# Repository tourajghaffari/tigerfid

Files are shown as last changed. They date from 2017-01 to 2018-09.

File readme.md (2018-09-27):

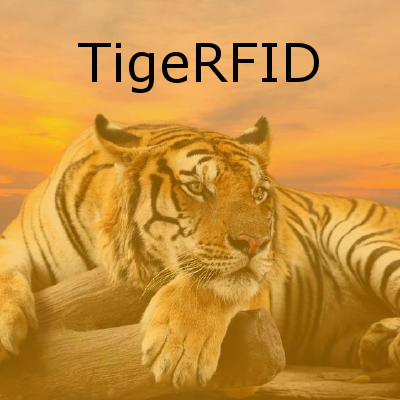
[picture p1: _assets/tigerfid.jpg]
TigeRFID

# TigeRFID

## Introduction

This repository has been created [in honor of our father](https://www.rfidjournal.com/articles/view?15751/), Touraj Ghaffari. He founded [ActiveWave, Inc.](http://www.activewaveinc.com/) in 2001. It was his life work and something he loved and enjoyed thoroughly. He also loved spreading knowledge. In honor of that principle, we, his three sons, have open-sourced everything associated with his active RFID system under the [Apache 2.0 license](license). We hope this release helps you acheive your dreams.

## What is this?

ActiveWave designed and built active RFID (Radio Frequency IDentification) products that work together to provide a new approach to tracking and security. The system includes the following features:

* Extended Read Range. A single RFID reader can cover up to 30,000 square feet of floor space.

* Multi-Tag Capability. Our tags employ anti-collision logic to assure each tag's information is read, even when multiple tags are attempting to transmit concurrently.

* Compact Low-Cost Design. Our exclusive design brings you the advantages of RFID technology, combined with long battery life and low cost.

* Simplified Installation. Our wireless device attachment capability simplifies the installation and interconnection of ActiveWave system components.

The [presentations](presentations) and [website](http://www.activewaveinc.com/) provide a great deal more detail - especially the [product datasheets](http://www.activewaveinc.com/products_datasheets.php).

## What is the project's current state?

This project is currently fully functional in its current state. The minimum system requirements are as follows:

1. One [Standard Reader](http://www.activewaveinc.com/products_datasht_standardreader.php) to both program the tags and read them.

2. At least one tag (the [sealTag](sealtag) and [compactTag](http://www.activewaveinc.com/products_datasht_compacttag.php) were the most popular).

3. Software options:

  1. Use the [API](api) to develop your own software; or,
  
  2. Use the [Programming Station](software/programming-station) to program tags and the [Smart Tracker](software/smart-tracker) to actually keep track of and monitor the tags.

The [Demo Kit](http://www.activewaveinc.com/products_datasht_demokit.php) included a few extra items: It included a [Standard Field Generator](http://www.activewaveinc.com/products_datasht_standardfieldgen.php) to demonstrate how to create zones within the range of the Reader as well as a motion detector to show how third-party devices can be integrated into the system as a whole through the use of the API.

## How can I get involved?

### Setup

1. Determine how you will configure your system. Remember the minimum system requirements listed above. As long as you have one Reader, one Tag, and either your own software using the [API](api) or the ActiveWave software suite ([Programming Station](software/programming-station) and [Smart Tracker](software/smart-tracker)), your system will work.

2. Use the [BOM files](bom-files) to figure out which parts you need.

3. Manufacture the parts using the [Protel files](protel-files). All the PCBs were designed using [Protel (now known as Altium)](http://www.altium.com/).

4. Share whatever improvements you make!

### Skillsets required

#### Software

* Programming with either C++ or C#

* Designing PCBs

#### Hardware

* Antenna design

* Radio frequency communication

* Soldering

### Assistance required

* We are looking for help to remove some of the old files. We included a few previous versions of each device in order to provide people with some history. We would like to remove all those older files and create a single-source-of-truth folder for each device.

* We are looking for help to improve documentation. In particular, we would like help to create a guide to stand-up a demo system based on the minimum requirements, a guide to manufacutre each device, and a guide to troubleshoot each device.

* We would like people's thoughts on whether the current structure is best or if it would be preferrable to have each device seperated out like the sealTag.

* We would like people's thoughts on the best way to display the BOMs. Should we convert them to markdown? Use a Google Sheet? Something else?

## Contents

1. [API](api) - Included are APIs for C++ .NET, C# .NET, C# .NET CE, and VB .NET. There is a manual for a Java-based API which we haven't yet found. There is also documentation - both for internal use and customers.

2. [BOM files](bom-files) - These are all the Bill Of Materials we could find. This should provide the different parts as well as costs associated with each based on the time they were made.

3. [Documentation](documentation) - These are documents, converted to Markdown, that were important enough for inclusion, but without a natural location that we could determine.

4. [Presentations](presentations) - These are the marketing materials that were sent to potential customers for a few different types of applications.

5. [Protel files](protel-files) - These are all the schematics and other related files that are required to actually manufacture the hardware.

6. [sealTag](sealtag) - One of the most versatile and popular tags of all, this was important enough to reside in its own section.

7. [Software](software) - This includes all the different applications required to actually run the system.

## Fun Touraj Fact

Touraj's favorite animal was the tiger - in particular, the [Caspian tiger](https://en.wikipedia.org/wiki/Caspian_tiger). Just like this project has arisen from extinction, the Caspian tiger should hopefully [make a triumphant return](http://www.bbc.co.uk/newsbeat/article/38663101/scientists-want-to-bring-cousin-of-extinct-caspian-tiger-to-central-asia) as well!

## Thank You

* Ali Amjadi

* Mehdi Haidari

* [Fabiano Kovalski](https://www.linkedin.com/in/fabianogk)

* [Vincent Mamo](https://www.linkedin.com/in/vincent-spinella-mamo-5262524)

* Reza Mokhtarzadeh

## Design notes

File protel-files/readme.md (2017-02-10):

# Protel Files

Using these files, you should be able to design the PCB associated with each device. Though this is probably the most important folder, we have never used Protel, so we are unsure as to the best way to provide you with some guidance. However, each folder should contain the schematics and files you need to begin manufacturing.

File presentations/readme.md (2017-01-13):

# Presentations

These are presentations that were used as educational materials to explain how the system worked.

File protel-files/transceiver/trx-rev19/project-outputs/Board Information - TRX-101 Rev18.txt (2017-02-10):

Board Information Report
Filename     : F:\PCBJOBS\ActiveWaveFiles May2009\TRX-101.REV18\PCB\TRX-101 Rev18.PcbDoc
Date         : 6/1/2009
Time         : 7:37:45 PM
Time Elapsed : 00:00:00

Plated Slot Size / Length, Pads
count : 0

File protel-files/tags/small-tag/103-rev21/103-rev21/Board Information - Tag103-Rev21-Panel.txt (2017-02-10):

Board Information Report
Filename     : C:\PCBJOBs\ActiveWave2010\Tag103.Rev21\Tag103-Rev21-Panel.PCB
Date         : 12/21/2010
Time         : 12:39:57 PM
Time Elapsed : 00:00:00

Routing Information
    Routing completion, 100.00%
    Connections, -44
    Connections routed, -44
    Connections remaing, 0
count : 4

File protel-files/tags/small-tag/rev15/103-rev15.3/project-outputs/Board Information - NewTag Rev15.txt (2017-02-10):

Board Information Report
Filename     : F:\PCBJOBS\ActiveWaveFiles 4-16-2008\Tag103 Rev15\Tag103 Rev15v3\NewTag Rev15.PCB
Date         : 4/30/2008
Time         : 9:52:25 PM
Time Elapsed : 00:00:00

Net Track Width, Count
    6mils, 42
count : 1

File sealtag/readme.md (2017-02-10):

# sealTag

This tag could be used for secure applications as well as any other application. It was the most popular tag of the group.

## Contents

### Host Software

This includes the software the host PC monitoring the sealTags will require.

### Protel Files

These are the files you'll need to use to actually create the PCB associated with the sealTag.

### Software

These are the applications as well as the firmware.

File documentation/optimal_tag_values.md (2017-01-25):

# Optimal Tag Values

**Note:** These are the values from testing each tag that resulted in an optimal result. We included the "Deprecated" portion in the event there was something from those old results that may be useful in the latest results. Eventually, we would hope to remove that sectionand leave only the latest optimal values.

## 868.92Mhz Tags

_05/12/2011_

### compactTag, 102 Rev 17

Variable | Value
--- | ---
C2 | 4.0pf
C7 | 220pf
C8 | 1000pf
C13 | 33pf
C19 | 3.0pf
C21 | 1.8pf or 2pf
L2 | 6.8nH
L4 | 12nH
L6 | 100nH
R17 | 1.3k ohms

### jumboTag, 105 Rev 17

Variable | Value
--- | ---
C2 | 2.2pf
C7 | 220pf
C8 | 1000pf
C13 | 33pf
C19 | 5.6pf
C21 | 1.8 or 2pf
L2 | 6.8nH or 8.2nH
L6 | 100nH
R17 | 1.3k ohms

### miniTag, Rev 20

Variable | Value
--- | ---
C2 | 2.4pf
C7 | 220pf
C13 | 33pf
C19 | 4.7pf
C21 | 1.8pf or 2pf
L1 | 15nH
L2 | 5.6nH
L6 | 100nH
R17 | 1.3k ohms
R24 | 150k ohms

## 867Mhz Tags (India)

_05/10/2011_

### compactTag, 102 Rev 17

Variable | Value
--- | ---
C2 | 4.0pf
C7 | 220pf
C8 | 10pf
C10 | 2700pf
C13 | 47pf
C19 | 3.0pf
C21 | 1.8pf or 2pf
L2 | 6.8nH
L4 | 12nH
L6 | 100nH
R17 | 1.3k ohms

### jumboTag, 105 Rev 17

Variable | Value
--- | ---
C2 | 2.2pf
C7 | 220pf
C8 | 1000pf
C10 | 1000pf
C13 | 33pf
C19 | 5.6pf
C21 | 6.0pf+
L2 | 6.8nH or 8.2nH
L6 | 100nH
R17 | 1.3k ohms

### miniTag, 103 Rev 20

Variable | Value
--- | ---
C2 | 2.4pf
C7 | 220pf
C8 | 10pf
C10 | 2700pf
C13 | 47pf
C19 | 4.7pf
C21 | 6pf or 7pf
L1 | 15nH
L2 | 5.6nH
L6 | 100nH
R17 | 1.3k ohms

## 916.5Mhz Tags

_05/12/2011_

### compactTag, 102 Rev 17

Variable | Value
--- | ---
C2 | 3.6pf
C7 | 220pf
C8 | 1000pf
C13 | 33pf
C19 | 2.7pf
C21 | 1.8pf or 2pf
L2 | 6.8nH
L4 | 12nH
L6 | 100nH
R17 | 1.3k ohms

### jumboTag, 105 Rev 17

Variable | Value
--- | ---
C2 | 2.7pf
C7 | 220pf
C8 | 1000pf
C13 | 33pf
C19 | 5.6pf
C21 | 1.8 or 2pf
L2 | 6.8nH or 8.2nH
L6 | 100nH
R17 | 1.3k ohms

### miniTag, Rev 20

Variable | Value
--- | ---
C2 | 1.5pf
C7 | 220pf
C8 | 1000pf
C13 | 33pf
C19 | 4.7pf
C21 | 1.8pf or 2pf
L2 | 5.6nH
L4 | 5.6nH
L6 | 100nH
R17 | 1.3k ohms
R24 | 150k ohms

## 927.2Mhz Tags

_05/12/2011_

### compactTag, 102 Rev 17

Variable | Value
--- | ---
C2 | 3.0pf
C7 | 220pf
C8 | 1000pf
C13 | 33pf
C19 | 2.4pf
C21 | 1.8pf or 2pf
L2 | 6.8nH
L4 | 12nH
L6 | 100nH
R17 | 1.3k ohms

### jumboTag, 105 Rev 17

Variable | Value
--- | ---
C2 | 2.7pf
C7 | 220pf
C8 | 1000pf
C13 | 33pf
C19 | 4.6pf
C21 | 1.8 or 2pf
L2 | 6.8nH or 8.2nH
L6 | 100nH
R17 | 1.3k ohms

### miniTag, 103 Rev 20

Variable | Value
--- | ---
C2 | 1.8pf
C7 | 220pf
C8 | 1000pf
C13 | 33pf
C19 | 3.0pf
C21 | 1.8pf or 2pf
L2 | 5.6nH
L4 | 5.6nH
L6 | 100nH
R17 | 1.3k ohms

## Special Notes

* **jumboTag and compactTag:** Add a 1M ohms resistor to the base of Q4 and the other side of the resistor goes to ground. This should increase the response time of the tag. Also, adding a 22uf cap - one side to the positive of the battery holder and the other side to ground - will increase the performance of the buzzer.

* **Tag 103:** To have a strong 433.92MHz signal, you need to change C7 from 100pf to 220pf (the change will get rid of the narrow signal) and L5 from 0.33uH to 100nH. For 868.92MHz tags, change C8 from 1000pf to 10pf and L1 to 15nH. For 916.5MHz and 868.92Mhz tags, change C19 to 4.7pf.

### Deprecated

#### 868.92MHz - cardTag, 101 Rev 13

Variable | Value
--- | ---
C2 | 2.7pf
C19 | 5.6pf
L2 | 6.8nH

#### 868.92MHz - jumboTag, 105 Rev 8

Variable | Value
--- | ---
C2 | 2.2pf
C7 | 220pf
C19 | 5.6pf
L2 | 6.8nH or 8.2nH
L6 | 100nH

#### 868.92MHz - miniTag, 103 Rev 8

Variable | Value
--- | ---
C2 | 1.8pf
C19 | 4.7pf
L1 | 2.7nH
L2 | 5.6nH

#### 916.5MHz - cardTag. 101

Variable | Value
--- | ---
C2 | 2.7pf
C19 | 5.6pf
L2 | 6.8nH

#### 916.5MHz - compactTag, 102

Variable | Value
--- | ---
C2 | 4.0pf
C19 | 3.0pf
L2 | 6.8nH
L4 | 12nH

#### 916.5MHz - jumboTag, 105

Variable | Value
--- | ---
C2 | 2.7pf
C7 | 220pf
C19 | 5.6pf
C21 | 1.8pf
L2 | 6.8nH or 8.2nH
L6 | 100nH

#### 916.5MHz - miniTag, Rev 8

Variable | Value
--- | ---
C2 | 2.7pf
C19 | 3.6pf
L1 | 2.7nH
L2 | 4.7nH

#### Special Notes

* **For tag 103 and metal surfaces:** Changing C2 from 2.7pf to 2.0pf, C19 from 3.6pf to 5.6pf, and L2 from 4.7nH to 5.6nH, the tag can work on metal with a wristband and it also increases the read range of the tag.

* **For tag 103 and a narrow signal:** Changing C7 from 100pf to 220pf, L6 from .33uH to 100nH, L1 to 15nH, while on 868.92Mhz, changing C8 to 10pfz, will allow you to have a strong 433.92 signal. It will also get rid of the narrow signal from receiver and give you a better and nicer shaped signal.

* **Reducing noise levels:** If you ever have a noise issue, adjust the threshold on R11 to reduce the noise level so we do not have any distraction from the Reader.

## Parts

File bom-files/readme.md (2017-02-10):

# BOM Files

This folder contains the most up-to-date Bill of Materials (BOM) files we could find. Each directory contains the BOM files we found associated with that particular device.

## Contents

### BOM Cost

These are the actual labor and parts costs associated with building each device.

### Compact Flash

These are the BOM files for the CF Reader. This device wasn't used towards the end of my father's life, so it may need some updating to work with the latest version of the other devices.

### Field Generator

These are the BOM files for each FGen, which operate as a repeater or extender (depending on how you configure your system).

### Handheld

These are the BOM files for the Handheld Reader devices. Much like the CF Reader, this may be best used with older versions of the tags and other readers.

### Misc

These are random BOM files we found in the root folder and are unsure as to whether they are the latest versions or not.

### Reader

These are the BOM files for the Readers. The medium-reader is most likely the best one to use as it was the most popular, but the standard-old-reader was used a bit as well.

### Tag

These are the BOMs for all the tags, including options.

### Transceiver

Unfortunately, we're not 100% sure what this is, but we know it is important. We believe it is something that must be built into the Readers, but again, we are unsure.

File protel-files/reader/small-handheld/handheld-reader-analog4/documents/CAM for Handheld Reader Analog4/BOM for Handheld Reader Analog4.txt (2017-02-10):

Bill Of Material For Handheld Reader Analog4.PCB
On 17-Sep-2004 at 15:36:35

 Comment             Pattern     Quantity  Components
------------------------------------------------------------------------------

 .001uF              0603             1    C41

 .1uF                0603            14    C2, C4, C5, C7, C8, C13, C14,
                                           C17, C18, C22, C26, C48, C50,
                                           C51

 .5 pF               0603             1    C20

 0.001uF             0603             1    C16

 0.18uH              0603             2    L6, L14

 0.22uF              0603             1    C15

 10                  0603             1    R16

 10 pF               0603             2    C30, C45

 10.7 Mhz Filter     FILTER           2    Y1, Y2

 100 nH              0603             2    L8, L11

 100 pF              0603             8    C6, C21, C27, C32, C34, C36,
                                           C44, C47

 100K                0603             2    R10, R31

 10K                 0603             4    R12, R38, R41, R49

 10uF                CAP A CASE       4    C10, C12, C52, C53

 150K                0603             1    R9

 15K                 0603             1    R47

 15nH                0603             1    L12

 18 nH               0603             1    L2

 180                 0603             1    R29

 1K                  0603             5    R8, R18, R26, R37, R48

 1N914               SOT23 DIODE      1    D1

 1X3 HEADER          1X3 HEADER       1    J4

 1uF                 CAP A CASE       1    C25

 2 pF                0603             1    C33

 2.2 mH              COIL 6.8UH       1    L4

 2.2K                0603             2    R21, R46

 22                  0603             4    R3, R20, R33, R43

 220 K               0603             1    R17

 27 pF               0603             1    C1

 2N3904              SOT23 TRANS      4    Q3, Q7, Q8, Q10

 2N3906              SOT23 TRANS      2    Q2, Q9

 3 pF                0603             1    C43

 3.3K                0603             1    R25

 33 nH               0603             1    L9

 33 pF               0603             3    C11, C19, C42

 330                 0603             1    R2

 330 nH              0805             1    L7

 39K                 0603             2    R15, R36

 3K                  0603             1    R24

 4.7K                0603             7    R14, R19, R22, R35, R40, R42,
                                           R51

 4.7nH               0603             1    L1

 433.92_Resonator    RESONATOR        1    Y4

 47 nH               0603             1    L10

 47 pF               0603             6    C28, C29, C37, C38, C39, C40

 470                 0603             1    R4

 4pF                 0603             1    C23

 5 PF                0603             1    C31

 5 pF                0603             1    C3

 56                  0603             1    R1

 560                 0603             2    R7, R27

 56K                 0603             1    R50

 5K POT              POT PANA EVN5     2    R6, R11

 5pF                 0603             1    C9

 6 pF                0603             1    C46

 6.8 nH              0603             1    L15

 6.8 uH              0805             1    L3

 6.8K                0603             2    R13, R34

 6.8k                0603             1    R23

 68                  0603             2    R30, R39

 7 PF                0603             1    C35

 905.8_Resonator     RESONATOR        1    Y3

 916.5_MHz Saw FilterRESONATOR        1    Y5

 916.5_Resonator     RESONATOR        1    Y6

 AT-113              SO8              1    U6

 BAR 65              DIODE SC79       1    D3

 BFR193              SOT23 TRANS      2    Q4, Q5

 BGA2001             SOT343           1    U1

 CON10               1X10 HEADER SPECIAL     1    J3

 CONN NEARSON NC-K01 CONN NEARSON NC-K01     2    J5, J6

 DS1804              SO8 SMALL        1    U5

 LMC555              SO8 SMALL        1    U9

 LMV821              SOT25            2    U4, U8

 Microstrip          MICROSTRIP       2    L5, L13

 NE85619             3 PIN ULTRA SUPER MINI MOLD     2    Q1, Q6

 SA636DK             SSOP20           1    U2

 TLV1391             SOT25            1    U3

 UPG52TA             TO6              1    U7

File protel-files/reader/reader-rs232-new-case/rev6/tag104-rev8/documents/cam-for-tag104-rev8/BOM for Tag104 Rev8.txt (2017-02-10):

Bill Of Material For Tag104 Rev8.PCB
On 29-Jul-2005 at 12:22:31

 Comment             Pattern     Quantity  Components
------------------------------------------------------------------------------

 0.1 uF              0603             4    C1, C15, C17, C24

 0.18 uH             0603             1    L3

 0.33 uH             0603             1    L6

 1 K                 0603             1    R20

 1 M                 0603             2    R1, R2

 10                  0603             2    R12, R13

 10 pF               0603             1    C4

 100 pF              0603             2    C6, C7

 1000 pF             0603             4    C8, C9, C10, C11

 1K                  0603             1    R21

 2 pF +/- .1 pf      0603             3    C2, C3, C21

 2.7 K               0603             2    R17, R18

 200                 0603             1    R22

 22                  0603             1    R6

 24AAXX              SO8              1    U4

 2N7002              SOT23 TRANS      1    Q4

 2N7002LT1           SOT23 TRANS      1    Q3

 3.3 nH              0603             1    L2

 33 pF               0603             1    C12

 33 pF +/- .1 pf     0603             1    C13

 330                 0603             1    R15

 39 K                0603             5    R3, R4, R5, R9, R10

 4.7 K               0603             2    R8, R19

 4.7 uF              CAP A CASE       1    C20

 470                 0603             1    R14

 470 K               0603             1    R16

 5 pF +/- .1 pF      0603             1    C19

 6.8 K               0603             1    R7

 68                  0603             1    R11

 916.5_Resonator     RESONATOR        1    Y1

 A3212               SOT23W           1    U7

 BATT HOLDER COIN CR2BATT HOLDER COIN CR2032 CUT     1    B1A

 DNS                 0603             2    C22, C23

 LED                 LED 0603         1    D1

 MIC862              SOT23-8          1    U6

 NE85619             3 PIN ULTRA SUPER MINI MOLD     2    Q1, Q2

 PIC16F648A          SSOP20 WIDE      1    U1

 TC1070              SOT23-5A         1    U5

 TC54                SOT23            1    U2

 TP                  TEST POINT PAD 5     4    J7, J9, J10, J11

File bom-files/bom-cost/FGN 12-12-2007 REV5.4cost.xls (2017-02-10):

FGN ASM-Sen-05.4
12/12/2007
Field Generator Rev 5.3
Item # |  | Part Status | Qty. | Price | Extended Cost | Labor Cost | Total Cost | Part Ref. | Value | Part Size | Description | Dist. | Distributor P/N | Manufacturer | Manufacturer P/N | Notes | Revision
1 |  | Basic | 1 | 0.011 | 0.014 | 0.080 | 0.094 | C31 | 100pF | 0603 | CAP 100PF 50V CERAMIC | Digi-Key | 445-1281-2-ND | TDK Corp | C1608C0G1H101J |  | 5.2
2 |  | Basic | 6 | 0.005 | 0.036 | 0.480 | 0.516 | C13, C21, C27, C28, C29, C30 | 0.1 uF | 0603 | CAP .10UF 25V CERAMIC Y5V 0603 | Digi-Key | 399-1100-2-ND | Kemet | C0603C104Z3VACTU |  | 5.2
3 |  | Basic | 2 | 0.057 | 0.137 | 0.160 | 0.297 | C11, C16 | 2.2uF 16V | CT3216 | CAPACITOR TANT 2.2UF 16V 10%, CASE A, SMD | Digi-Key | 399-3691-2-ND | Kemet | T491A225K016AT |  | 5.2
4 |  | Basic | 2 | 0.050 | 0.120 | 0.160 | 0.280 | C1, C2 | 4.7uF 16V | CT3216 | CAPACITOR TANT 4.7UF 16V 10%, CASE A, SMD | Digi-Key | 399-3697-2-ND | Kemet | T491A475K016AT |  | 5.2
5 |  | Basic | 1 | 0.015 | 0.018 | 0.080 | 0.098 | R29 | 33 | 0603 | RES 33 OHM 1/10W 5% | Digi-Key | RHM33GTR-ND | Rohm | MCR03EZPJ330 |  | 5.2
6 |  | Basic | 1 | 0.016 | 0.019 | 0.080 | 0.099 | R6 | 133 | 0603 | RES 133 OHM 1/10W 1% 0603 SMD | Digi-Key | RHM133HTR-ND | Rohm | MCR03EZPFX1330 |  | 5.2
7 |  | Basic | 3 | 0.001 | 0.005 | 0.240 | 0.245 | R8, R10, R14 | 2.2K | 0603 | RES 2.2K OHM 1/10W 5% 0603 SMD | Digi-Key | RHM2.2KGTR-ND | Rohm | MCR03EZPJ222 |  | 5.2
8 |  | Basic | 2 | 0.001 | 0.003 | 0.160 | 0.163 | R15,R21 | 10K | 0603 | RES 10K OHM 1/10W 5% 0603 SMD | Digikey | RHM10KGTR-ND | Rohm | MCR03EZPJ103 |  | 5.2
9 |  | Basic | 2 | 0.080 | 0.192 | 0.160 | 0.352 | FB2, FB3 | Ferrite Bead | 0603 | BEAD CORE 27 OHM 4A 0603 SMD | Digi-Key | P10436CT-ND | Panasonic-ECG | EXC-ML16A270U |  | 5.2
9 |  | Basic | 1 | 0.048 | 0.057 | 0.080 | 0.137 | L8 | 100nH | 0603 | INDUCTOR 100NH 5% 0603 SMD | Digi-Key | PCD1985TR-ND | Panasonic-ECG | ELJ-RER10JFA |  | 5.2
10 |  | Basic | 1 | 0.124 | 0.149 | 0.080 | 0.229 | D5 | Red LED | LED-T1 3mm | LED, RADIAL | Ptec | PL01CDR24 | Ptec | PL01CDR24 |  | 5.2
 |  |  |  |  | 0.000 | 0.000 | 0.000 |  |  | LED-T1 3mm | LED RED DIFFUSED 3MM ROUND | Digi-Key | P563-ND | Panasonic | LN28RPX |  | 5.2
11 |  | Basic | 1 | 0.300 | 0.359 | 0.080 | 0.439 | D4 | TRANSORB | DO-214AA (SMB) | SIDACTOR BI 25V 150A DO-214AA | Digi-Key | P0300SALRPTR-ND | Teccor Electronics Inc. (Sidactor) (http://www.digikey.com/scripts/Redirect/Redirect.dll?R=9&V=53) | P0300SALRP |  | 5.3
12 |  | Basic | 1 | 0.139 | 0.166 | 0.080 | 0.246 | D2 | Green LED | LED-T1 3mm | LED, RADIAL | Ptec | PL01-CDG-13 | Ptec | PL01-CDG-13 |  | 5.2
 |  |  |  |  | 0.000 | 0.000 | 0.000 |  |  | LED-T1 3mm | LED GREEN DIFFUSED 3MM ROUND | Digikey | P564-ND | Panasonic | LN38GPX |  | 5.2
13 |  | Basic | 1 | 0.054 | 0.065 | 0.080 | 0.145 | D6 | 1N4148 | SOD123 | DIODE SWITCH 75V 500MW MINIMELF | Digi-Key | LL4148DICT-ND | Diodes, Inc. | LL4148-13 |  | 5.2
14 |  | Basic | 1 | 0.144 | 0.172 | 0.080 | 0.252 | D12 | S1AB | DO-214AA (SMB) | DIODE FAST REC 50V 1A SMB | Digi-Key | RS1AB-FDITR-ND | Diodes, Inc. | RS1AB-13-F |  | 5.2
15 |  | Basic | 1 | 0.045 | 0.054 | 0.080 | 0.134 | Q1 | 2N3906 | SOT-23 | TRANS GP PNP -40V -200MA SOT-23 | Digi-Key | FMMT3906TR-ND | Zetex, Inc. | FMMT3906TA |  | 5.2
16 |  | Basic | 1 | 0.045 | 0.054 | 0.080 | 0.134 | Q3 | 2N3904 | SOT-23 | TRANS GP NPN 40V 200MA SOT-23 | Digi-Key | FMMT3904TR-ND | Zetex, Inc. | FMMT3904TA |  | 5.2
17 |  | Basic | 1 | 0.193 | 0.231 | 0.080 | 0.311 | U1 | NCP1117-ST50T3 | SOT223 | IC REG LDO 1A 5.0V SOT223 | Digi-key | NCP1117ST50T3GOS-ND | On Semiconductor | NCP1117ST50T3G |  | 5.2
18 |  | Basic | 1 | 0.700 | 0.838 | 0.080 | 0.918 | U5 | PIC16F690 | 20SSOP | IC MCU FLASH 4KX14 EEPROM | Digi-Key | PIC16F690-I/SS-ND | Microchip | PIC16F690-I/SS |  | 5.2
19 |  | Basic | 1 | 1.563 | 1.872 | 0.080 | 1.952 | U6 | MAX202 | SO-16 | IC TRANSCEIVER RS232 5V 16-SOIC | Arrow | MAX202CSE | Maxim | MAX202CSE |  | 5.2
20 |  | Basic | 0 |  | 0.000 | 0.000 | 0.000 | J3,J6 | DNP |  | 1x5 Header |  |  |  |  | Mask the HOLES | 5.2
21 |  | Basic | 1 | 2.113 | 2.531 | 0.080 | 2.611 | J4 | RJ11 | 6-6 modular | CONN MODULE 6-6 UNSHIELD SLEEVE | Digi-Key | CCM9002-ND | Corcom/Tyco | RJ11-6L-S | Please mask J6 holes | 5.2
22 |  | Basic | 1 | 1.410 | 1.689 | 0.080 | 1.769 | PCB |  |  |  |  |  | Active PCB | FGN-RAW-REV5 |  | 5.2
23 |  | Basic | 2 | 0.020 | 0.048 | 0.160 | 0.208 | Screw |  |  | SHEET MTL SCREW NO. 4 X 1/2"L, FLAT HD PHIL, ZINC PLTD STEEL |  |  | McMaster | 90048A110 |  | 5.2
24 |  | Basic | 1 |  | 0.000 | 0.080 | 0.080 | J9 | CONN HEADER RT ANG 2POS | 3.5mm | MC1,5/2-G-3,5 | Sager | 52285 | Phoenix Contact | 1844210 |  | 5.2
25 |  | Basic | 1 | 0.336 | 0.402 | 0.080 | 0.482 | J9A | Screw Type Plug 2POS | 3.5mm | MC1,5/2-ST-3,5 | Sager | 52229 | Phoenix Contact | 1840366 |  | 5.2
26 |  | Basic | 1 | 1.030 | 1.234 | 0.080 | 1.314 | F1 | 0451.200MRL | Surface Mount (0.240 X 0.106) | FUSE .200A 125V FAST NANO2 SMD | Digi-Key | 0451.200MRL-ND | Littelfuse Inc | 0451.200MRL |  | 5.2
 |  | Total |  | 8.500 | 10.463 | 3.040 | 13.503
27 | OPTD-0 | 433 MHZ | 0 |  | 0.000 | 0.000 | 0.000 | C3,C5,C6,C7,C8,C9,C10,C12,C14,C15,C18,C19,C20,C37,R1,R2,R3,R4,R5,R7,R9,R11,R17,R18,R19,R20,R22,L1,L2,L3,L4,L9,L10,L11,Q2,Q4,Q5,Q6,U2,Y2,J5,J8 | DNP |  |  |  |  |  |  |  | 5.2
28 | OPTD-1 | 433 MHz | 1 | 0.016 | 0.020 | 0.080 | 0.100 | C8 | 2.0 pF | 0603 | CAP CER 2.0PF, +/-0.25PF 50V C0G 0603 | Digi-Key | 490-1379-2-ND | Murata | GRM1885C1H2R0CZ01D |  | 5.2
29 | OPTD-1 | 433 MHz | 1 | 0.016 | 0.020 | 0.080 | 0.100 | C37 | 3.0 pF | 0603 | CAP CER 3.0PF,+/-0.25PF, 50V C0G 0603 | Digi-Key | 490-1383-2-ND | Murata | GRM1885C1H3R0CZ01D |  | 5.2
30 | OPTD-1 | 433 MHz | 2 | 0.016 | 0.039 | 0.160 | 0.199 | C19,C10 | 5.0 pF | 0603 | CAP CER 5.0PF, +/-0.25PF, 50V C0G 0603 | Digi-Key | 490-1390-2-ND | Murata | GRM1885C1H5R0CZ01D |  | 5.2
31 | OPTD-1 | 433 MHz | 1 | 0.016 | 0.020 | 0.080 | 0.100 | C14 | 7.0pF | 0603 | CAP CER 7.0PF, +/-0.5PF 50V C0G 0603 | Digi-Key | 490-1397-2-ND | Murata | GRM1885C1H7R0DZ01D |  | 5.2
32 | OPTD-1 | 433 MHz | 1 | 0.016 | 0.020 | 0.080 | 0.100 | C15 | 10pF | 0603 | CAP CER 10PF 50V 5% C0G 0603 | Digi-Key | 490-1403-2-ND | Murata | GRM1885C1H100JA01D |  | 5.2
33 | OPTD-1 | 433 MHz | 4 | 0.008 | 0.038 | 0.320 | 0.358 | C9 | 47pF | 0603 | CAP CER 47PF 50V C0G 5% 0603 | Digi-Key | 445-1277-2-ND | TDK Corp | C1608C0G1H470J |  | 5.2
34 | OPTD-1 | 433 MHz | 5 | 0.008 | 0.047 | 0.400 | 0.447 | C3, C5, C6, C7,C18 | 100pF | 0603 | CAP 100PF, 5%, 50V, COG, CERAMIC | Digi-Key | 445-1281-2-ND | TDK Corp | C1608C0G1H101J |  | 5.2
35 | OPTD-1 | 433 MHz | 1 | 0.005 | 0.006 | 0.080 | 0.086 | C20 | 0.1uF | 0603 | CAP .10UF 25V -20%, +80% CERAMIC Y5V 0603 | Digi-Key | 399-1100-2-ND | Kemet | C0603C104Z3VACTU |  | 5.2
36 | OPTD-1 | 433 MHz | 1 | 0.050 | 0.060 | 0.080 | 0.140 | C12 | 4.7uF 16V | CT3216 | CAPACITOR TANT 4.7UF 16V 10%, CASE A, SMD | Digi-Key | 399-3697-2-ND | Kemet | T491A475K016AT |  | 5.2
37 | OPTD-1 | 433 MHz | 1 | 0.015 | 0.018 | 0.080 | 0.098 | R17 | 10 | 0603 | RES 10 OHM 1/10W 5% 0603 SMD | Digi-Key | RHM10GTR-ND | Rohm | MCR03EZPJ100 |  | 5.2
38 | OPTD-1 | 433 MHz | 1 | 0.015 | 0.018 | 0.080 | 0.098 | R7 | 22 | 0603 | RES 22 OHM 1/10W 5% | Digi-Key | RHM22GTR-ND | Rohm | MCR03EZPJ220 |  | 5.2
39 | OPTD-1 | 433 MHz | 1 | 0.015 | 0.018 | 0.080 | 0.098 | R20 | 180 | 0603 | RES 180 OHM 1/10W 5% 0603 SMD | Digikey | RHM180GTR-ND | Rohm | MCR03EZPJ181 |  | 5.2
40 | OPTD-1 | 433 MHz | 1 | 0.001 | 0.002 | 0.080 | 0.082 | R22 | 270 | 0603 | RES 270 OHM 1/10W 5% 0603 SMD | Digikey | RHM270GTR-ND | Rohm | MCR03EZPJ271 |  | 5.2
41 | OPTD-1 | 433 MHz | 1 | 0.015 | 0.018 | 0.080 | 0.098 | R5 | 470 | 0603 | RES 470 OHM 1/10W 5% 0603 SMD | Digikey | RHM470GTR-ND | Rohm | MCR03EZPJ471 |  | 5.2
42 | OPTD-1 | 433 MHz | 1 | 0.015 | 0.018 | 0.080 | 0.098 | R11 | 1K | 0603 | RES 1.0K OHM 1/10W 5% 0603 SMD | Digikey | RHM1.0KGTR-ND | Rohm | MCR03EZPJ102 |  | 5.2
43 | OPTD-1 | 433 MHz | 1 | 0.015 | 0.018 | 0.080 | 0.098 | R4 | 2.2K | 0603 | RES 2.2K OHM 1/10W 5% 0603 SMD | Digi-Key | RHM2.2KGTR-ND | Rohm | MCR03EZPJ222 |  | 5.2
44 | OPTD-1 | 433 MHz | 1 | 0.015 | 0.018 | 0.080 | 0.098 | R18 | 3.3K | 0603 | RES 3.3K OHM 1/10W 5% 0603 SMD | Digi-Key | RHM3.3KGTR-ND | Rohm | MCR03EZPJ332 |  | 5.2
45 | OPTD-1 | 433 MHz | 1 | 0.001 | 0.002 | 0.080 | 0.082 | R19 | 1.8k | 0603 | RES 1.8K OHM 1/10W 5% 0603 SMD | Digi-Key | RHM1.8KGTR-ND | Rohm | MCR03EZPJ182 |  | 5.2
46 | OPTD-1 | 433 MHz | 2 | 0.015 | 0.035 | 0.160 | 0.195 | R1, R2 | 4.7K | 0603 | RES 4.7K OHM 1/10W 5% 0603 SMD | Digi-Key | RHM4.7KGTR-ND | Rohm | MCR03EZPJ472 |  | 5.2
47 | OPTD-1 | 433 MHz | 1 | 0.003 | 0.004 | 0.080 | 0.084 | R3 | 8.2k | 0603 | RES 8.2K OHM 1/10W 5% 0603 SMD | Digi-Key | RHM8.2KGTR-ND | Rohm | MCR03EZPJ822 |  | 5.2
48 | OPTD-1 | 433 MHz | 1 | 0.563 | 0.674 | 0.080 | 0.754 | R9 | 10K POT | 9mm Squared | POT 10K OHM SQ CERMET SIDE | Digi-Key | CT94EZ103-ND | copal-electronics | CT94EZ103 |  | 5.2
49 | OPTD-1 | 433 MHz | 2 | 0.034 | 0.081 | 0.160 | 0.241 | L1,L11 | 6.8nH | 0603 | INDUCTOR 6.8NH 5% 0603 SMD | Digi-Key | PCD1971TR-ND | Panasonic | ELJ-RE6N8JFA |  | 5.2
50 | OPTD-1 | 433 MHz | 1 | 0.048 | 0.057 | 0.080 | 0.137 | L4 | 22nH | 0603 | INDUCTOR 22NH 5% 0603 SMD | Digi-Key | PCD1977TR-ND | Panasonic | ELJ-RE22NJFA |  | 5.2
51 | OPTD-1 | 433 MHz | 1 | 0.048 | 0.057 | 0.080 | 0.137 | L9 | 47nH | 0603 | INDUCTOR 47NH 5% 0603 SMD | Digi-Key | PCD1981TR-ND | Panasonic-ECG | ELJ-RE47NJFA |  | 5.2
52 | OPTD-1 | 433 MHz | 2 | 0.034 | 0.081 | 0.160 | 0.241 | L2,L3 | 100nH | 0603 | INDUCTOR 100NH 5% 0603 SMD | Digi-Key | PCD1985TR-ND | Panasonic-ECG | ELJ-RER10JFA |  | 5.2
53 | OPTD-1 | 433 MHz | 1 | 0.170 | 0.204 | 0.080 | 0.284 | L10 | 330nH | 0603 | INDUCTOR MULTILAYER 0.33UH 1608 | Digi-Key | 445-1009-2-ND | TDK Corporation | MLF1608DR33K |  | 5.3
54 | OPTD-1 | 433 MHz | 1 | 0.045 | 0.054 | 0.080 | 0.134 | Q4 | 2N3906 | SOT-23 | TRANS GP PNP -40V -200MA SOT-23 | Digi-Key | FMMT3906TR-ND | Zetex, Inc. | FMMT3906TA |  | 5.2
55 | OPTD-1 | 433 MHz | 2 | 0.120 | 0.287 | 0.160 | 0.447 | Q2,Q6 | BFR193 | SOT23 | TRANSISTOR RF NPN 12V SOT-23 | Digi-Key | BFR 193 E6327-ND | Infineon | BFR 193 E6327 |  | 5.2
56 | OPTD-1 | 433 MHz | 1 | 0.045 | 0.054 | 0.080 | 0.134 | Q5 | 2N3904 | SOT-23 | TRANS GP NPN 40V 200MA SOT-23 | Digi-Key | FMMT3904TR-ND | Zetex, Inc. | FMMT3904TA |  | 5.2
57 | OPTD-1 | 433 MHz | 1 |  | 0.000 | 0.080 | 0.080 | U2 | AT-113 | SO8 | 3 Volt Voltage Variable Absorptive Attenuator | Future | 6219539 | MCM | AT-113TR |  | 5.2
58 | OPTD-1 | 433 MHz | 1 | 0.520 | 0.623 | 0.080 | 0.703 | Y2 | 433.92MHz | 3.8 X 3.8 MM | 40 dB, 0.5-2.0 GHz | RF Monolithics | RO2101D | RF Monolithics | RO2101D |  | 5.2
59 | OPTD-1 | 433 MHz | 2 | 0.056 | 0.133 | 0.160 | 0.293 | Shunt (J5,J8) | 2 Position |  | SHUNT, ECON, PHBR 5AU, BLACK | Digi-Key | A26228-ND | AMP/Tyco | 382811-8 |  | 5.2
60 | OPTD-1 | 433 MHz | 1 | 0.663 | 0.794 | 0.080 | 0.874 | J5 | 1X3 Header |  | CONN HEADER .100 SINGL STR 36POS | Digi-Key | S1011E-36-ND | Sullins Elec. | PBC36SAAN | One of these Sullins parts makes 12 3-pin headers | 5.2
61 | OPTD-1 | 433 MHz | 1 | 0.663 | 0.794 | 0.080 | 0.874 | J8 | 1X2 Header |  | CONN HEADER .100 SINGL STR 36POS | Digi-Key | S1011E-36-ND | Sullins Elec. | PBC36SAAN | One of these Sullins parts makes 18 2-pin headers | 5.2
 |  | Total |  | 3.283 | 4.327 | 3.760 | 8.087
62 | OPTD-1 | OPTM-2 | 1 |  | 0.000 | 0.080 | 0.080 | Enclouser | Box-ENC-102-2110100 |  | Box 12cm x 6.9cm x 2.5cm, Black Color, ActiveWave Logo,Hole in Top Left Position Option, Hole in Top Right, Hole on Left Side,No Two Ultrasonic holes on the Top Right, No hole on the Right Side |  |  | Advanced Data Access Inc/ ActiveWave Inc | Box-ENC-102-2110100 |  | 5.2
63 | OPTD-1 | OPTM-3 | 1 |  | 0.000 | 0.080 | 0.080 | Enclouser | Box-ENC-102-3110100 |  | Box 12cm x 6.9cm x 2.5cm, Silver Color, ActiveWave Logo,Hole in Top Left Position Option, Hole in Top Right, Hole on Left Side,No Two Ultrasonic holes on the Top Right, No hole on the Right Side |  |  | Advanced Data Access Inc/ ActiveWave Inc | Box-ENC-102-3110100 |  | 5.2
64 | OPTD-1 | OPTM-4 | 1 |  | 0.000 | 0.080 | 0.080 | Enclouser | Box-ENC-102-4110100 |  | Box 12cm x 6.9cm x 2.5cm, Beige Color, ActiveWave Logo,Hole in Top Left Position Option, Hole in Top Right, Hole on Left Side,No Two Ultrasonic holes on the Top Right, No hole on the Right Side |  |  | Advanced Data Access Inc/ ActiveWave Inc | Box-ENC-102-4110100 |  | 5.2
65 | OPTD-1 | OPTM-5 | 1 |  | 0.000 | 0.080 | 0.080 | Enclouser | Box-ENC-102-5110100 |  | Box 12cm x 6.9cm x 2.5cm, Custom Color, ActiveWave Logo,Hole in Top Left Position Option, Hole in Top Right, Hole on Left Side,No Two Ultrasonic holes on the Top Right, No hole on the Right Side |  |  | Advanced Data Access Inc/ ActiveWave Inc | Box-ENC-102-5110100 |  | 5.2
 |  |  |  |  | 0.000 | 0.000 | 0.000 |  |  |  |  |  |  |  |  |  | 5.2
66 | OPTE-0 | 433-EXT-ANT | 0 |  | 0.000 | 0.000 | 0.000 | J7 | DNP |  |  |  |  |  |  |  | 5.2
67 | OPTE-1 | 433-EXT-ANT | 1 | 2.087 | 2.500 | 0.080 | 2.580 | J7 | PCB Mount | SMA Reverse | CONNECTOR RPSMA PCB MOUNT | Digi-Key | CONREVSMA001-ND | Linx Tech. | CONREVSMA001 |  | 5.2
68 | OPTE-1 | 433-EXT-ANT | 1 | 5.220 | 6.251 | 0.080 | 6.331 | J7-Antenna | 50 OHM ANT | SMA Reverse | ANTENNA 433MHZ 1/4 WAVE WHIP | Digi-Key | ANT-433-CW-HD-ND | Linx Tech. | ANT-433-CW-HD | OPTION J-3 OR OPTION K-3? | 5.2
 |  | total |  | 7.307 | 8.751 | 0.160 | 8.911 |  |  |  |  |  |  |  |  |  | 5.2
69 | OPTF-0 | INT Sensor | 0 |  | 0.000 | 0.000 | 0.000 | C54,C55,C56,C57,C58,C59,C60,C61,C62,R13,R47,R51,R54,R55,R57,R58,L16,L17,Q7,U3,SEN1,SEN2,P1,P2,J1 | DNP |  |  |  |  |  |  |  | 5.3
70 | OPTF-1 | INT Sensor | 1 | 0.011 | 0.014 | 0.080 | 0.094 | C55 | 47pF | 0603 | CAP CER 47PF 50V C0G 5% 0603 | Digi-Key | 445-1277-2-ND | TDK Corp | C1608C0G1H470J |  | 5.2
71 | OPTF-1 | INT Sensor | 1 | 0.011 | 0.013 | 0.080 | 0.093 | C58 | 0.01uF | 0603 | CAP CERM .01UF 10% 50V X7R 0603 | Digi-Key | 478-1227-2-ND | AVX Corporation (http://www.digikey.com/scripts/Redirect/Redirect.dll?R=9&V=478) | 06035C103KAT2A |  | 5.2
72 | OPTF-1 | INT Sensor | 3 | 0.005 | 0.018 | 0.240 | 0.258 | C56,C57,C62 | 0.1uF | 0603 | CAP .10UF, -20/+80%, 25V ,CERAMIC Y5V 0603 | Digi-Key | 399-1100-2-ND | Kemet | C0603C104Z3VACTU |  | 5.2
73 | OPTF-1 | INT Sensor | 2 | 0.018 | 0.043 | 0.160 | 0.203 | C54,C61 | 1 uF 50V | 0805 | CAP CER 1UF, -20/+80%, 50V Y5V 0805 | Digi-Key | 490-3903-2-ND | Murata | GRM21BF51H105ZA12L |  | 5.2
74 | OPTF-1 | INT Sensor | 1 | 0.135 | 0.162 | 0.080 | 0.242 | C59 | 100uF 16V | 7343-31 (EIA) | CAP TANT 100UF 16V 10% SMD CASE D SMD | Digi-Key | 718-1057-2-ND | Vishay | 293D107X9016D2TE3 |  | 5.2
75 | OPTF-1 | INT Sensor | 1 | 0.001 | 0.002 | 0.080 | 0.082 | R13 | 1K | 0603 | RES 1.0K OHM 1/10W 5% 0603 SMD | Digikey | RHM1.0KGTR-ND | Rohm | MCR03EZPJ102 |  | 5.2
76 | OPTF-1 | INT Sensor | 4 | 0.015 | 0.070 | 0.320 | 0.390 | R54,R55,R57,R58 | 1K | 1206 | RES 1.0K OHM 1/4W 5% 1206 SMD | Digikey | RHM1.0KETR-ND | Rohm | MCR18EZHJ102 |  | 5.2
77 | OPTF-1 | INT Sensor | 1 | 0.015 | 0.018 | 0.080 | 0.098 | R47 | 4.7K | 0603 | RES 4.7K OHM 1/10W 5% 0603 SMD | Digi-Key | RHM4.7KGTR-ND | Rohm | MCR03EZPJ472 |  | 5.2
78 | OPTF-1 | INT Sensor | 1 | 0.563 | 0.674 | 0.080 | 0.754 | R51 | 100K | 0603 | RES 100K OHM 1/10W 5% 0603 SMD | Digi-Key | RHM100KGCT-ND | Rohm | MCR03EZPJ104 |  | 5.2
79 | OPTF-1 | INT Sensor | 2 | 0.563 | 1.349 | 0.160 | 1.509 | L16,L17 | Ferrite Bead | 0603 | BEAD CORE 27 OHM 4A 0603 SMD | Digi-Key | P10436CT-ND | Panasonic-ECG | EXC-ML16A270U |  | 5.3
80 | OPTF-1 | INT Sensor | 1 | 0.001 | 0.002 | 0.080 | 0.082 | Q7 | FMMT491ATC | SOT-23 | TRANSISTOR NPN MED PWR SOT23 | Digi-Key | FMMT491ATC-ND | Zetex Inc | FMMT491ATC |  | 5.2
81 | OPTF-1 | INT Sensor | 1 | 1.870 | 2.240 | 0.080 | 2.320 | U3 | CYC271434 | 8-DIP | IC MCU 16K FLASH 256B SRAM 8-DIP | Digi-Key | 428-1593-ND | Cypress SemiconductorCorp | CY8C27143-24PXI |  | 5.2
82 | OPTF-1 | INT Sensor | 1 | 0.154 | 0.184 | 0.080 | 0.264 | U3-Socket | Socket | Sockets for ICs, Transistors | CONN IC SOCKET 8POS DIP TIN | Digi-Key | A24807-ND | Tyco Electronics/Amp (http://www.digikey.com/scripts/Redirect/Redirect.dll?R=9&V=17) | 2-641260-1 |  | 5.2
83 | OPTF-1 | INT Sensor | 1 | 0.800 | 0.958 | 0.080 | 1.038 | SENS1 | 40T-16P | ULTRASONIC SENSOR | Ceramic Transponder 40T-16P |  |  | CERAMIC TRANSDUCER DESIGN CO., LTD | 40T-16P |  | 5.2
84 | OPTF-1 | INT Sensor | 1 | 0.080 | 0.096 | 0.080 | 0.176 | SENS2 | 40R-16P | ULTRASONIC SENSOR | Ceramic Transponder 40R-16P |  |  | CERAMIC TRANSDUCER DESIGN CO., LTD | 40R-16P |  | 5.2
85 | OPTF-1 | INT Sensor | 0 | 0.313 | 0.000 | 0.000 | 0.000 | P1 | DNP |  |  |  |  |  |  | Mask the HOLES, S/B DNP | 5.2
86 | OPTF-1 | INT Sensor | 0 | 0.082 | 0.000 | 0.000 | 0.000 | P2 | DNP |  |  |  |  |  |  | Mask the HOLES, S/B DNP | 5.2
 |  | total |  | 4.637 | 5.841 | 1.760 | 7.601
87 | OPTF-1 | OPTM-2 | 1 |  | 0.000 | 0.080 | 0.080 | Enclouser | Box-ENC-102-2110111 |  | Box 12cm x 6.9cm x 2.5cm, Black Color, ActiveWave Logo,Hole in Top Left Position Option, No Hole in Top Right, Hole on Left Side, Two Ultrasonic holes on the Top Right, Hole on the Right Side |  |  | Advanced Data Access Inc/ ActiveWave Inc | Box-ENC-102-2110111 |  | 5.2
88 | OPTF-1 | OPTM-3 | 1 |  | 0.000 | 0.080 | 0.080 | Enclouser | Box-ENC-102-3110111 |  | Box 12cm x 6.9cm x 2.5cm, Silver Color, ActiveWave Logo,Hole in Top Left Position Option, No Hole in Top Right, Hole on Left Side, Two Ultrasonic holes on the Top Right, Hole on the Right Side |  |  | Advanced Data Access Inc/ ActiveWave Inc | Box-ENC-102-3110111 |  | 5.2
89 | OPTF-1 | OPTM-4 | 1 |  | 0.000 | 0.080 | 0.080 | Enclouser | Box-ENC-102-4110111 |  | Box 12cm x 6.9cm x 2.5cm, Beige Color, ActiveWave Logo,Hole in Top Left Position Option, No Hole in Top Right, Hole on Left Side, Two Ultrasonic holes on the Top Right, Hole on the Right Side |  |  | Advanced Data Access Inc/ ActiveWave Inc | Box-ENC-102-4110111 |  | 5.2
90 | OPTF-1 | OPTM-5 | 1 | 2.500 | 2.994 | 0.080 | 3.074 | Enclouser | Box-ENC-102-5110111 |  | Box 12cm x 6.9cm x 2.5cm, Custom Color, ActiveWave Logo,Hole in Top Left Position Option, No Hole in Top Right, Hole on Left Side, Two Ultrasonic holes on the Top Right, Hole on the Right Side |  |  | Advanced Data Access Inc/ ActiveWave Inc | Box-ENC-102-5110111 |  | 5.2
91 | OPTG-0 | Sensor PWR | 2 |  | 0.000 | 0.160 | 0.160 | L18,D14 (change it to Resistor for these two) | 0 | 1206 | Res 0.0 OHM 1/4 W 5% 1206 SMD | Digi-Key | RHM0.0ERTR-ND | Rohm | MCR18EZPJ000 | Subsitute induct and Diod with Resistor | 5.2
92 | OPTG-0 | Sensor PWR | 0 |  | 0.000 | 0.000 | 0.000 | C63,C64,R60,R61,R62,RV3,U7 | DNP |  |  |  |  |  |  |  | 5.2
93 | OPTG-1 | Sensor PWR | 1 | 0.011 | 0.014 | 0.080 | 0.094 | C63 | 10pF | 0603 | CAP CER 10PF 50V 5% C0G 0603 | Digi-Key | 490-1403-2-ND | Murata | GRM1885C1H100JA01D |  | 5.2
94 | OPTG-1 | Sensor PWR | 1 | 0.011 | 0.014 | 0.080 | 0.094 | C64 | 1 uF 50V | 0805 | CAP CER 1UF 50V Y5V 0805 | Digi-Key | 490-3903-2-ND | Murata | GRM21BF51H105ZA12L |  | 5.2
95 | OPTG-1 | Sensor PWR | 1 | 0.003 | 0.004 | 0.080 | 0.084 | R62 | 12K | 0603 | RES 12K OHM 1/10W 5% 0603 SMD | Digi-Key | RHM12KGTR-ND | Rohm | MCR03EZPJ123 |  | 5.2
96 | OPTG-1 | Sensor PWR | 1 | 0.003 | 0.004 | 0.080 | 0.084 | R61 | 100K | 0603 | RES 100K OHM 1/10W 5% 0603 SMD | Digi-Key | RHM100KGCT-ND | Rohm | MCR03EZPJ104 |  | 5.2
97 | OPTG-1 | Sensor PWR | 0 |  | 0.000 | 0.000 | 0.000 | R60 | DNP |  |  |  |  |  |  |  | 5.2
98 | OPTG-1 | Sensor PWR | 1 | 0.870 | 1.042 | 0.080 | 1.122 | RV3 | 100K Pot | 9mm Squared | POT 100K OHM SQ CERMET SIDE | Digi-Key | CT94EZ104-ND | copal-electronics | CT94EZ104 |  | 5.2
99 | OPTG-1 | Sensor PWR | 1 | 0.313 | 0.375 | 0.080 | 0.455 | L18 | 3.3 uH | 1210 | INDUCTOR FERRITE CORE 3.3UH SMD | Digikey | DN42143JCT-ND |  | 1210R-332J |  | 5.2
100 | OPTG-1 | Sensor PWR | 1 | 0.143 | 0.171 | 0.080 | 0.251 | D14 | MBR0540 | SOD-123 | DIODE SCHOTTKY 40V 0.5A SOD123 | Digikey | MBR0540T1OSTR-ND | On Semiconductor | MBR0540T1 |  | 5.2
101 | OPTG-1 | Sensor PWR | 1 | 2.050 | 2.455 | 0.080 | 2.535 | U7 | LT1930 | SOT-23-5 | LT1930ES5#TRMCT-ND | Digikey | LT1930ES5#TRMCT-ND | Linear Technology | LT1930ES5#TRM |  | 5.2
102 |  |  |  |  | 0.000 | 0.000 | 0.000 |  |  |  |  |  |  |  |  |  | 5.2
 |  | total |  | 3.405 | 4.078 | 0.640 | 4.718
103 | OPTH-0 | TRX Option | 0 |  | 0.000 | 0.000 | 0.000 | C4,C24,C25,C43,C44,R12,R27,R28,R48,R49,R50,L5,L7,Q9,Q10,Y1 | DNP |  |  |  |  |  |  |  | 5.2
104 | OPTH-1 | TRX Option | 1 | 0.016 | 0.020 | 0.080 | 0.100 | C24 | 2 pF +/- 0.25 | 0603 | CAP CER 2.0PF 50V C0G 0603 ±0.25pF | Digi-Key | 490-1379-2-ND | Murata | GRM1885C1H2R0CZ01D |  | 5.2
105 | OPTH-1 | TRX Option | 1 | 0.016 | 0.020 | 0.080 | 0.100 | C43 | 4.7 pF +/- 0.25 pF | 0603 | CAP CER 4.7PF 50V C0G 0603 ±0.25pF | Digi-Key | 490-1389-2-ND | Murata | GRM1885C1H4R7CZ01D |  | 5.2
106 | OPTH-1 | TRX Option | 1 | 0.012 | 0.015 | 0.080 | 0.095 | C4 | 33pF | 0603 | CAP CER 33PF 50V C0G 5% 0603 | Digi-Key | 445-1275-2-ND | TDK Corp | C1608C0G1H330J |  | 5.2
107 | OPTH-1 | TRX Option | 1 | 0.011 | 0.014 | 0.080 | 0.094 | C44 | 100pF | 0603 | CAP CER 100PF 50V C0G 5% 0603 | Digi-Key | 445-1281-2-ND | TDK Corp | C1608C0G1H101J |  | 5.2
108 | OPTH-1 | TRX Option | 1 | 0.008 | 0.010 | 0.080 | 0.090 | C25 | 1000pF | 0603 | CAP 1000PF 50V CERAMIC X7R 0603 ±5% | Digi-Key | 399-1083-2-ND | Kemet | C0603C102J5RACTU |  | 5.2
109 | OPTH-1 | TRX Option | 1 | 0.005 | 0.006 | 0.080 | 0.086 | C42 | 0.1uF | 0603 | CAP .10UF 25V CERAMIC Y5V 0603 -20%, +80% | Digi-Key | 399-1100-2-ND | Kemet | C0603C104Z3VACTU |  | 5.2
110 | OPTH-1 | TRX Option | 1 | 0.015 | 0.018 | 0.080 | 0.098 | R12 | 22 | 0603 | RES 22 OHM 1/10W 5% | Digi-Key | RHM22GTR-ND | Rohm | MCR03EZPJ220 |  | 5.2
111 | OPTH-1 | TRX Option | 1 | 0.015 | 0.018 | 0.080 | 0.098 | R49 | 68 | 0603 | Carbon Film Resistor 68 OHM 1/16W 5% | Digi-Key | RHM68GTR-ND | Rohm | MCR03EZPJ680 |  | 5.2
112 | OPTH-1 | TRX Option | 1 | 0.015 | 0.018 | 0.080 | 0.098 | R28 | 4.7K | 0603 | RES 4.7K OHM 1/10W 5% 0603 SMD | Digi-Key | RHM4.7KGTR-ND | Rohm | MCR03EZPJ472 |  | 5.2
113 | OPTH-1 | TRX Option | 1 | 0.015 | 0.018 | 0.080 | 0.098 | R27 | 6.8k | 0603 | RES 6.8K OHM 1/10W 5% 0603 SMD | Digi-Key | RHM6.8KGTR-ND | Rohm | MCR03EZPJ682 |  | 5.2
114 | OPTH-1 | TRX Option | 1 | 0.015 | 0.018 | 0.080 | 0.098 | R48 | 39k | 0603 | RES 39K OHM 1/10W 5% 0603 SMD | Digikey | RHM39KGTR-ND | Rohm | MCR03EZPJ393 |  | 5.2
115 | OPTH-1 | TRX Option | 1 | 0.015 | 0.018 | 0.080 | 0.098 | R50 | 1M | 0603 | Carbon Film Resistor 1M OHM 1/16W 5% | Digi-Key | RHM1.0MGTR-ND | Rohm | MCR03EZPJ105 |  | 5.2
116 | OPTH-1 | TRX Option | 1 | 0.048 | 0.057 | 0.080 | 0.137 | L5 | 3.3nH | 0603 | INDUCTOR 3.3NH +-.3NH 0603 SMD | Digi-Key | PCD1967TR-ND | Panasonic | ELJ-RE3N3DFA |  | 5.2
117 | OPTH-1 | TRX Option | 1 | 0.170 | 0.204 | 0.080 | 0.284 | L7 | 0.18uH | 0603 | INDUCTOR MULTILAYER 0.18 UH | Digi-Key | 445-1006-1-ND | TDK Corporation | MLF1608DR18K |  | 5.2
118 | OPTH-1 | TRX Option | 1 | 0.300 | 0.359 | 0.080 | 0.439 | Q9 | NE85619 | Ultra Super Mini Mold | TRANS NPN 1GHZ SMD | Digi-Key | NE85619-ATR-ND | NEC | NE85619-T1-A |  | 5.2
119 | OPTH-1 | TRX Option | 1 | 0.055 | 0.066 | 0.080 | 0.146 | Q10 | 2N7002LT1 | SOT-23 | IC TRANS N-CH 60V 7.5 OHM | Digi-Key | 2N7002NTR-ND | Fairchild | 2N7002NTR-ND |  | 5.2
120 | OPTH-1 | TRX Option |  |  | 0.000 | 0.000 | 0.000 |  |  |  |  |  |  |  |  |  | 5.2
121 | OPTH-1 | TRX Option | 1 | 0.680 | 0.814 | 0.080 | 0.894 | Y1 | 916.5_Resonator | 3.0 X3.0 MM | RESONATOR | RF Monolithics | RO2144E-2 | RF Monolithics | RO2144E-2 |  | 5.2
122 |  |  | 0 |  | 0.000 | 0.000 | 0.000 | TP1, TP2, TP4, TP5, TP6, TP7, TP8,TP9, TP10, TP11, TP14, TP15, TP16, TP17,J1,J2,RV2,R53,R56,C60 | DNP |  |  |  |  |  |  |  | 5.3
 |  | total |  | 1.410 | 1.689 | 1.360 | 3.049
 |  | *Note REV5.3 Moved J1,Rv2,R53,R56,and C60 and add C58 to DNP Line Item 68

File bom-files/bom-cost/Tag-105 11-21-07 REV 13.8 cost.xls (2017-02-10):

TAG-105-Rev13.8
11/ 21/2007 |  |  |  |  |  |  |  |  |  | Jumbo Card Tag
Item # | Part Stat. | Qty | Unit Cost | Extended Cost | Labor Cost | Total Cost | Part Ref. | Value | Part Size | Description | Dist. | Distributor P/N | Manufacturer P/N | Notes
1 | BASIC | 1 | 0.011 | 0.014 | 0.080 | 0.094 | C3 | 2.0pF +/- 0.25pF | 0603 | CAP CER 2.0PF 50V C0G 0603 | Digi-Key | 490-1379-2-ND | GRM1885C1H2R0CZ01D
2 | BASIC | 3 | 0.011 | 0.041 | 0.240 | 0.281 | C26,C20,C27 | 15pF | 0603 | CAP CER 15PF 50V 5% C0G 0603 | Digi-Key | 490-1407-2-ND | GRM1885C1H150JA01D
3 | BASIC | 2 | 0.009 | 0.022 | 0.160 | 0.182 | C12,C13 | 33pF | 0603 | CAP CER 33PF 50V 5% C0G 0603 | Digi-Key | 490-1415-2-ND | GRM1885C1H330JA01D
4 | BASIC | 3 | 0.008 | 0.030 | 0.240 | 0.270 | C6,C7,C14 | 100 pF | 0603 | CAP 100PF 50V CERAMIC | Digi-Key | 445-1281-2-ND | C1608C0G1H101J
5 | BASIC | 3 | 0.008 | 0.029 | 0.240 | 0.269 | C8,C9,C10 | 1000 pF | 0603 | CAP 1000PF 50V CERAMIC NP0 | Digi-Key | 399-1083-2-ND | C0603C102J5RACTU
6 | BASIC | 5 | 0.005 | 0.030 | 0.400 | 0.430 | C11,C15,C17,C18, C24 | 0.1 uF | 0603 | CAP .10UF 16V CERAMIC X7R | Digi-Key | 399-1100-2-ND | C0603C104Z3VACTU
7 | BASIC | 0 |  | 0.000 | 0.000 | 0.000 | C22,C23 | DNP | 0603
8 | BASIC | 2 | 0.001 | 0.003 | 0.160 | 0.163 | R12,R13 | 10 | 0603 | Carbon Film Resistor 10 OHM 1/16W 5% | Digi-Key | RHM10GTR-ND | MCR03EZPJ100
9 | BASIC | 1 | 0.001 | 0.002 | 0.080 | 0.082 | R6 | 22 ohm | 0603 | RES 22 OHM 1/10W 5% | Digi-Key | RHM22GTR-ND | MCR03EZPJ220
10 | BASIC | 1 | 0.001 | 0.002 | 0.080 | 0.082 | R11 | 68 | 0603 | Carbon Film Resistor 68 OHM 1/16W 5% | Digi-Key | RHM68GTR-ND | MCR03EZPJ680
11 | BASIC | 1 | 0.001 | 0.002 | 0.080 | 0.082 | R14 | 470 | 0603 | Carbon Film Resistor 470 OHM 1/16W 5% | Digi-Key | RHM470GTR-ND | MCR03EZPJ471
12 | BASIC | 1 | 0.001 | 0.002 | 0.080 | 0.082 | R18 | 1.0K | 0603 | Carbon Film Resistor 1.0K OHM 1/16W 5% | Digi-Key | RHM1.0KGTR-ND | MCR03EZPJ102
13 | BASIC | 1 | 0.001 | 0.002 | 0.080 | 0.082 | R19 | 2.0K | 0603 | RES 2.0K OHM 1/10W 5% | Digi-Key | RHM2.0KGTR-ND | MCR03EZPJ202
14 | BASIC | 1 | 0.001 | 0.002 | 0.080 | 0.082 | R20 | 2.7K | 0603 | Carbon Film Resistor 2.7K OHM 1/16W 5% | Digi-Key | RHM2.7KGTR-ND | MCR03EZPJ272
15 | BASIC | 2 | 0.001 | 0.003 | 0.160 | 0.163 | R16,R17 | 3.0K | 0603 | RES 3.0K OHM 1/10W 5% 0603 SMD | Digi-Key | RHM3.0KGTR-ND | MCR03EZPJ302
15 | BASIC | 2 | 0.001 | 0.003 | 0.160 | 0.163 | R1,R8 | 4.7K | 0603 | Carbon Film Resistor 4.7K OHM 1/16W 5% | Digi-Key | RHM4.7KGTR-ND | MCR03EZPJ472
16 | BASIC | 1 | 0.001 | 0.002 | 0.080 | 0.082 | R7 | 6.8K | 0603 | Carbon Film Resistor 6.8K OHM 1/16W 5% | Digi-Key | RHM6.8KGTR-ND | MCR03EZPJ682
17 | BASIC | 1 | 0.001 | 0.002 | 0.080 | 0.082 | R15 | 36.5K | 0603 | RES 36.5K OHM 1/10W 1% 0603 SMD | Digi-Key | RHM36.5KHTR-ND | MCR03EZPFX3652
18 | BASIC | 4 | 0.001 | 0.007 | 0.320 | 0.327 | R3,R5,R9,R10 | 39K | 0603 | Carbon Film Resistor 39k OHM 1/16W 5% | Digi-Key | RHM39KGTR-ND | MCR03EZPJ393
19 | BASIC | 1 | 0.001 | 0.002 | 0.080 | 0.082 | R4 | 56.2K | 0603 | RES 56.2K OHM 1/10W 1% 0603 SMD | Digi-Key | RHM56.2KHTR-ND | MCR03EZPFX5622
20 | BASIC | 1 | 0.001 | 0.002 | 0.080 | 0.082 | R24 | 100K | 0603 | RES 100K OHM 1/10W 5% 0603 SMD | Digi-Key | RHM100KGTR-ND | MCR03EZPJ104
21 | BASIC | 1 | 0.001 | 0.002 | 0.080 | 0.082 | R21 | 220k | 0603 | RES 220K OHM 1/10W 5% 0603 SMD | Digi-Key | RHM220KGTR-ND | MCR03EZPJ224
22 | BASIC | 1 | 0.001 | 0.002 | 0.080 | 0.082 | R23 | 300K | 0603 | RES 300K OHM 1/10W 5% 0603 SMD | Digi-Key | RHM300KGTR-ND | MCR03EZPJ304
23 | BASIC | 1 | 0.001 | 0.002 | 0.080 | 0.082 | R2 | 1M | 0603 | Carbon Film Resistor 1M OHM 1/16W 5% | Digi-Key | RHM1.0MGTR-ND | MCR03EZPJ105
24 | BASIC | 1 | 0.034 | 0.041 | 0.080 | 0.121 | L2 | 3.3nH | 0603 | INDUCTOR 3.3NH +/-0.2NH | Digi-Key | PCD1967TR-ND | ELJ-RE3N3DFA
25 | BASIC | 1 | 0.102 | 0.123 | 0.080 | 0.203 | L3 | 0.18uH | 0603 | INDUCTOR MULTILAYER 0.18 UH | Digi-Key | 445-1006-1-ND | MLF1608DR18K
26 | BASIC | 1 | 0.102 | 0.123 | 0.080 | 0.203 | L6 | 0.33uH | 0603 | INDUCTOR MULTILAYER 0.33UH 1608 | Digi-Key | 445-1009-2-ND | MLF1608DR33K
27 | BASIC | 2 | 0.270 | 0.651 | 0.160 | 0.811 | Q1,Q2 | NE85619 | Ultra Super Mini Mold | TRANS NPN 1GHZ SMD | Digi-Key | NE85619-ATR-ND | NE85619-T1-A
28 | BASIC | 1 | 0.042 | 0.051 | 0.080 | 0.131 | Q3 | 2N7002 | SOT-23 | IC TRANS N-CH 60V 7.5 OHM | Digi-Key | 2N7002NTR-ND | 2N7002NTR-ND
 |  |  |  | 0.000 | 0.000 | 0.000 | ALT |  |  | IC TRANS N-CH 60V 7.5 OHM |  |  | 2N7002LT1
 |  |  |  | 0.000 | 0.000 | 0.000 | ALT |  |  | IC TRANS N-CH 60V 7.5 OHM |  |  | 2N7002
 |  |  |  | 0.000 | 0.000 | 0.000 | ALT |  |  | IC TRANS N-CH 60V 7.5 OHM |  |  | 2N7002
 |  |  |  | 0.000 | 0.000 | 0.000 | ALT |  |  | IC TRANS N-CH 60V 7.5 OHM |  |  | 2N7002 T&R
29 | BASIC | 1 | 0.700 | 0.843 | 0.080 | 0.923 | U1 | PIC16F690 | 20SSOP | IC MCU FLASH 4KX14 EEPROM | Digi-Key | PIC16F690-I/SS-ND | PIC16F690-I/SS
30 | BASIC | 1 | 0.585 | 0.705 | 0.080 | 0.785 | U2 | MIC861 | SC-70-5 | IC OPAMP 400KHZ 2.7V ULT LP SC70 | Digi-Key | MIC861YC5TR-ND | MIC861YC5TR
31 | BASIC | 1 | 0.210 | 0.253 | 0.080 | 0.333 | U5 | TC1070VCT713 | SOT23A-5 | IC REG LDO ADJ 50MA |  |  | TC1070VCT713
32 | BASIC | 1 | 2.165 | 2.608 | 0.080 | 2.688 | U6 | MAX9119EXK+ | SC70 | IC COMPARATOR BTR SC70-5 | Digi-Key | MAX9119EXK+T-ND | MAX9119EXK+T
33 | BASIC | 1 | 0.588 | 0.708 | 0.080 | 0.788 | Y2 | SCP8-32.768KHZ TR | 1.5X3.2 Ceramic Watch | CRYSTAL 32.768KHZ 12.5PF SMD |  |  | SCP8-32.768KHZ TR
 |  |  |  | 0.000 | 0.000 | 0.000 | ALT |  |  | CRYSTAL 32.768KHZ 12.5PF SMD | Digi-Key | 535-9542-2-ND | ABS07-32.768KHZ-T
34 | BASIC | 1 | 0.260 | 0.313 | 0.080 | 0.393 | B1A | Battery Holder |  | Battery Retainer | Keystone | C-5510-ACT | C-5510-ACT
35 | BASIC | 1 | 0.180 | 0.217 | 0.080 | 0.297 | B1B | Battery Contact |  | Battery Contact |  |  | 0097-0488-02
35 | BASIC |  | 1.200 | 0.000 | 0.000 | 0.000 | PCB | PCB 105 |  | Credit Card Tag board
36 | BASIC | 0 |  | 0.000 | 0.000 | 0.000 | J1,J2 | DNP | Mask it | NO SOLDER IN HOLES |  |  |  | NO SOLDER IN HOLES
 | Total |  |  | 6.841 | 4.240 | 11.081
37 | OPT1 | 1 | 0.680 | 0.819 | 0.080 | 0.899 | Y1 | 916.5 Resonator | 3.8x3.8mm | 916.5 MHz Saw Resonator | Richardson | RO2144D | RO2144D
38 | OPT1 | 1 | 0.011 | 0.014 | 0.080 | 0.094 | C21 | 1.8pF +/- 0.25pF | 0603 | CAP CER 1.8PF 50V C0G 0603 | Digi-Key | 490-1378-2-ND | GRM1885C1H1R8CZ01D
1 | OPT1 | 1 | 0.011 | 0.014 | 0.080 | 0.094 | C2 | 2.0pF +/- 0.25pF | 0603 | CAP CER 2.0PF 50V C0G 0603 | Digi-Key | 490-1379-2-ND | GRM1885C1H2R0CZ01D
39 | OPT1 | 1 | 0.011 | 0.014 | 0.080 | 0.094 | C19 | 4.7pF +/-0.25pF | 0603 | CAP CER 4.7PF 50V C0G 0603 | Digi-Key | 490-1389-2-ND | GRM1885C1H4R7CZ01D
 |  |  |  |  |  | 1.180
40 | OPT2 | 1 | 0.680 | 0.819 | 0.080 | 0.899 | Y1 | 868.95 Resonator | 3.8x3.8mm | 868.95 MHz Saw Resonator | Richardson | RO2156D | RO2156D
41 | OPT2 | 1 | 0.011 | 0.014 | 0.080 | 0.094 | C21 | 1.8pF +/- 0.25pF | 0603 | CAP CER 1.8PF 50V C0G 0603 | Digi-Key | 490-1378-2-ND | GRM1885C1H1R8CZ01D
1 | OPT2 | 1 | 0.011 | 0.014 | 0.080 | 0.094 | C2 | 3.0pF +/- 0.25pF | 0603 | CAP CER 3.0PF 50V C0G 0603 | Digi-Key | 490-1383-2-ND | GRM1885C1H3R0CZ01D
42 | OPT1 | 1 | 0.011 | 0.014 | 0.080 | 0.094 | C19 | 4.7pF +/-0.25pF | 0603 | CAP CER 4.7PF 50V C0G 0603 | Digi-Key | 490-1389-2-ND | GRM1885C1H4R7CZ01D
 |  |  |  |  |  | 1.180
43 | OPT3 | 1 | 0.720 | 0.867 | 0.080 | 0.947 | Y1 | 927.2 Resonator | 3.8x3.8mm | 927.2 MHz Saw Resonator
44 | OPT3 | 1 | 0.011 | 0.014 | 0.080 | 0.094 | C21 | 1.8pF +/- 0.25pF | 0603 | CAP CER 1.8PF 50V C0G 0603 | Digi-Key | 490-1378-2-ND | GRM1885C1H1R8CZ01D
1 | OPT3 | 1 | 0.011 | 0.014 | 0.080 | 0.094 | C2 | 2.0pF +/- 0.25pF | 0603 | CAP CER 2.0PF 50V C0G 0603 | Digi-Key | 490-1379-2-ND | GRM1885C1H2R0CZ01D
45 | OPT3 | 1 | 0.011 | 0.014 | 0.080 | 0.094 | C19 | 4.7pF +/-0.25pF | 0603 | CAP CER 4.7PF 50V C0G 0603 | Digi-Key | 490-1389-2-ND | GRM1885C1H4R7CZ01D
 |  |  |  |  |  | 1.228
46 | OPT D-0 | 0 |  | 0.000 | 0.000 | 0.000 | U7 | DNP
47 | OPT D-0 | 0 |  | 0.000 | 0.000 | 0.000 | C4 | DNP
48 | OPT D-0 | 0 |  | 0.000 | 0.000 | 0.000 | C1 | DNP
49 | OPT D-1 | 1 | 0.290 | 0.349 | 0.080 | 0.429 | U7 | TLE4913 | SOT-23W | Low Power Hall Effect Switch | Arrow | TLE4913 | TLE4913
50 | OPT D-1 | 1 | 0.011 | 0.013 | 0.080 | 0.093 | C4 | 10pF | 0603 | CAP 10PF 50V CERAMIC | Digi-Key | PCC100CVCT-ND | ECJ-1VC1H100D
51 | OPT D-1 | 1 | 0.011 | 0.013 | 0.080 | 0.093 | C1 | 0.1uF | 0603 | CAP .1UF 16V CERAMIC Y5V 0603 | Digi-Key | PCC1788CT-ND | ECJ-1VF1C104Z
 |  |  |  |  |  | 0.616
52 | OPT E-0 | 0 |  | 0.000 | 0.000 | 0.000 | U4 | DNP
53 | OPT E-1 | N/A |  | #VALUE! | #VALUE! | #VALUE! | U4 | 1K Bit | 8-SOIC
54 | OPT E-2 | N/A |  | #VALUE! | #VALUE! | #VALUE! | U4 | 2K Bits | 8-SOIC
55 | OPT E-3 | 1 | 0.240 | 0.289 | 0.080 | 0.369 | U4 | 4K Bits | 8-SOIC | 512 x 8 1.8V Serial EE |  |  | 24AA04-I/SN
56 | OPT E-4 | N/A |  | #VALUE! | #VALUE! | #VALUE! | U4 | 8K Bits | 8-SOIC
57 | OPT E-5 | N/A |  | #VALUE! | #VALUE! | #VALUE! | U4 | 16K Bits | 8-SOIC
58 | OPT E-6 | N/A |  | #VALUE! | #VALUE! | #VALUE! | U4 | 32K Bits | 8-SOIC
59 | OPT E-7 | N/A |  | #VALUE! | #VALUE! | #VALUE! | U4 | 64K Bits | 8-SOIC
60 | OPT E-8 | N/A |  | #VALUE! | #VALUE! | #VALUE! | U4 | 128K Bits | 8-SOIC
61 | OPT E-9 | 1 | 0.930 | 1.120 | 0.080 | 1.200 | U4 | 256K Bits | 8-SOIC | 32K x 8 1.8V serial EE |  |  | 24AA256-I/SN
 |  |  |  | 0.000 | 0.000 | 0.000
62 | OPT F-0 | 0 |  | 0.000 | 0.000 | 0.000 | D1 | DNP
63 | OPT F-0 | 0 |  | 0.000 | 0.000 | 0.000 | R22 | DNP
 |  |  |  | 0.000 | 0.000 | 0.000
64 | OPT F-1 | 1 | 0.103 | 0.124 | 0.080 | 0.204 | D1 | Red LED | 1206 | LED RED CLEAR 1206 SMD | Digi-Key |  | HKR1105W-TRR | LED should be mounted upside down, so it shines through the hole in the PCB
65 | OPT F-1 | 1 | 0.003 | 0.004 | 0.080 | 0.084 | R22 | 200 | 0603 | RES 200 OHM 1/10W 5% | Digi-Key | RHM200GTR-ND | MCR03EZPJ201
 |  |  |  | 0.000 | 0.000 | 0.000
66 | OPT G-0 | 0 |  | 0.000 | 0.000 | 0.000 | SP1 | DNP
67 | OPT G-0 | 0 |  | 0.000 | 0.000 | 0.000 | Q4 | DNP
68 | OPT G-0 | 0 |  | 0.000 | 0.000 | 0.000 | C5 | DNP
 |  |  |  | 0.000 | 0.000 | 0.000
69 | OPT G-1 | 1 | 1.120 | 1.349 | 0.080 | 1.429 | SP1 | Buzzer | 10X10X5mm | MagneticTransducer, External Drive | Digi-Key | 668-1084-2-ND | SMT-1028-S-R
70 | OPT G-1 | 1 | 0.063 | 0.076 | 0.080 | 0.156 | Q4 | MMBT2222A-7-F | SOT-23 | TRANS NPN 40V 350MW SMD SOT23 | Digi-Key | MMBT2222A-FDITR-ND | MMBT2222A-7-F
71 | OPT G-1 | 1 | 0.005 | 0.006 | 0.080 | 0.086 | C5 | 0.1 uF | 0603 | CAP .10UF 16V CERAMIC X7R | Digi-Key | 399-1100-2-ND | C0603C104Z3VACTU
 |  |  |  | 0.000 | 0.000 | 0.000
72 | OPT H-0 | 0 |  | 0.000 | 0.000 | 0.000 | U3 | DNP
 |  |  |  | 0.000 | 0.000 | 0.000
73 | OPT H-1 | 1 | 1.810 | 2.181 | 0.080 | 2.261 | U3 | DS1631U | 8MSOP | Temperature Detector IC | Maxim | 90-1631U-TRL | DS1631U/T&R
 |  |  |  | 0.000 | 0.000 | 0.000
74 | OPT I-0 | 0 |  | 0.000 | 0.000 | 0.000 | SW1 | DNP
 |  |  |  | 0.000 | 0.000 | 0.000
75 |  | 1 |  | 0.000 | 0.080 | 0.080 | SW1 | TBD |  | PUSH BUTTON
 |  |  |  | 0.000 | 0.000 | 0.000
76 | OPT J-0 | 0 |  | 0.000 | 0.000 | 0.000 | SW2 | DNP
77 | OPT J-0 | 0 |  | 0.000 | 0.000 | 0.000 | R25 | DNP
 |  |  |  | 0.000 | 0.000 | 0.000
78 | OPT J-1 | 1 |  | 0.000 | 0.080 | 0.080 | SW2 | TBD |  | MOTION DETECTION (tilt switch)
79 | OPT J-1 | 1 | 0.003 | 0.004 | 0.080 | 0.084 | R25 | 39K | 0603 | Carbon Film Resistor 39k OHM 1/16W 5% | Digi-Key | RHM39KGTR-ND | MCR03EZPJ393
 |  |  |  | 0.000 | 0.000 | 0.000
80 | OPT K-0 | 0 |  | 0.000 | 0.000 | 0.000 |  | DNP |  | B1 | No Battery
 |  |  |  | 0.000 | 0.000 | 0.000
81 | OPT K-1 | 1 | 0.130 | 0.157 | 0.080 | 0.237 | battery |  |  | B1 | Battery |  | CR2032FV
 |  |  |  | 0.000 | 0.000 | 0.000
82 | OPT L-0 | 0 |  | 0.000 | 0.000 | 0.000 | Enclosure | DNP
 |  |  |  | 0.000 | 0.000 | 0.000
83 | OPT L-1 | 1 |  | 0.000 | 0.080 | 0.080 | Enclosure | White w/AWI logo
 |  |  |  | 0.000 | 0.000 | 0.000
84 | OPT L-2 | 1 |  | 0.000 | 0.080 | 0.080 | Enclosure | Black w/ AWI logo
 |  |  |  | 0.000 | 0.000 | 0.000
85 | OPT L-3 | 1 |  | 0.000 | 0.080 | 0.080 | Enclosure | Custom (logo, etc.)

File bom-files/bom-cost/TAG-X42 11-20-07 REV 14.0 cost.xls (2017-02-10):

TAG-102-Rev14
11/20/2007 |  |  |  |  | Protex Option |  |  |  |  |  | Compact Tag
REV 14
Item # | Part Stat. | Option # | Qty-Sur | Unit Price | Mat CM Price | Labor Cost | Total Price | Part Ref. | Value | Part Size | Description | Dist. | Distributor P/N | Manufacturer | Manufacturer P/N | Notes
1 | BASIC |  | 1 | 0.011 | 0.013 | 0.080 | 0.093 | C21 | 1.5pF +/- 0.25pF | 0603 | CAP CER 1.5PF 50V C0G 0603 | Digi-Key | 490-1376-2-ND | Murata | GRM1885C1H1R5CZ01D
2 | BASIC |  | 2 | 0.011 | 0.026 | 0.160 | 0.186 | C2,C3 | 2.0pF +/- 0.25pF | 0603 | CAP CER 2.0PF 50V C0G 0603 | Digi-Key | 490-1379-2-ND | Murata | GRM1885C1H2R0CZ01D
3 | BASIC |  | 3 | 0.011 | 0.041 | 0.240 | 0.281 | C26,C20,C27 | 15pF | 0603 | CAP CER 15PF 50V 5% C0G 0603 | Digi-Key | 490-1407-2-ND | Murata | GRM1885C1H150JA01D
4 | BASIC |  | 2 | 0.008 | 0.020 | 0.160 | 0.180 | C12,C13 | 33pF | 0603 | CAP CER 33PF 50V 5% C0G 0603 | Digi-Key | 490-1415-2-ND | Murata | GRM1885C1H330JA01D
5 | BASIC |  | 3 | 0.008 | 0.030 | 0.240 | 0.270 | C6,C7,C14 | 100 pF | 0603 | CAP 100PF 50V CERAMIC | Digi-Key | 445-1281-2-ND | TDK Corp | C1608C0G1H101J
6 | BASIC |  | 3 | 0.008 | 0.030 | 0.240 | 0.270 | C8,C9,C10 | 1000 pF | 0603 | CAP 1000PF 50V CERAMIC NP0 | Digi-Key | 399-1083-2-ND | Kemet | C0603C102J5RACTU
7 | BASIC |  | 1 | 0.008 | 0.010 | 0.080 | 0.090 | C17 | 10000 PF | 0603 | CAP 10000PF 50V CERAMIC X7R 0603 | Digi-Key | 399-1091-2-ND | Kemet | C0603C103K5RACTU
7 | BASIC |  | 4 | 0.008 | 0.040 | 0.320 | 0.360 | C11,C15,C18, C24 | 0.1 uF | 0603 | CAP .10UF 16V CERAMIC X7R | Digi-Key | 399-1100-2-ND | Kemet | C0603C104Z3VACTU
8 | BASIC |  | 0 |  | 0.000 | 0.000 | 0.000 | C22,C23,C25 | DNP | 0603
9 | BASIC |  | 2 | 0.001 | 0.002 | 0.160 | 0.162 | R12,R13 | 10 | 0603 | Carbon Film Resistor 10 OHM 1/16W 5% | Digi-Key | RHM10GTR-ND | Rohm | MCR03EZPJ100
10 | BASIC |  | 1 | 0.001 | 0.001 | 0.080 | 0.081 | R6 | 22 ohm | 0603 | RES 22 OHM 1/10W 5% | Digi-Key | RHM22GTR-ND | Rohm | MCR03EZPJ220
11 | BASIC |  | 1 | 0.001 | 0.001 | 0.080 | 0.081 | R11 | 68 | 0603 | Carbon Film Resistor 68 OHM 1/16W 5% | Digi-Key | RHM68GTR-ND | Rohm | MCR03EZPJ680
12 | BASIC |  | 1 | 0.001 | 0.001 | 0.080 | 0.081 | R14 | 470 | 0603 | Carbon Film Resistor 470 OHM 1/16W 5% | Digi-Key | RHM470GTR-ND | Rohm | MCR03EZPJ471
13 | BASIC |  | 1 | 0.001 | 0.001 | 0.080 | 0.081 | R18 | 1.0K | 0603 | Carbon Film Resistor 1.0K OHM 1/16W 5% | Digi-Key | RHM1.0KGTR-ND | Rohm | MCR03EZPJ102
14 | BASIC |  | 2 | 0.001 | 0.002 | 0.160 | 0.162 | R17,R19 | 2.0K | 0603 | RES 2.0K OHM 1/10W 5% | Digi-Key | RHM2.0KGTR-ND | Rohm | MCR03EZPJ202
15 | BASIC |  | 1 | 0.001 | 0.001 | 0.080 | 0.081 | R20 | 2.7K | 0603 | Carbon Film Resistor 2.7K OHM 1/16W 5% | Digi-Key | RHM2.7KGTR-ND | Rohm | MCR03EZPJ272
15 | BASIC |  | 2 | 0.001 | 0.002 | 0.160 | 0.162 | R1,R8 | 4.7K | 0603 | Carbon Film Resistor 4.7K OHM 1/16W 5% | Digi-Key | RHM4.7KGTR-ND | Rohm | MCR03EZPJ472
16 | BASIC |  | 1 | 0.001 | 0.001 | 0.080 | 0.081 | R7 | 6.8K | 0603 | Carbon Film Resistor 6.8K OHM 1/16W 5% | Digi-Key | RHM6.8KGTR-ND | Rohm | MCR03EZPJ682
17 | BASIC |  | 1 | 0.001 | 0.001 | 0.080 | 0.081 | R16 | 22K | 0603 | RES 22.0K OHM 1/10W 1% 0603 SMD | Digi-Key | RHM22.0KHTR-ND | Rohm | MCR03EZPFX2202
18 | BASIC |  | 1 | 0.001 | 0.001 | 0.080 | 0.081 | R15 | 36.5K | 0603 | RES 36.5K OHM 1/10W 1% 0603 SMD | Digi-Key | RHM36.5KHTR-ND | Rohm | MCR03EZPFX3652
19 | BASIC |  | 4 | 0.001 | 0.005 | 0.320 | 0.325 | R3,R5,R9,R10 | 39K | 0603 | Carbon Film Resistor 39k OHM 1/16W 5% | Digi-Key | RHM39KGTR-ND | Rohm | MCR03EZPJ393
20 | BASIC |  | 1 | 0.001 | 0.001 | 0.080 | 0.081 | R4 | 56.2K | 0603 | RES 56.2K OHM 1/10W 1% 0603 SMD | Digi-Key | RHM56.2KHTR-ND | Rohm | MCR03EZPFX5622
21 | BASIC |  | 1 | 0.001 | 0.001 | 0.080 | 0.081 | R24 | 100K | 0603 | RES 100K OHM 1/10W 5% 0603 SMD | Digi-Key | RHM100KGTR-ND | Rohm | MCR03EZPJ104
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

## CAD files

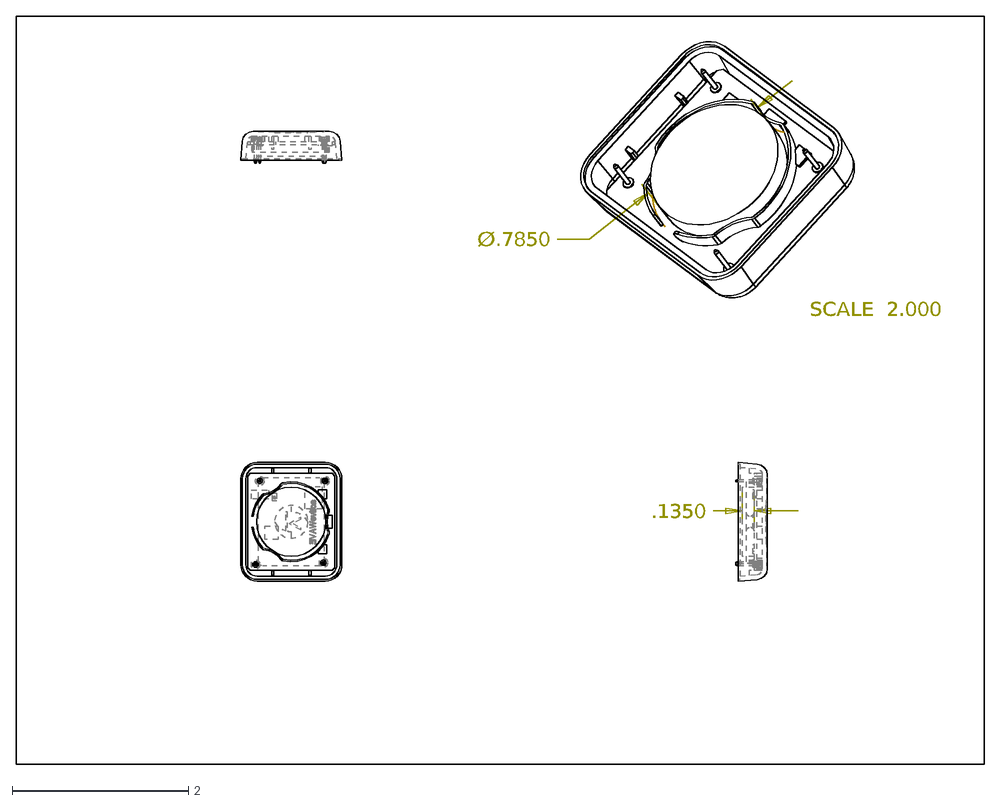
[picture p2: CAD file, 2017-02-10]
protel-files/tags/small-tag/dxf/batt-assy.dxf
.1350
Ø
.7850
SCALE
2.000

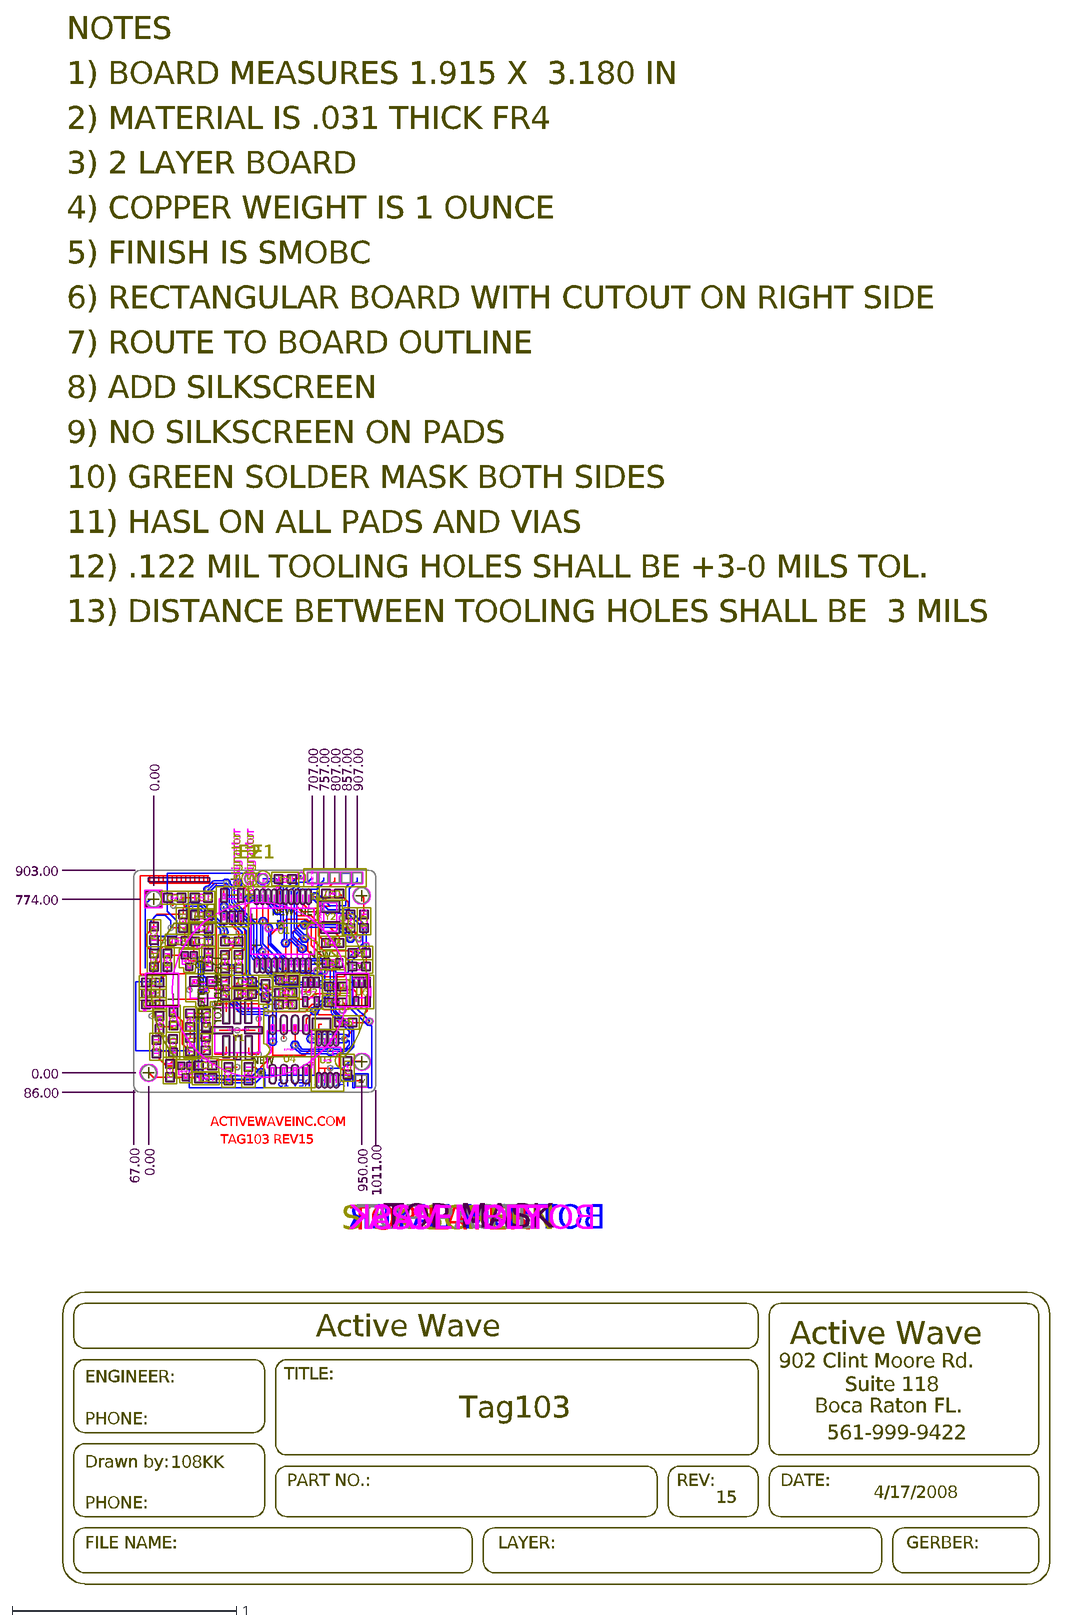
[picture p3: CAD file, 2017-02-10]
protel-files/tags/small-tag/rev15/103-rev15.3/NewTag Rev15.DXF
TOP LAYER
TAG103 REV15
ACTIVEWAVEINC.COM
BOTTOM LAYER
TAG103 REV 15
SILK SCREEN
TOP PASTE
TOP MASK
BOTTOM MASK
ASSEMBLY
Tag103
108KK
Active Wave
GERBER:
FILE NAME:
Drawn by:
TITLE:
PART NO.:
ENGINEER:
LAYER:
PHONE:
REV:
DATE:
15
Boca Raton FL.
902 Clint Moore Rd.
561-999-9422
Suite 118
4/17/2008
13) DISTANCE BETWEEN TOOLING HOLES SHALL BE 3 MILS
11) HASL ON ALL PADS AND VIAS
2) MATERIAL IS .031 THICK FR4
9) NO SILKSCREEN ON PADS
8) ADD SILKSCREEN
7) ROUTE TO BOARD OUTLINE
6) RECTANGULAR BOARD WITH CUTOUT ON RIGHT SIDE
5) FINISH IS SMOBC
4) COPPER WEIGHT IS 1 OUNCE
3) 2 LAYER BOARD
10) GREEN SOLDER MASK BOTH SIDES
NOTES
1) BOARD MEASURES 1.915 X 3.180 IN
12) .122 MIL TOOLING HOLES SHALL BE +3-0 MILS TOL.
NEW
3V
903.00
774.00
86.00
0.00
1011.00
950.00
67.00
907.00
857.00
807.00
757.00
707.00
.Pattern
.Designator
E2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

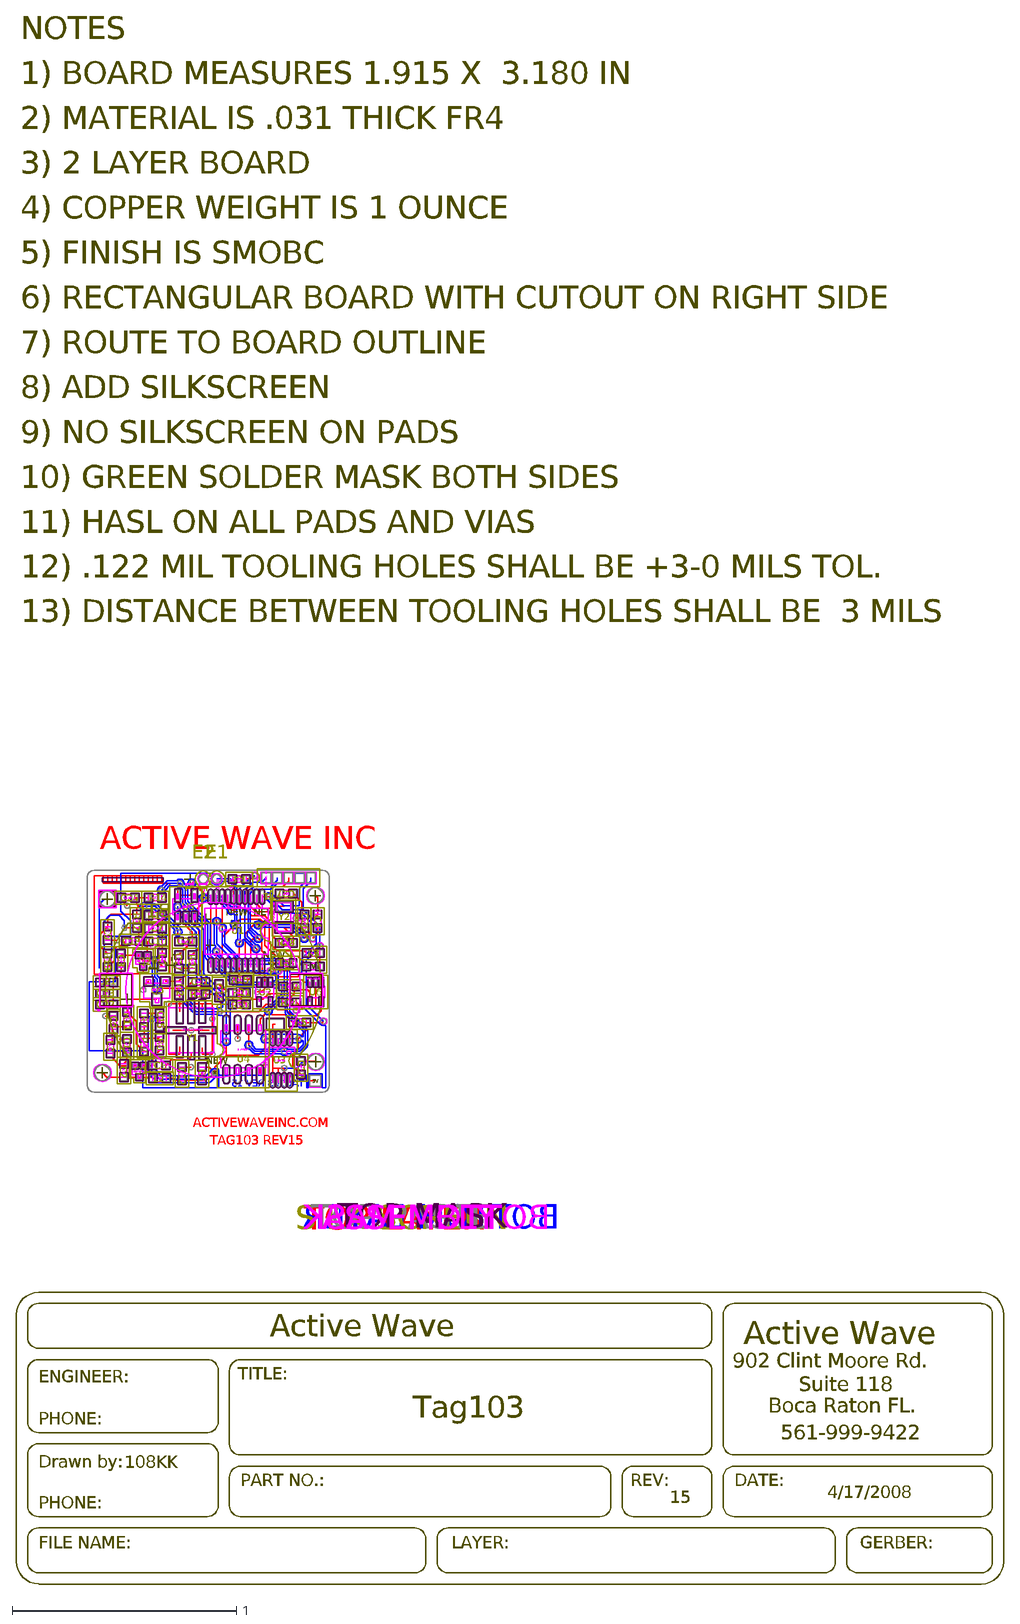
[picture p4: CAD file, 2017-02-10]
protel-files/tags/small-tag/rev15/NewTag Rev15.DXF
ACTIVE WAVE INC
TOP LAYER
TAG103 REV15
ACTIVEWAVEINC.COM
BOTTOM LAYER
TAG103 REV 15
SILK SCREEN
TOP PASTE
TOP MASK
BOTTOM MASK
ASSEMBLY
Tag103
108KK
Active Wave
GERBER:
FILE NAME:
Drawn by:
TITLE:
PART NO.:
ENGINEER:
LAYER:
PHONE:
REV:
DATE:
15
Boca Raton FL.
902 Clint Moore Rd.
561-999-9422
Suite 118
4/17/2008
13) DISTANCE BETWEEN TOOLING HOLES SHALL BE 3 MILS
11) HASL ON ALL PADS AND VIAS
2) MATERIAL IS .031 THICK FR4
9) NO SILKSCREEN ON PADS
8) ADD SILKSCREEN
7) ROUTE TO BOARD OUTLINE
6) RECTANGULAR BOARD WITH CUTOUT ON RIGHT SIDE
5) FINISH IS SMOBC
4) COPPER WEIGHT IS 1 OUNCE
3) 2 LAYER BOARD
10) GREEN SOLDER MASK BOTH SIDES
NOTES
1) BOARD MEASURES 1.915 X 3.180 IN
12) .122 MIL TOOLING HOLES SHALL BE +3-0 MILS TOL.
NEW
3V
.Pattern
.-1
E2
E1
R26
U5
TC1070
U1
PIC16F690
Q2
NE85619
Q1
U2
MIC861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

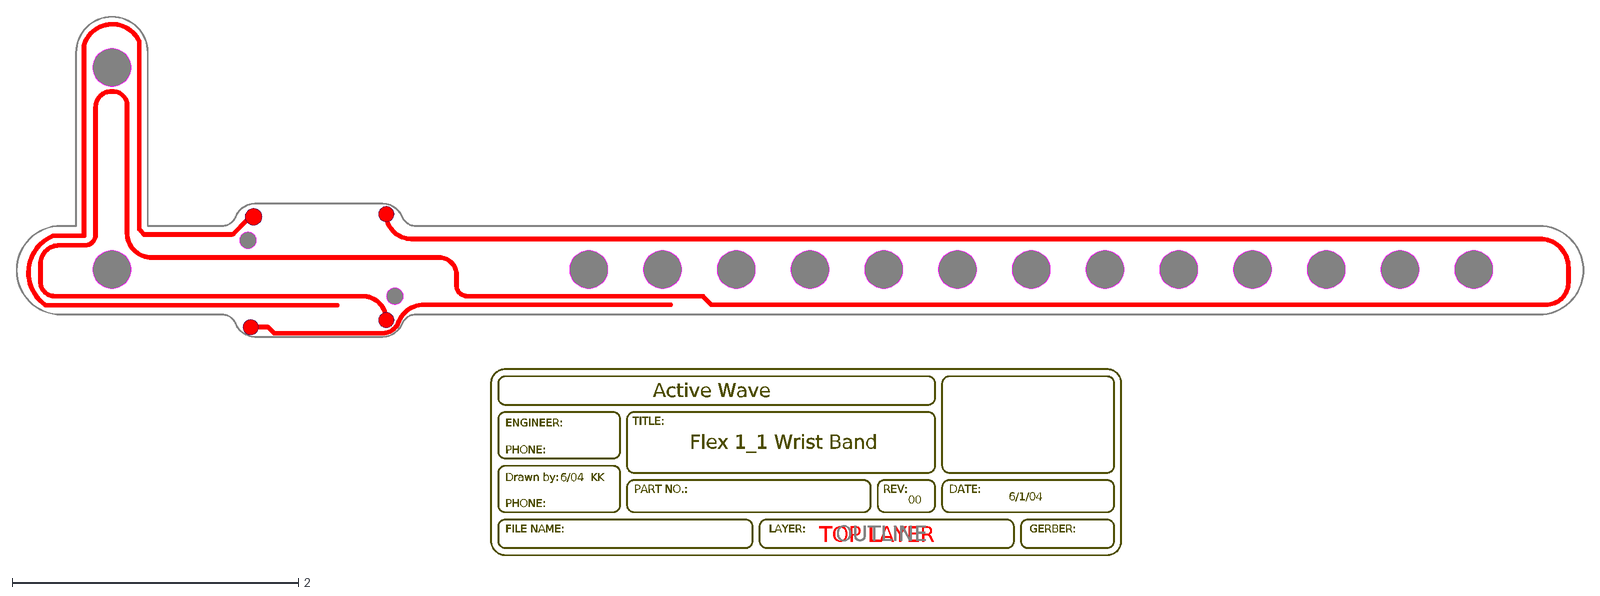
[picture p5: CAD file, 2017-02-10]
protel-files/wristband/flex1/latest/Flex1_1.DXF
TOP LAYER
DATE:
REV:
PHONE:
LAYER:
ENGINEER:
PART NO.:
Flex 1_1 Wrist Band
TITLE:
Drawn by:
FILE NAME:
GERBER:
Active Wave
00
6/04 KK
6/1/04
OUTLINE

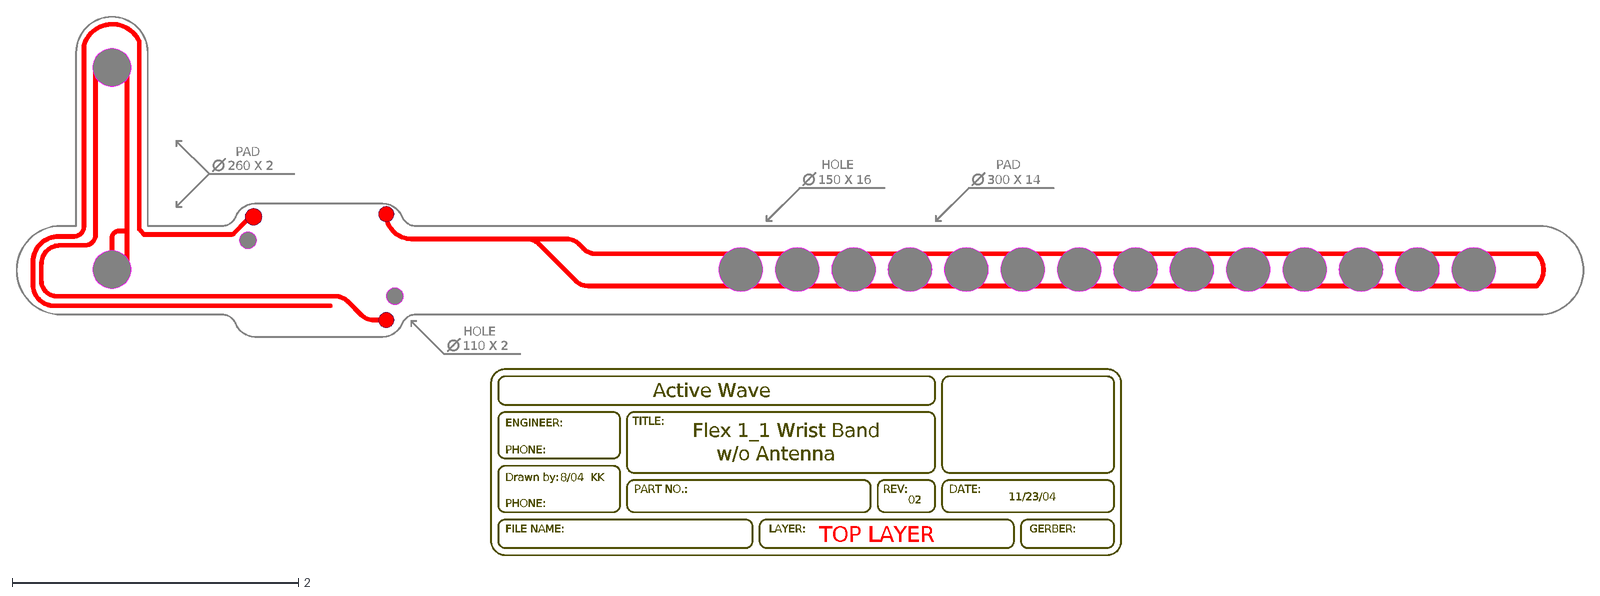
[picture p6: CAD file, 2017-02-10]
protel-files/wristband/rev2/Flex1_1 Rev2 wo ant.DXF
TOP LAYER
8/04 KK
02
Active Wave
GERBER:
FILE NAME:
Drawn by:
TITLE:
Flex 1_1 Wrist Band
PART NO.:
ENGINEER:
LAYER:
PHONE:
REV:
DATE:
w/o Antenna
11/23/04
110 X 2
150 X 16
HOLE
300 X 14
PAD
260 X 2

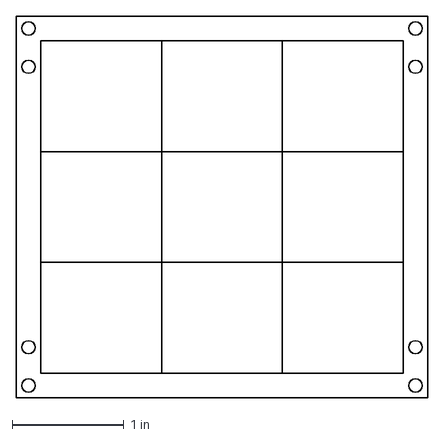
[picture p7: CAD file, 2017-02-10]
sealtag/protel-files/seal-tag/history/rev2-2011-08-03/rev2/201-rev2/PanelDrawingScore.dxf
3.68 x 3.41 in

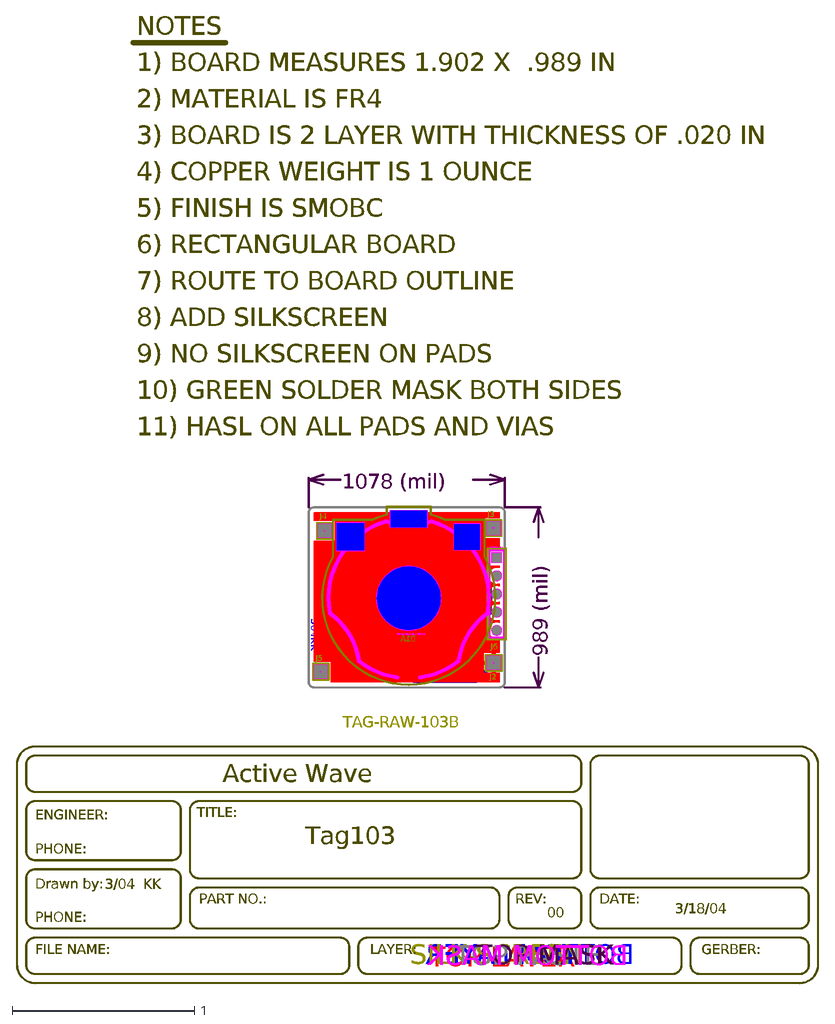
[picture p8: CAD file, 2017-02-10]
protel-files/tags/small-tag/dxf/Mid Layer 2 and Bottom Tag103.DXF
TOP LAYER
BOTTOM LAYER
304KK
TAG-RAW-103B
SILK SCREEN
TOP PASTE
TOP MASK
BOTTOM MASK
3/18/04
3/04 KK
00
Active Wave
GERBER:
FILE NAME:
Drawn by:
TITLE:
Tag103
PART NO.:
ENGINEER:
LAYER:
PHONE:
REV:
DATE:
11) HASL ON ALL PADS AND VIAS
2) MATERIAL IS FR4
1) BOARD MEASURES 1.902 X .989 IN
9) NO SILKSCREEN ON PADS
8) ADD SILKSCREEN
7) ROUTE TO BOARD OUTLINE
6) RECTANGULAR BOARD
5) FINISH IS SMOBC
4) COPPER WEIGHT IS 1 OUNCE
3) BOARD IS 2 LAYER WITH THICKNESS OF .020 IN
NOTES
10) GREEN SOLDER MASK BOTH SIDES
989 (mil)
1078 (mil)
J3
TP
J2
J5
J4
J6
1X5 HEADER
B1A
BATT HOLDER COIN CR2032

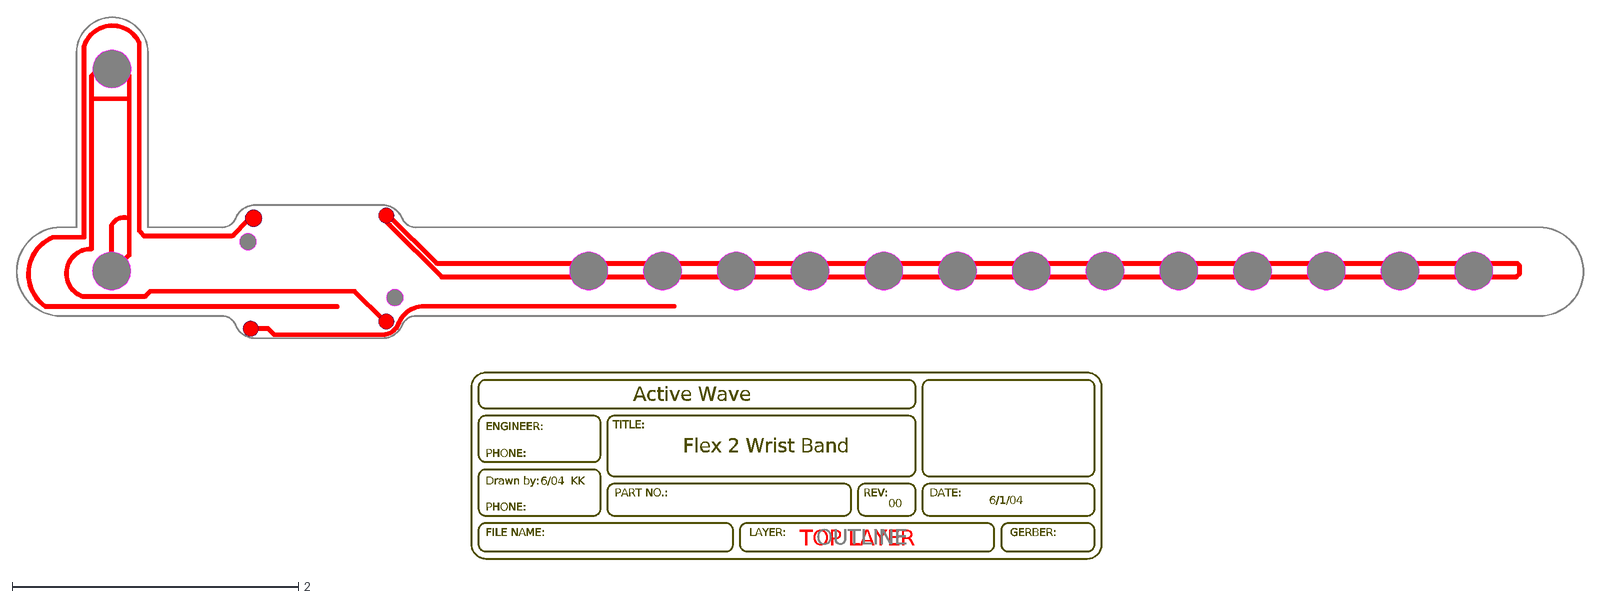
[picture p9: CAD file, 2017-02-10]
protel-files/wristband/flex1/latest/Flex2.DXF
TOP LAYER
DATE:
REV:
PHONE:
LAYER:
ENGINEER:
PART NO.:
Flex 2 Wrist Band
TITLE:
Drawn by:
FILE NAME:
GERBER:
Active Wave
00
6/04 KK
6/1/04
OUTLINE

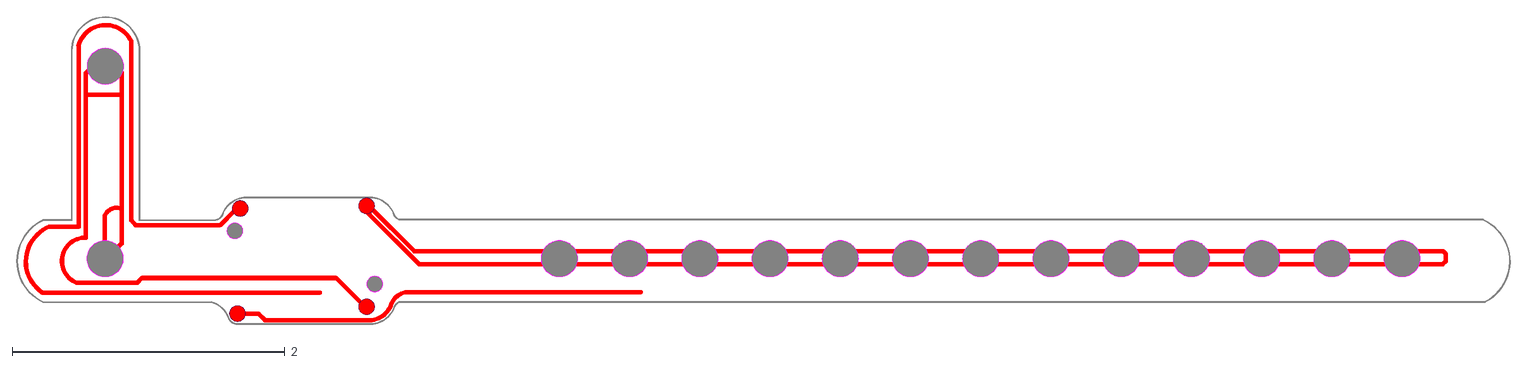
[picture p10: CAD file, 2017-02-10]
protel-files/wristband/flex1/latest/Flex1.DXF
11.0 x 2.26

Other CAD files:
protel-files/tags/small-tag/dxf/tension-spring.dwg
sealtag/software/seal-tag-manufacturing-release-code/STVP/touraj.stp
software/programming-station/Programming Station 190/Programming Station 190/Object/AWSocketUnit.obj
software/programming-station/Programming Station 190/Programming Station 190/Object/FileSysMsgUnit.obj
protel-files/tags/small-tag/dxf/Top and Mid layer1 Tag103.DXF
software/programming-station/Programming Station 190/Programming Station 190/Object/ScanUnit.obj
software/programming-station/Programming Station 190/Programming Station 190/Object/ReadLargeDataUnit.obj
software/programming-station/Programming Station 190/Programming Station 190/Object/ConfigProgStationUnit.obj
software/programming-station/Programming Station 190/Programming Station 190/Object/AboutUnit.obj
protel-files/reader/reader-103/datasheets/1803280.dxf
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

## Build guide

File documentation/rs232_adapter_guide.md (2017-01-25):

# RS232 Adapter Guide

RS232 | USB Cable
--- | ---
Pin 1 | GND (Black)
Pin 2 | NC
Pin 3 | PWR (Red)
Pin 4 | TXD (White)
Pin 5 | RXD (Green)

PCB | Male Pins to PCB
--- | ---
Pin 1 | PWR (Red)
Pin 2 | RXD (White)
Pin 3 | TXD (Green)
Pin 4 | NC
Pin 5 | GND (Black)

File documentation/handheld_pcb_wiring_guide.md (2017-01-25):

# Handheld PCB Wiring Guide

**Wiring instructions for programming the microcontrollers on the Handheld Reader PCB**

Notes:

* To program microcontroller C, D and E on the Handheld Reader, you must go to the respective J connector for that controller.

* J101 is for microcontroller C, J102 is for microcontroller D, and J103 is for microcontroller E

* Solder the wires from the 5-pin adaptor connector to the correct J connector of the microcontroller you wish to program.

* Use a female 5-pin connector for programming the Handheld Reader

Pin | Wire
--- | ---
Pin 1 | White wire to J101pin1 or J102pin1 or J103pin1
Pin 2 | Green wire to J101pin2 or J102pin2 or J103pin2
Pin 3 | Purple wire	to J101pin3 or J102pin3 or J103pin3
Pin 4 | Black wire to GND TP20
Pin 5 | Red wire to VCC TP19#RS232 Adaptor Guide

RS232 | USB Cable
--- | ---
Pin 1 | GND (Black)
Pin 2 | NC
Pin 3 | PWR (Red)
Pin 4 | TXD (White)
Pin 5 | RXD (Green)

PCB | Male Pins to PCB
--- | ---
Pin 1 | PWR (Red)
Pin 2 | RXD (White)
Pin 3 | TXD (Green)
Pin 4 | NC
Pin 5 | GND (Black)

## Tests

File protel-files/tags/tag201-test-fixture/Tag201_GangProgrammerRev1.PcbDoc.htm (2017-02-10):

Altium Reporting Options

# File in Newer Format

Date | : | 5/16/2013
Time | : | 7:21:22 AM
Filename | : | C:\ActiveWave\Protel Files\Tags\tag201 test fixture\Tag201_GangProgrammerRev1.PcbDoc

Version | Warning
Summer 09 | CAUTION - File contains new custom violations that replaced the old violation objects. These violations were introduced in Altium Designer Summer 09. The new custom violations will be discarded.
Summer 09 | CAUTION - Support was added for 32 Mechanical Layers. Objects on mechanical layers beyond 16 have been moved to Mechanical Layer 16.
Summer 09 | CAUTION - File contains assembly testpoint rules and/or settings. Assembly testpoint information will be discarded.
Release 10 | CAUTION - New Custom Grids and Guides were introduced. Be aware that your design might contain Custom Grids and Guides that cannot be read in previous versions.
Release 10 | CAUTION - New Structured Clusters were introduced. Be aware that your design might contain Structured Clusters that cannot be read in previous versions.
Release 10 | CAUTION - New PCB 3D Movie Manager was introduced. Be aware that your design might contain 3D PCB movie that cannot be read in previous versions.
Release 10 update 1 | CAUTION - New Clearance Rule subscopes targeting differential pairs were introduced. Be aware that your design might contain Clearance Rules using those subscopes that cannot be read in previous versions.
Release 10 update 15 | CAUTION - Support of Solder Mask and Paste Mask expansions for Tracks, Arcs, Fills and Regions was introduced. Be aware that your design might contain Solder Mask and Paste Mask expansions for these types of primitives that cannot be read in the version of Altium Designer you are currently using.

This file was generated by a later version of the software

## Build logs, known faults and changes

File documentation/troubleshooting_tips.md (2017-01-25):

# Tags - Troubleshooting

**Note:** These are results that were located in a document. Eventually, we would hope a standardized troubleshooting/testing setup will be created and this document can be archved.

**Note:** This setup is for a Reader or use of a Reader and Smart Field Generator.

## RSSI Changes

Variable | Value
--- | ---
C51 | 10ohms
R47 | 1000ohms
R10 | 10ohm
R2 | DNP

_Note:_ Tune the sensitivity on the oscilloscope until you get the signal.

## Modification Procedures

**Perform these steps before performing any testing.**

### Transceiver Modification Procedures

1. C46 should be changed from 6pf to 8pf. This will provide better results if you have any transmitting signal problems on either 868.92MHz or 916.5MHz.

2. For the old transceiver: Cut the trace in both side of L13 and add an 18nH that actually replaces L13.

3. Threshold has to be set to 1.67K ohms in order to have good communication between the Reader and the Smart Field Generator.

4. Do not populate R6 which is a 10K ohms resister in any transceiver, no exception.

**These changes are optional.**

### Extend the Read Range on the Transceiver

1. R3 should be changed from a 22ohms resistor to a 10ohms resistor

2. L2 should be changed from 18nH to 8.2nH.

3. For TRX 141, Rev 19, changing C33 from 2pf to 2.7pf and C35 from 7pf to 10pf, the read range of the transceiver was extended.

### Extend the Read Range on the Tag

* Change R24 from 100K ohms to 150K ohms.

_Note: This will increase power consumption by a significant amount._

### Tilt Switch Modification

1. Change C16 to 0.01uf, C25 to 27pf, R25 to 39K, and R27 to 10M in order to make the tag work.

2. After making those chagnes, enable the tilt switch and the tamper control before programming the tag.

### Indian Market Modifications

_Note: To tune 867MHz to 335MHz, change C33 to 2pf and C35 to 18pf._

#### Tag 105

1. Make sure the saw resonator is 867MHz.

2. Make sure the transmitter cap C2 has been changed to 2.7pf, C19 to 4.7pf, and C21 to 5.0pf or higher.

3. In order to tune the 867MHz tag to a 335MHz receiver, C2 to 2.2pf, C10 should be changed to 2700, C19 to 5.6pf, C21 to 6.2pf (or around there), and R17 to 1.3K ohms.

#### Field Generator

1. Make sure C10 has been changed to 100pf, C14 to 18pf, C15 to 5pf, C37 to 2.2pf, L4 to 15nH, L10 to 220nH, and L12 to 22nH.

2. C8 should remain 2pf.

#### compactTag

* Make sure C2 has been changed to 4.0pf, C7 to 220pf, C13 to 33pf, C19 to 3.0pf, C21 tp 6.21pf or high, L2 to 6.8nH, L4 to 12nH, L6 to 100nH, and R17 to 1.3K ohms.

#### Compact Flash Card

1. Make the following changes:

Variable | Value
--- | ---
C28 | 100pf
C30 | 5pf
C33 | 2pf
C35 | 18pf
C45 | 2.2pf
L3 | 18mH
L7 | 220nH
L8 | 100nH
L9 | 22nH
L12 | 15nH
R23 | 6.8k ohms
R24 | 2.7K ohms
R27 | 51ohms
R30 | 10 ohms

_Note: match the threshold to 1.702K ohms when measuring._

### Compact Flash Card Reader (All)

1. The threshold should be with the 5k pot equal to 1.5K ohms, or sometimes a little bit more based on how you direct your hand. Also the 2K pot should euqal 2.0k or a little more, depending on how well the pot is calibrated.

2. When R27 equals 51 ohms, it creates a short from Q10 and R27, which casuses the handheld to perform in unexpected ways. The read range is very short because of the value of R27. To solve that problem, you need to go ahead and change the value from 51 ohms to the original value of 560 ohms and threshold to 2k ohms.

### Field Generator Modification

* To change from low to high power and still be able to read the tags, chagne R5 from 470 ohms to 6.8K ohms. This will make a significant difference on power consumption.

### 868.92Mhz Transceiver Modification

1. Changing C56 to 4.7pf and L19 to 5.6nH, a filter is added to reduce teh noise level.

2. After performing a complete test, change C33 to 3pf, C35 to 10pf, R24 to 2.7K ohms, and R27 to 51 ohms. This will increase the read range from a shorter distance to a longer distance. The threshold should be equal to 1.67K ohms on 5K and 2.0K on R7.

_Note: Changing C33 and C35 is for 433.92MHz - it allows the signal to move closer to the center when measuring or testing the trtansceiver._

### 905.8 MHz Transceiver Modification

1. Change L5 to 5.6nH, C19 which is the one connected directly to L5 to 22pf, C9 to 0.5pf, and C23 to 8pf

2. Leave C19 empty.

### 916.5Mhz Transceiver Modification

1. Changing C56 to 4.7pg nd L19 to 5.6nH adds a filter and reduces the noise levels.

2. After performing a complete test, change C33 to 3pf, C35 to 10pf, R24 to 2.7K ohms, and R27 to 51 ohms. This will increase the read range from a shorter distance to a longer distance. The threshold should be equal to 1.67K ohms on 5K and 2.0K on R7.

_Note: Changing C33 and C35 is for 433.92MHz - it allows the signal to move closer to the center when measuring or testing the trtansceiver. If after having performed these modifications and the transceiver still doesn't work, change the 433.92 saw resonator._

### Field Generator Modifications

* Change R5 from 470 ohms to 6.8K ohms and R19 to 2.7K ohms. This will increase the field generator's performance.

### Conversion of a compactTag to a Field Geneartor

By adding a Field Generator microchip to a compactTag, it will allow the compactTag to function like a regular Field Generator.

1. All the pins except for 1, 4, 7, 16, 17, 18, 19, and 20 must be cut from the IC must be cut before soldering.

2. Replace Y1 from either a 868.92MHz saw resonator or a 916.5MHz saw resonator to a 433.92MHz saw resonator.

3. Make the following changes:

Variable | Value
--- | ---
C2 | 12pf
C19 | 10pf
R7 | 36.5K

4. Pin 16 from the processor must be connected to the top of R2.

5. Run a wire from the bottom of R26 to pin 7 of the microchip.

6. Run a wire from R25 to the top of R5.

7. The tilt switch component requires C16 to be 0.1uf, C25 to be 2200pf or 2.2nf, R25 to be 100K, and R26 to be 10M. Also, the tilt switch should be on the bottom.

8. Based on the value of the cap used for C2, it should be 12pf or somewhere around there.

9. By replacing C2 from 12pf to either a higher or lower value, you will change the position of the signal. If you put a lower value, the signal will shift to the right of the spectrum analyzer and a higher value shift to the left of the spectrum analyzer.

10. The reason for changing C2 is because we want to tune the 433.92MHz frequency to the center. By doing sow, we end up with the following values:

_Leave the antenna open on all of these._

Tags 1, 3, and 4

Variable | Value
--- | ---
C2 | 12pf
C19 | 10pf
L4 | 10nH
R6 | 120 ohms
R7 | 43K ohms

Tag 2

Variable | Value
--- | ---
C2 | 12pf
C19 | 10pf
L4 | 10nH
R6 | 120 ohms
R7 | 47K ohms

## Troubleshooting Procedures

### 868.92Mhz transceiver

1. Threshold always set to 3.6volts with this setup - the sensitivity should not be significantly affected.

2. Sensitivity will have to be around -97.5 or higher in order to have a good read range.

3. When checking the 433.92MHz, pay very close attention to see where the signal is located. Based on my reading, I was able to see the 433.92MHz go as high as 49.2DBM.

4. The transmit signal has reached as high as -9.7DBM.

5. The threshold should always be set at 4.3volts with this set up - the transceiver should always provide good results.

### 916.5Mhz transceiver

1. Threshold always set to 4.3volts with this setup - the sensitivity should not be significantly affected.

2. Sensitivity will have to be around -97.5 or higher in order to have a good read range.

3. When checking the 433.92MHz, pay very close attention to see where the signal is located. Based on my reading, I was able to see the 433.92MHz go as high as 49.2DBM.

4. The transmit signal has reached as high as -9.7DBM.

5. The threshold should always be set at 4.3volts with this set up - the transceiver should always provide good results.

## Troubleshooting Tips

### Reader

1. When there’s no communication from the Reader whenever you try to call a tag or L3 is very hot, check C14 to make sure it’s not backwards. If it is, change it to match the polarity.

2. When the Reader is plugged in and the system does not recognize it, meaning that you don’t hear any noise from the system, make sure the two transistors on the bottom of the C memory chip are properly soldered.

3. If there is no response from the Reader when calling the tag, first check to see if there’s unsoldered components. If so, solder them and recheck the Reader.

### Transceiver

1.  Sensitivity cannot tune anything lower than 40 or 50 DBM.

2. Check cap by J3 to make sure it is 100pf. If you are unsure, change it to 100pf to be sure.

3. If after changing it, it still does not work, change U1 which is BGA 2001

4. If you are still having problems, check Y1 and Y2 for missing solder or just change them both.

### Weak signal

1. Make sure the cap by J3 is 100pf, then retune the transceiver once again.

2. If the transceiver is still weak, change U4.

3. If the transceiver is still weak, change U3.

### 433.92MHz does not transmit

1. Check for unsoldered components in the receiver area.

2. If that does not work, change Q5 above C32.

### Transceiver remains at 0 volts

1. Check the polarity on Y1 and Y2 and make sure they are both mounted with the correct side of polarity on the board.

2. If that does not work, change both of them at the same time.

### Threshold does not adjust

1. On Rev 16, change U4 first before changing U3.

2. If threshold does not adjust, double-check C24 to make sure it is 1pf. 

### Short-range Transceiver modification

1. C8 and C19 needs to be changed to .5pf.

2. C2 needs to be changed to 2pf, but it may sometimes vary.

### Reader does not reset

1. Inspect the entire Reader and look for unsoldered parts

2. Inspect the entire Reader and look for shorts

_Note:_ Focus mainly on the two resistors above the E chip.

### Transceiver does not transmit

1. Check for unsoldered part in the transmitter area.

### Transceiver has a very short range

1. Change all the caps - C38, C39, and C2 - to .5pf

2. Change C34 to 27pf and remove the antenna connector

3. Add a 50ohms resistor across or reduce the threshold.

### compactTag, 102 does not respond

1. Change Q3 (which is the transmitter) and then the C3 cap, which plays a big role on the tag (it allows you to tune it to the exact frequency you want from 433MHz to 440Mhz).

2. If there is no receiver signal, check for areas lacking solder or parts in the receiver area.

3. If that doesn't fix it or if the tag doesn't respond, change the Q2 transistor, which controls the receiver and transmitter signal.

### A 102 tag doesn't have data

* U6 could be bad, especially if the tag has been used before.

### Tag 103 Rev 18 issues

1. When placing a tag on a fixture, you should have perfect signal - there shouldn't be any shorts.

2. If there is a short, remove the battery holder next to the positive.

3. If you see a test-point, remove it to prevent a short between the ground and the positive.

### Tag 105 issues

1. Make sure there is enough solder paste.

2. Make sure R21 and U2 are installed and that U2 and U5 are not off pad- these cause issues with the receiver area.

3. If there is no transmitter signal, make sure the 1000pf from C8 and C10 do not have a manufacturing defect. One perfect way you can manage that is by touching the end of the cap with a soldering tap - if it cracks in half, it means the cap is bad and you need to replace it with a new one and recheck the tag. Consider a new manufacturer if the problem is persistent.

4. If the 433.92MHz signal does not appear, C4 - which is .1uf - may be bad. Touch the end of one side with your hot soldering iron - if it cracks in half, it means the cap is bad and you need to replace it with a new one and recheck the tag. Consider a new manufacturer if the problem is persistent.

5. If the 433.92MHz signal looks strange or narrow, chances are C10 - which is 100pf - may be bad and need to be changed.

6. When placing the battery, if you do not see the tag on the screen, your program is corrupted. Reprogram the tag.

### Buzzer issues

1. If the buzzer on any tag is not beeping, chances are you have a low voltage battery or Q4 may be bad.

2. If the buzzer's volume is very low, replace the battery with a higher voltage one.

3. If either the buzzer or the LED (or both) do not work, first change the components around them. If that doesn’t fix it, replace the buzzer.

### Reader keeps automatically resetting

1. Change the switch - a bad switch will put the Reader in an automatic reset loop.

2. If the issue continues, it may be the RS232, itself.

3. If one of the processors has a bridge, it will cause the automatic reset loop. Re-solder the processor one-by-one, starting with the D processor.

### Reader LED keeps flashing

1. If one of the LEDs keeps flashing when programming the Reader, the switch may be bad and need to be changed. Use the same method when you plug in the tag and no sound comes out of it, meaning that you plug in the tag and you do not hear any sound from the computer.

### Compact Flash Card

_Note: When measuring the threshold on the CF card, when you power down the reader, the reading from the top side of R11 should be 1.9K or 2K. When you power it back up, you should have a reading of 4.6K to 4.8K from the top side of R11._

### Special Notes For new CF Card Reve0: Upgrade

1. After performing a complete test, we realized that some changes need to be applied on the transceiver. R23 should be 3.3K ohms, C33 should be 2pf, C35 should be 7pf, L8 should be 47nH or 60nH, R48 should be 2.7K ohms, C56 shold be 4.7pf, and L19 should be 5.6nH.

2. With the digital area populated on the CD Card, there will not be a long read range. However, removing R113, R114, R115, R116, R117, R122, and R123, it should be fine.

### Transceiver Sensitivity Issues

1. To reduce/remove sensitivity, make sure C9 is equal to 0.5pf, C23 is 8pf, and then populate.

2. When the 905.8MHz frequency transmitter signal is there but not snesitive enough after having changed most parts, change the U8 chip.

3. When the 905.8MHz frequency transmitter signal is not there, sometimes C23 can be a different value, just keep changing from high to low. For example, when C9 is 0.5pf and C23 is 8pf, there is no signal. Changing C23 from 8pf to 3pf will result in signal coming back.

### compactTag

* When Q4 is populated and the buzzer is not populated, calling the tag will not work. Either remove Q4 or populate the buzzer. For the sake of the battery, it is best to remove both.

### compactTag Rev 20

1.	In the receive area, change C7 to 100PF and C3 from 2pf to 7.0pf. This change shifts the signal to the left of the analyzer.

2. C21 should be changed from 1.8pf to 0.5pf or 1pf. This shifts the signal to the right fo the analyzer, allowing you to perform your tuning.

3. Change C13 from 33pf to 27pf. This shifts the signal to the right of the analyzer.

### Latest Reader issues

1. When plugging in the Reader after having populated it, U23 gets very hot. Most likely, the chip is bad. Replace it with DigiKey Part # IS768-1008-ND and MFG P/N: FT232RQ-REEL (IC USB FS SERIAL UART 32-QFN)/

2.	When everything on the reader works but calling a tag does not result in deteing a tag, most likely R69 may be a different value. The value on R69 is supposed to be a 0 ohm resistor.

### Tag becomes detuned

* Sometimes, there is a short in the transmitter that results in the tag being detuned. Please refer to the tag's schematic and check the transmitter area. For example, Tag 105 Rev 20 was detuned, so we looked at the transmitter area. In particular, C2 and C19. By changing C2 from 2.7pf to 1.8pf, it shifted our transmitter signal to the right and the tag performed much better.

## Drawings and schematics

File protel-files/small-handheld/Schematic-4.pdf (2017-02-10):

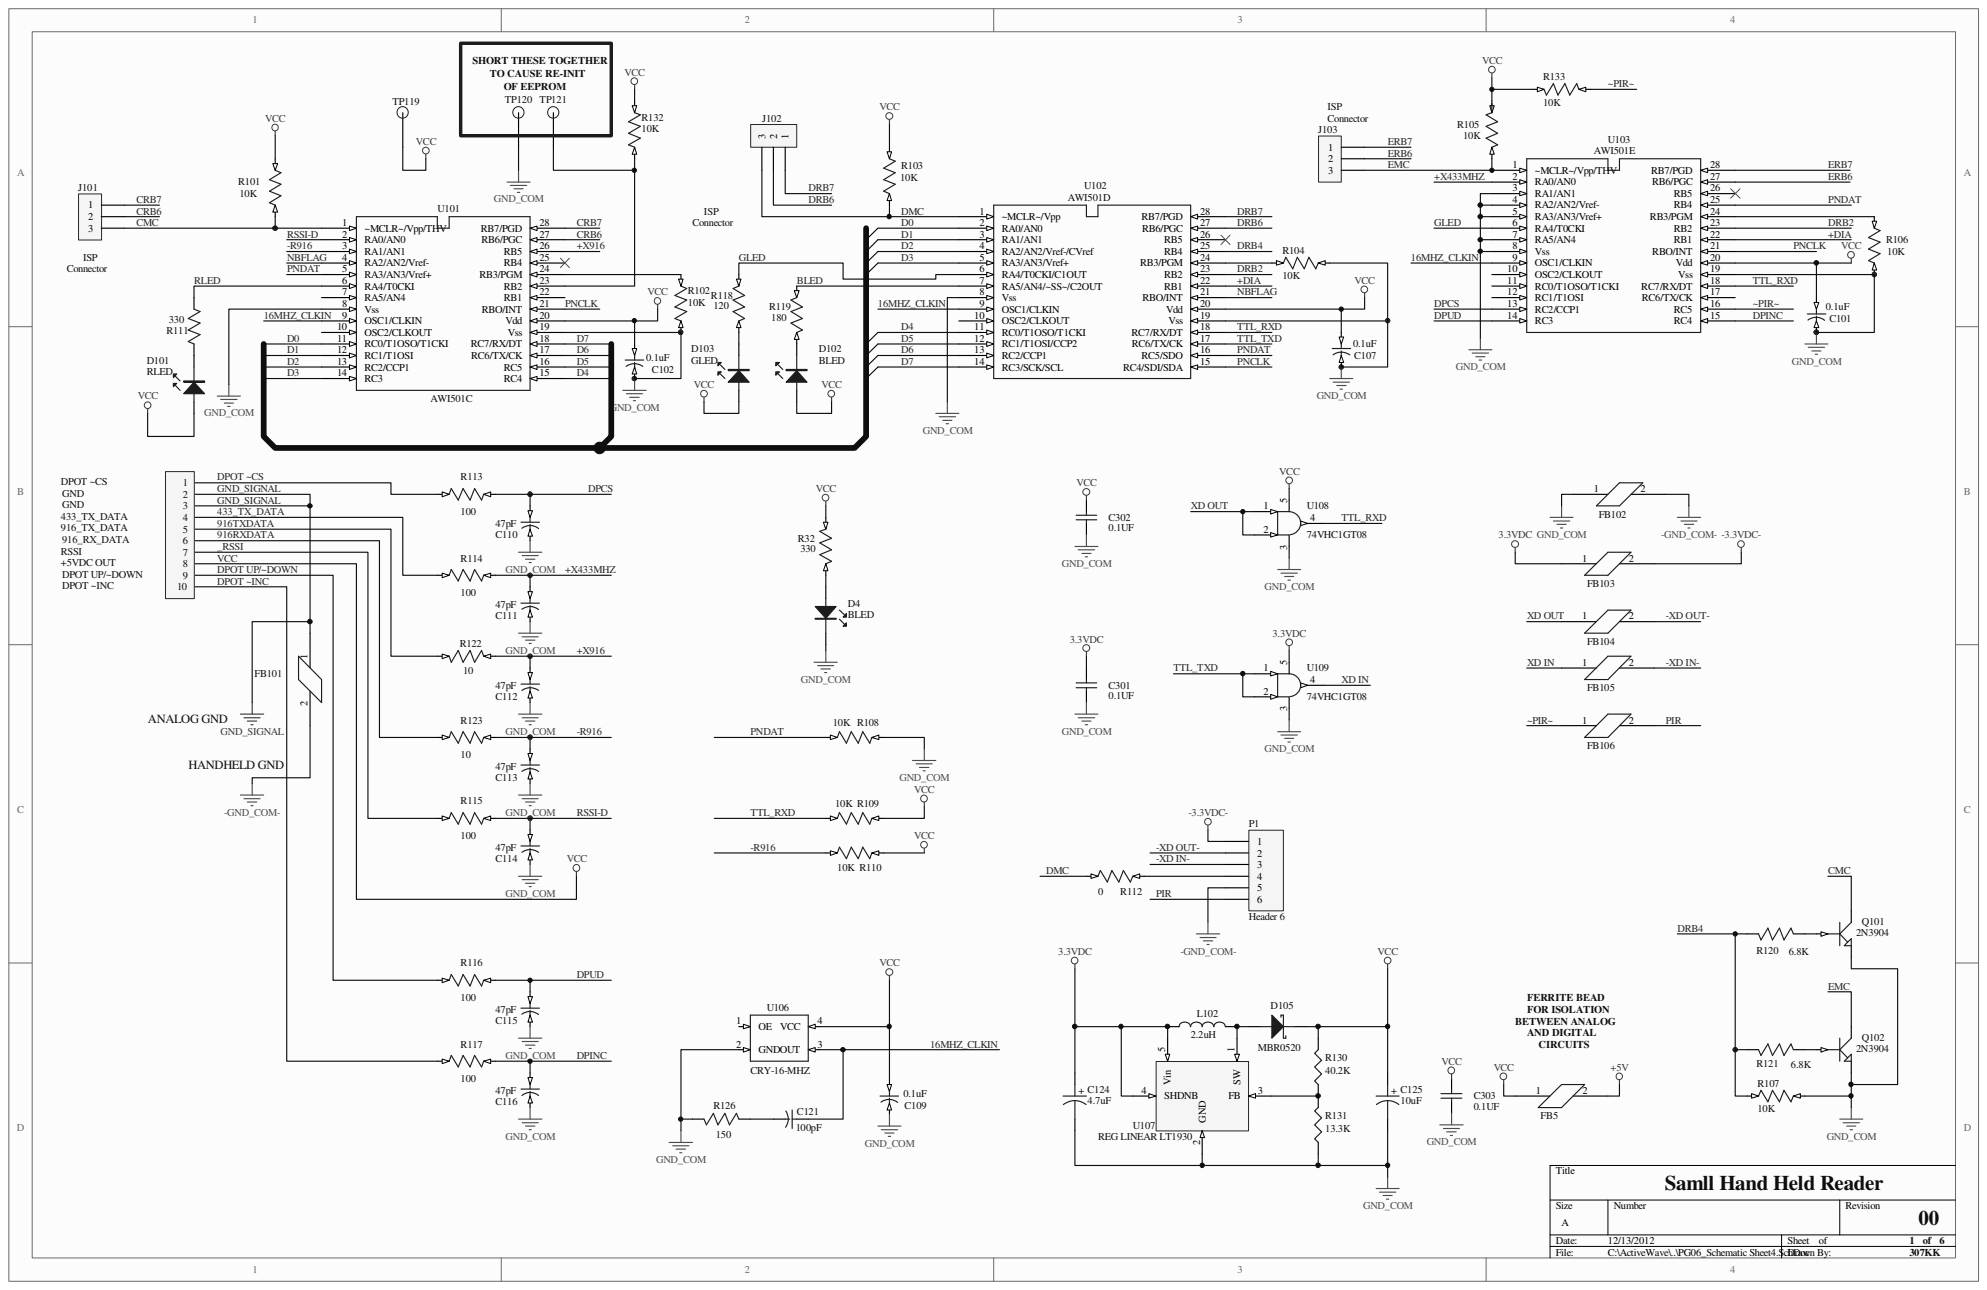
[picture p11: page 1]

SHORT THESE TOGETHER
TO CAUSE RE-INIT
OF EEPROM

GND_COM
PIR -XD OUT- -XD IN-

Samll Hand Held Reader

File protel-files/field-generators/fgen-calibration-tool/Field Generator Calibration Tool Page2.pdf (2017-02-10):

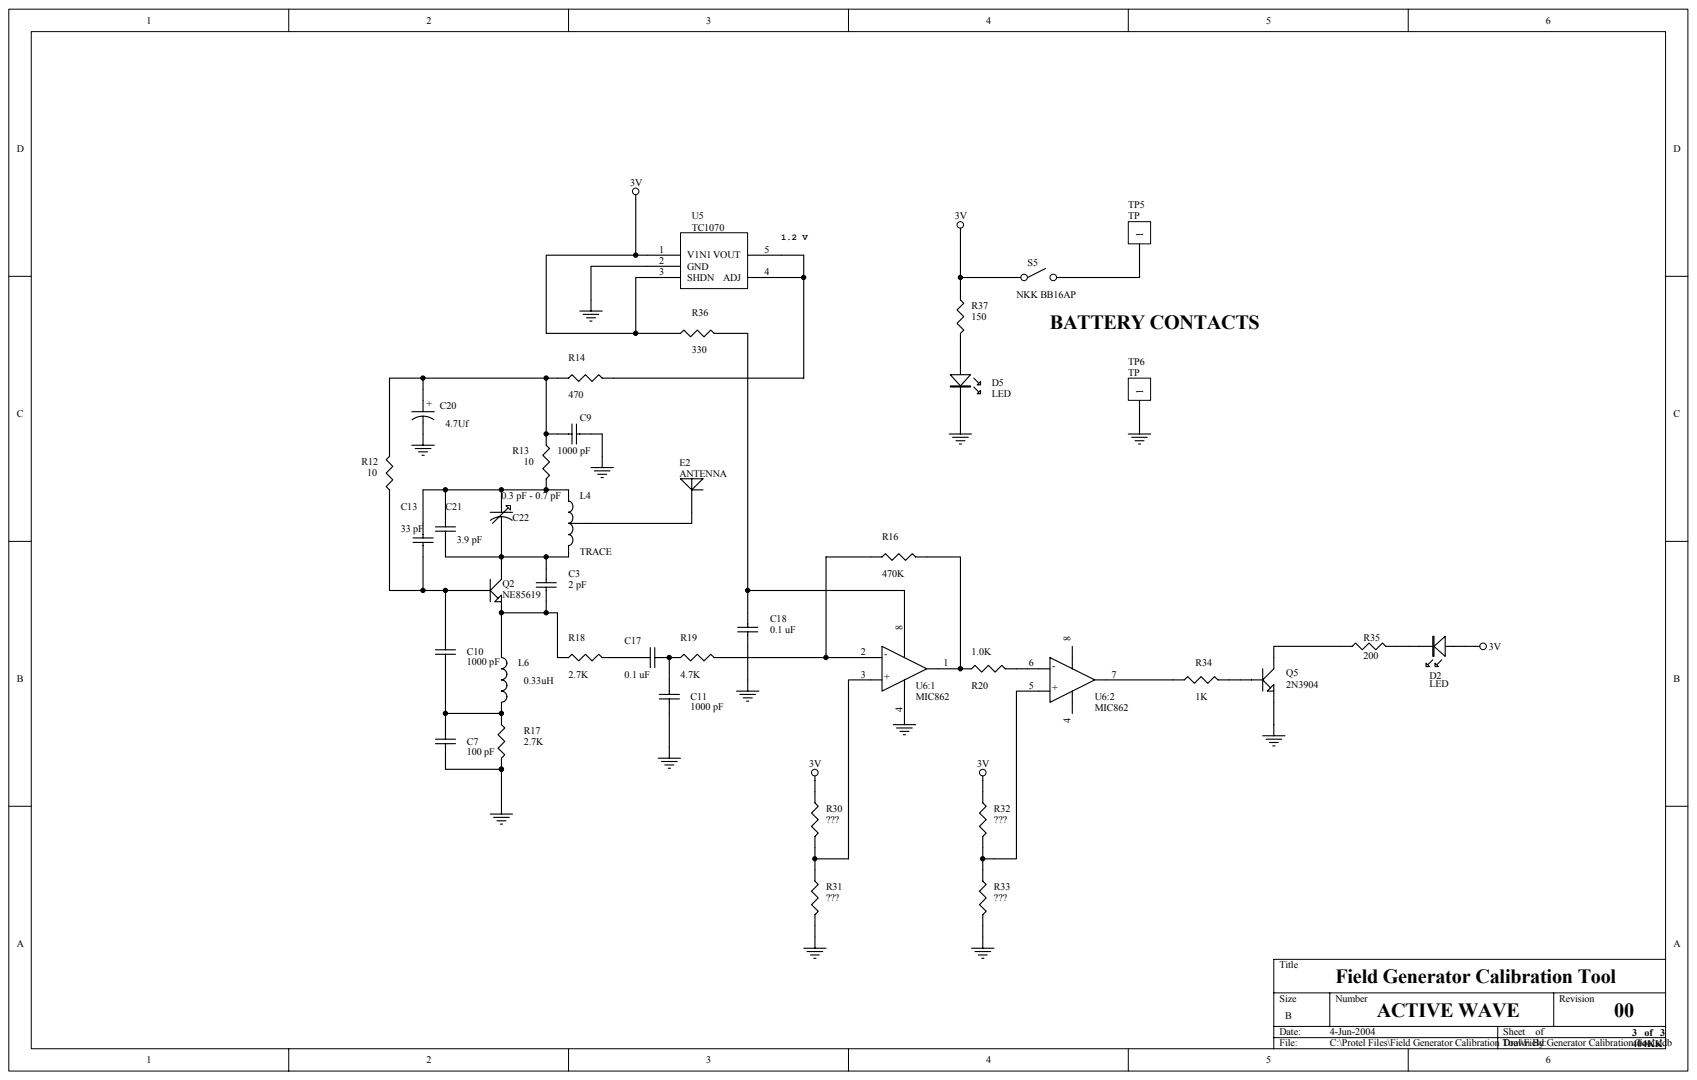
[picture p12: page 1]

Title
Field Generator Calibration Tool

Size B | Number ACTIVE WAVE | Revision 00

Date: 4-Jun-2004 | Sheet of 3 of 3
File: C:\Protel Files\Field Generator Calibration Tool\Field Generator Calibration Tool.ddb Drawn By: | 404KK

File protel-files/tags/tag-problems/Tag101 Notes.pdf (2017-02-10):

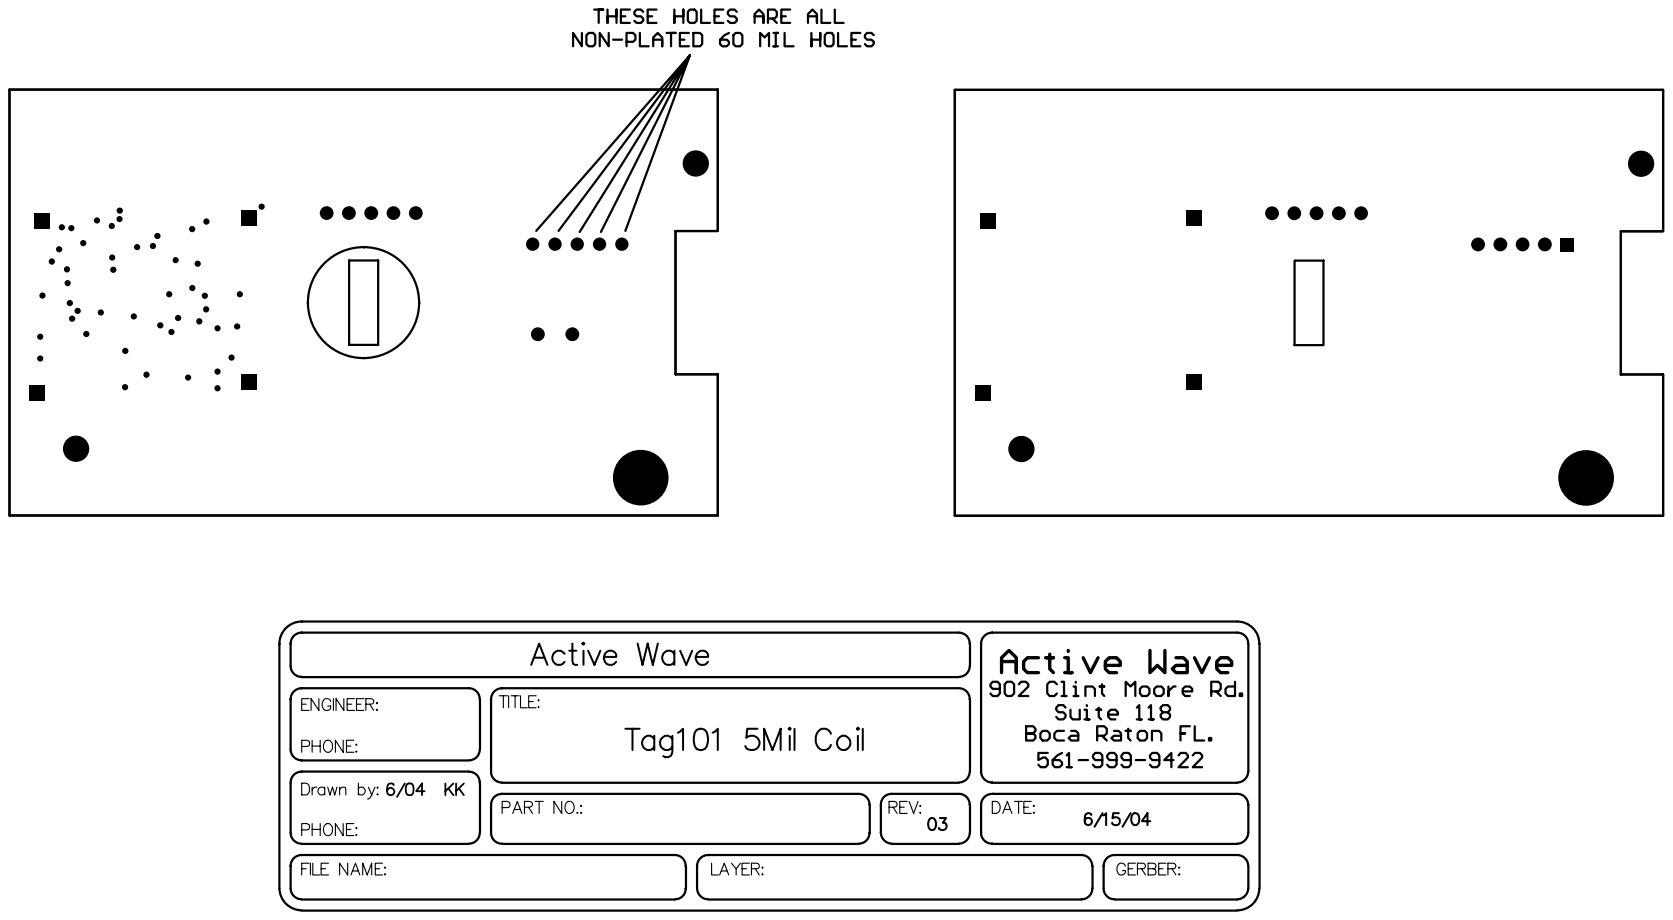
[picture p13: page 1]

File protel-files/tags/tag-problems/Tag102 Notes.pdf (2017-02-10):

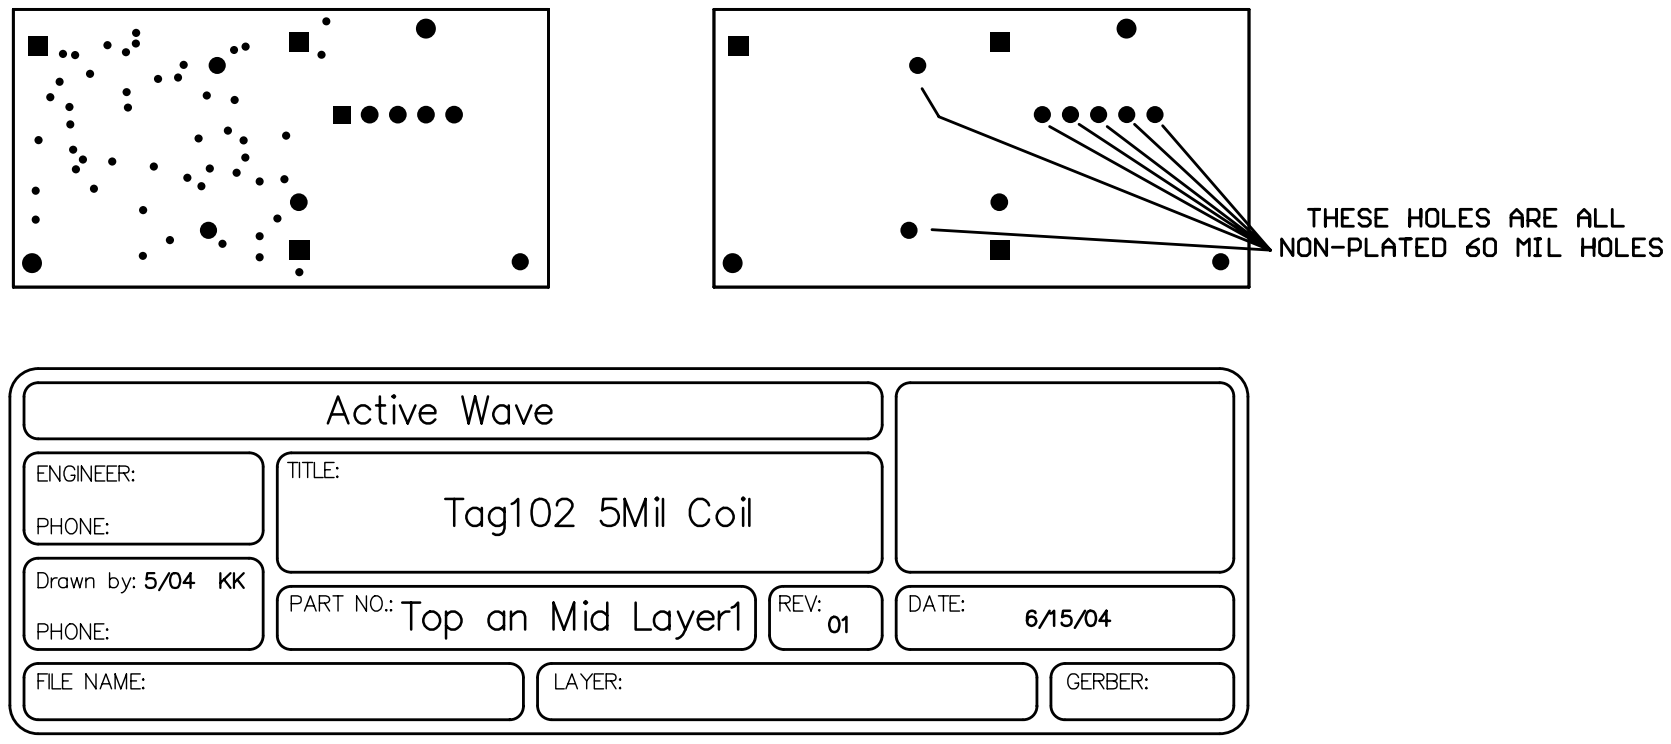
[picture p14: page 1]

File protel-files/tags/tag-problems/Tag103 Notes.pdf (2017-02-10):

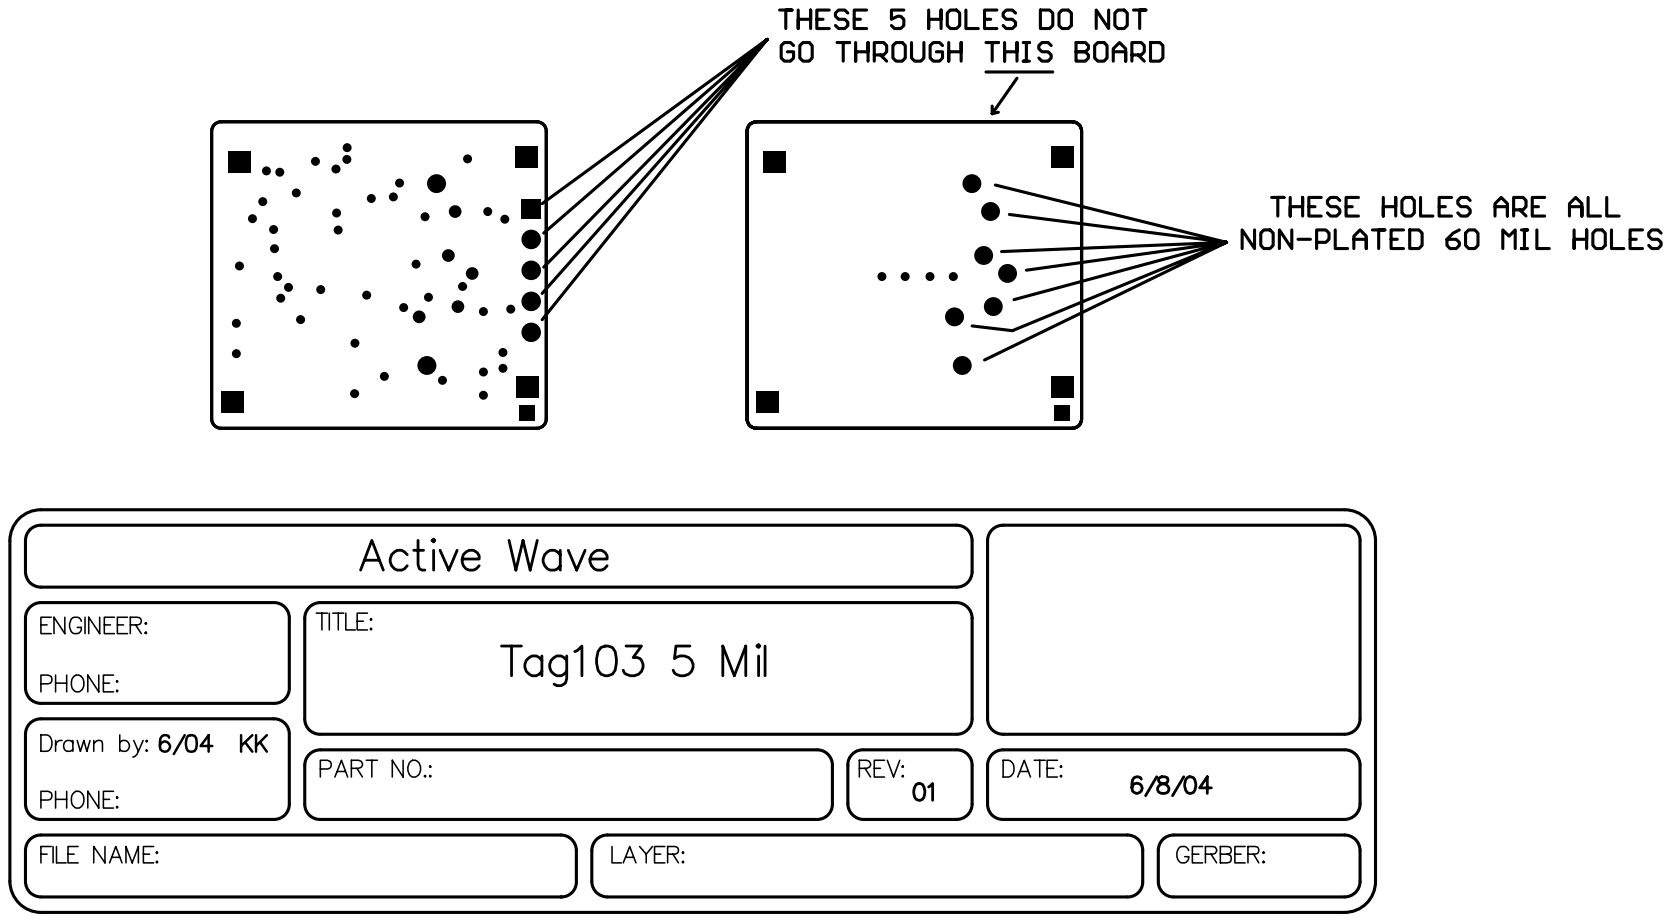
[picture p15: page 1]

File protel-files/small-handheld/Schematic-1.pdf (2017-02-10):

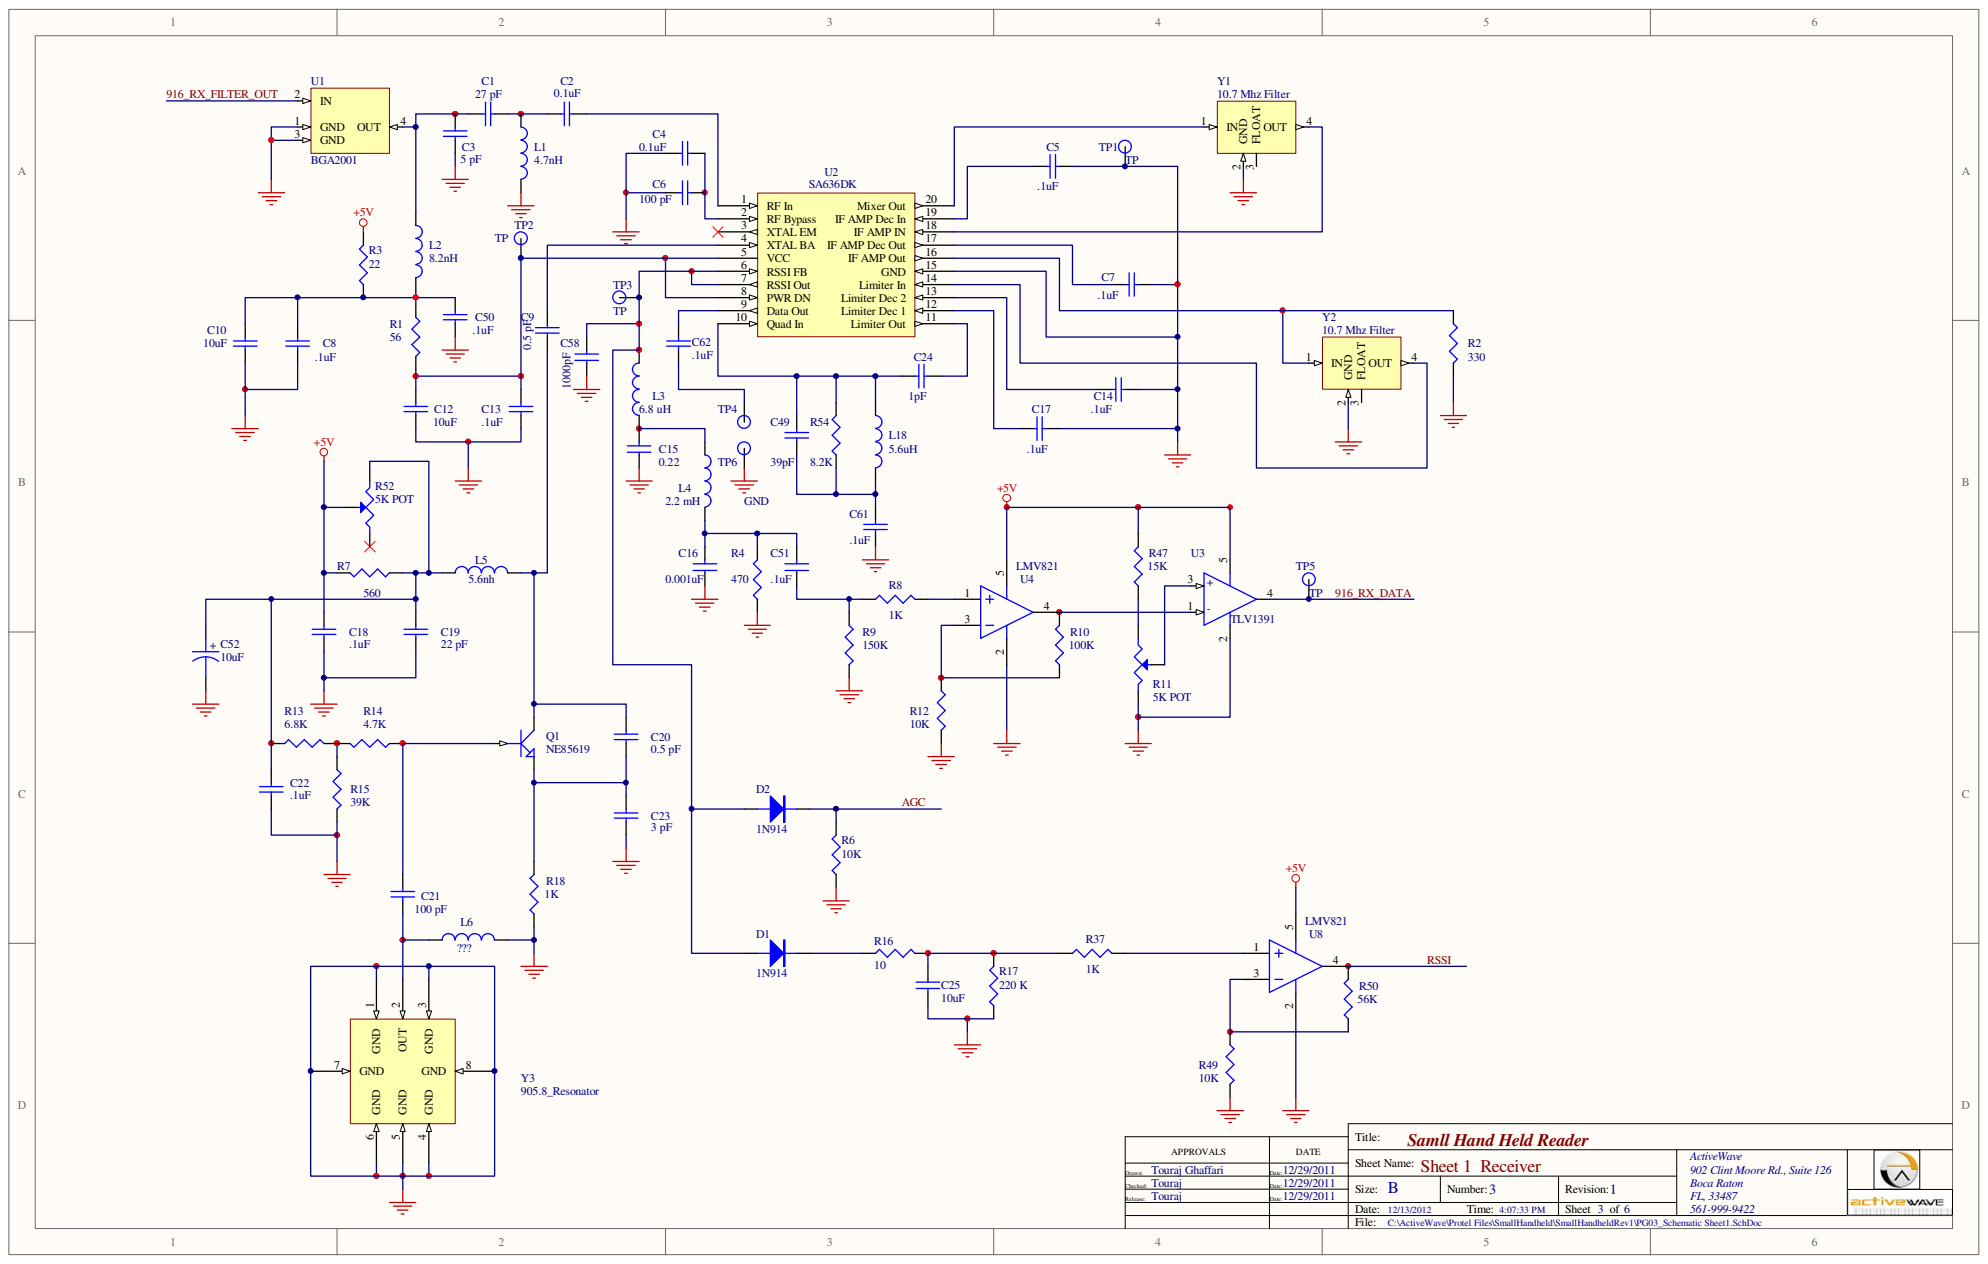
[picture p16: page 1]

Samll Hand Held Reader

Sheet 1 Receiver Sheet Name: 12/29/2011

ActiveWave
902 Clint Moore Rd., Suite 126
Boca Raton

C:\ActiveWave\Protel Files\SmallHandheld\SmallHandheldRev1\PG03_Schematic Sheet1.SchDoc

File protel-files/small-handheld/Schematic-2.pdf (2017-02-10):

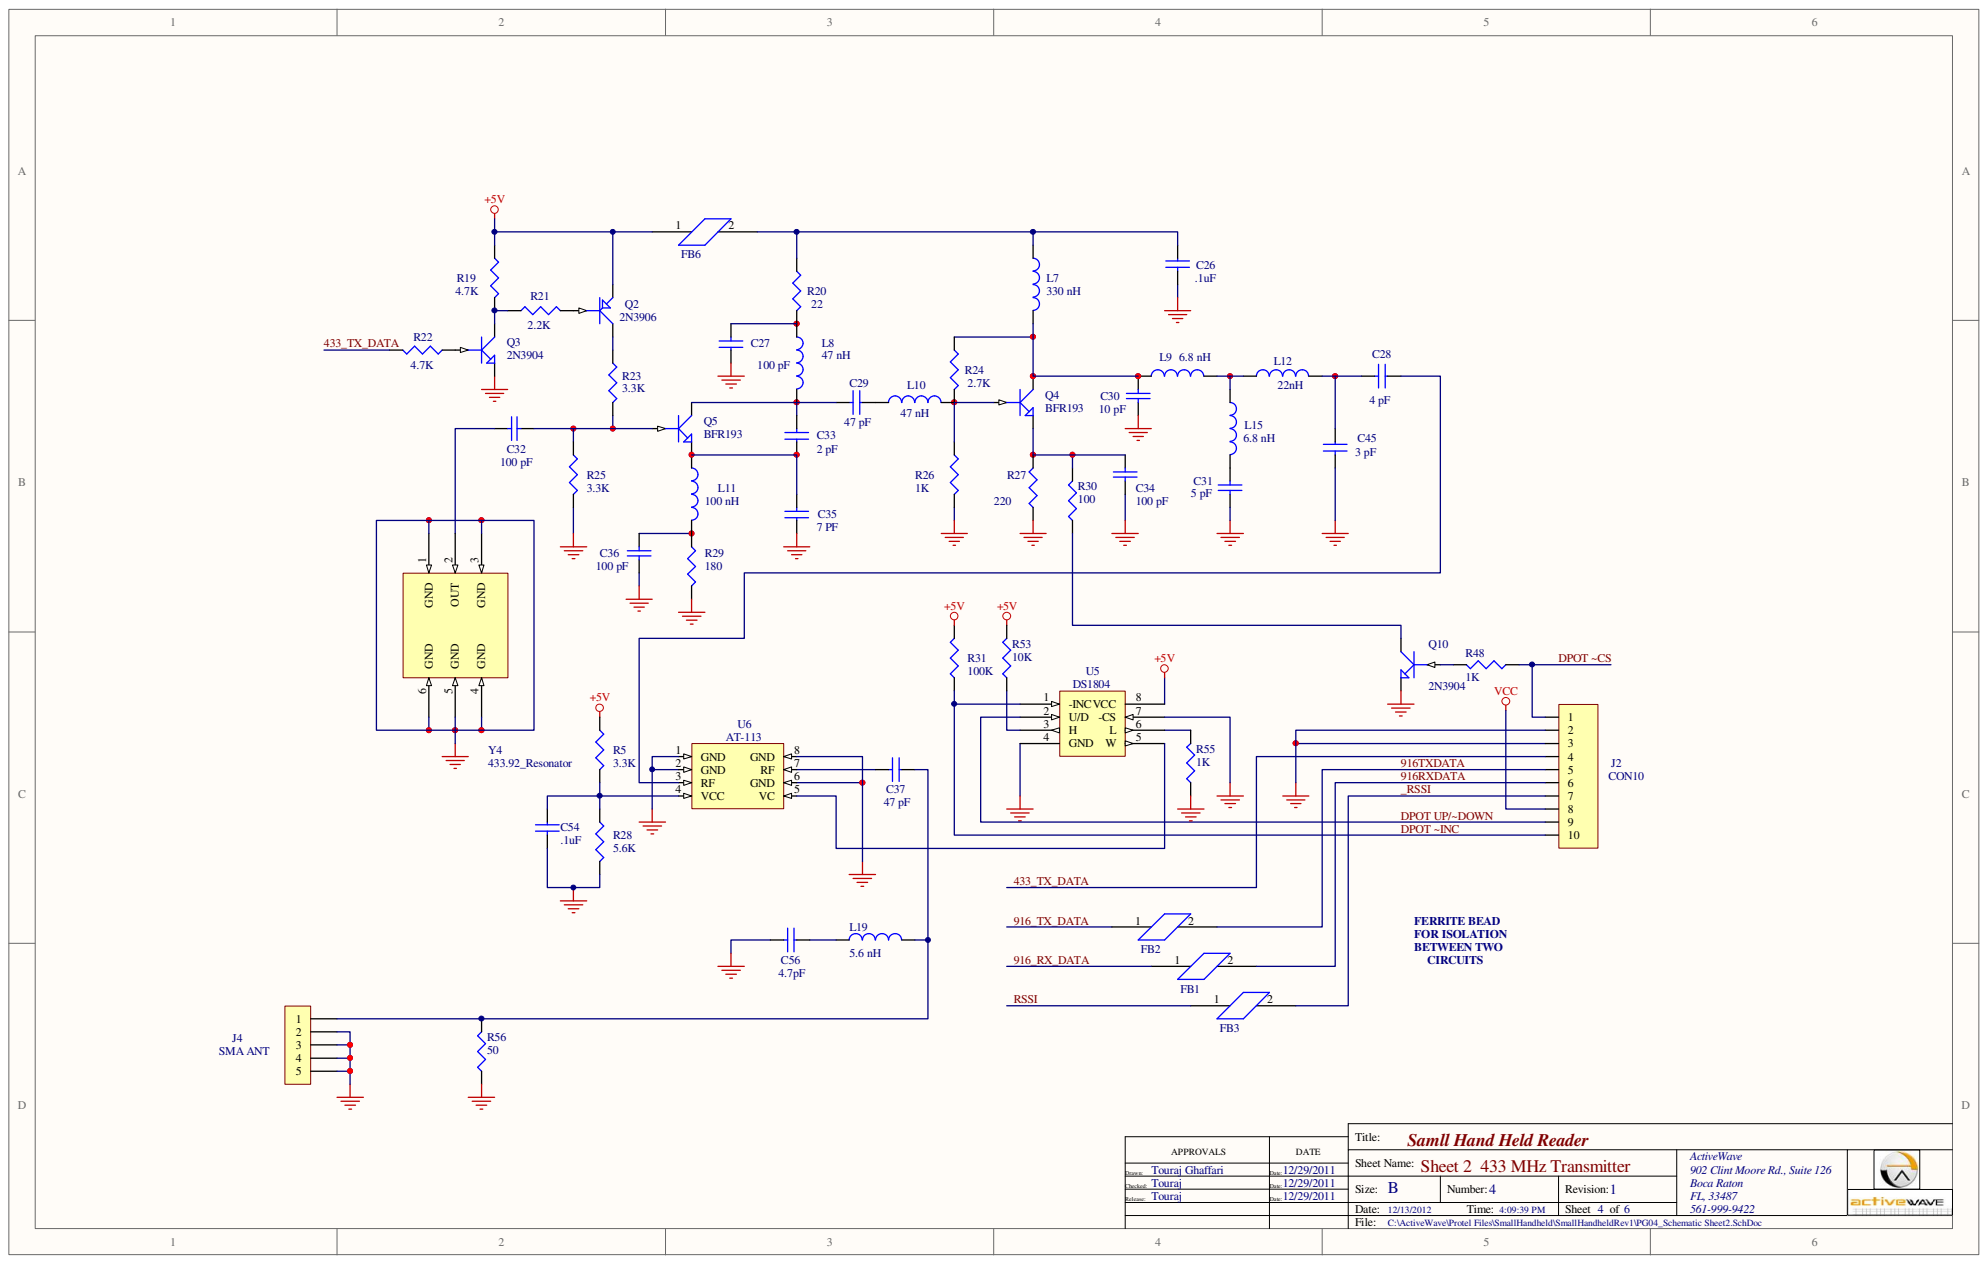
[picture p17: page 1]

Samll Hand Held Reader

Sheet 2 433 MHz Transmitter Sheet Name: 12/29/2011

ActiveWave
902 Clint Moore Rd., Suite 126
Boca Raton

C:\ActiveWave\Protel Files\SmallHandheld\SmallHandheldRev1\PG04_Schematic Sheet2.SchDoc

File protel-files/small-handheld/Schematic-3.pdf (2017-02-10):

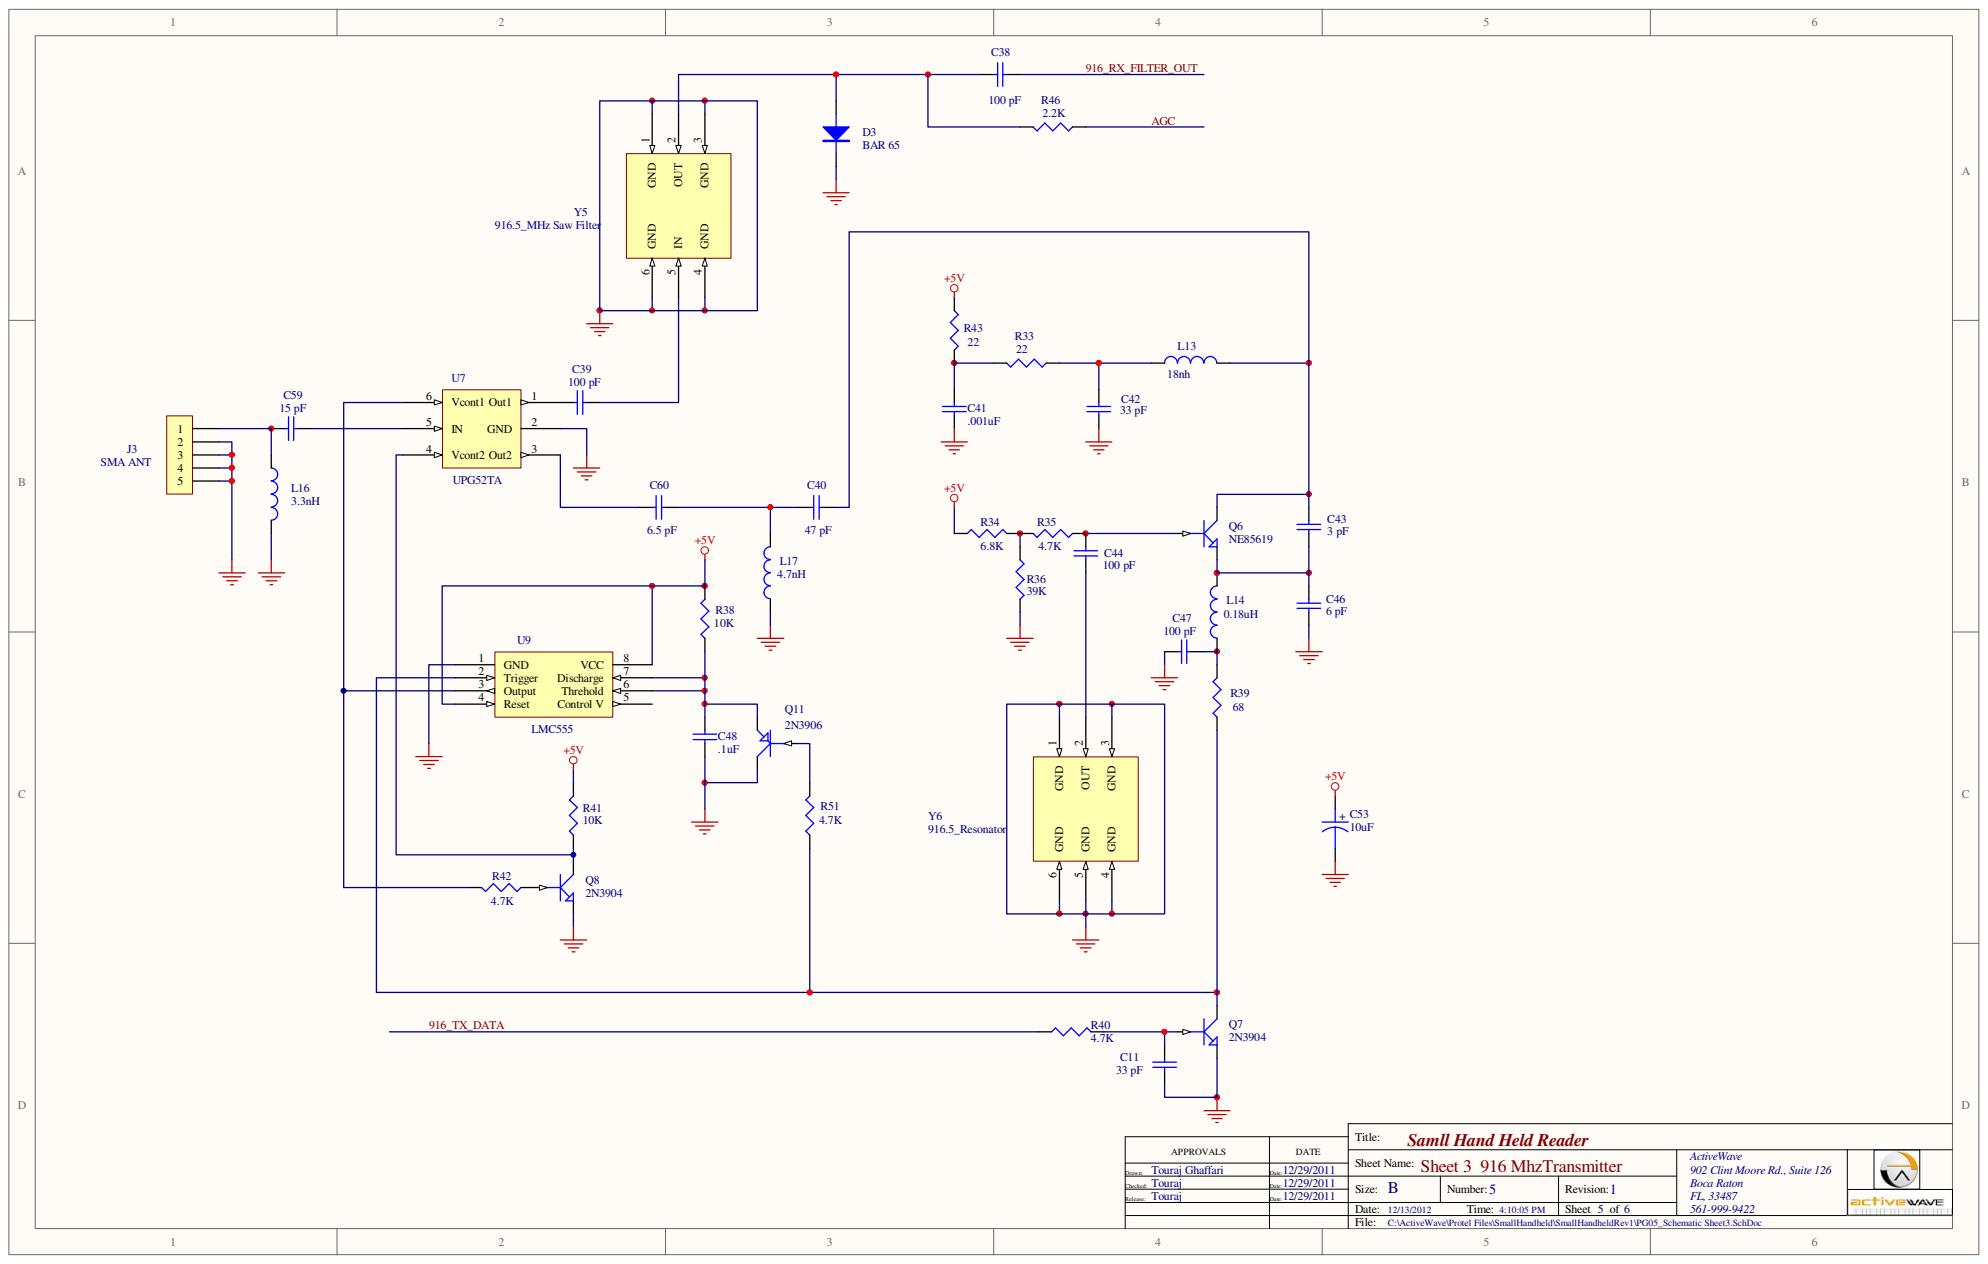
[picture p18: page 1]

Samll Hand Held Reader

Sheet 3 916 MhzTransmitter Sheet Name: 12/29/2011

ActiveWave
902 Clint Moore Rd., Suite 126
Boca Raton

C:\ActiveWave\Protel Files\SmallHandheld\SmallHandheldRev1\PG05_Schematic Sheet3.SchDoc

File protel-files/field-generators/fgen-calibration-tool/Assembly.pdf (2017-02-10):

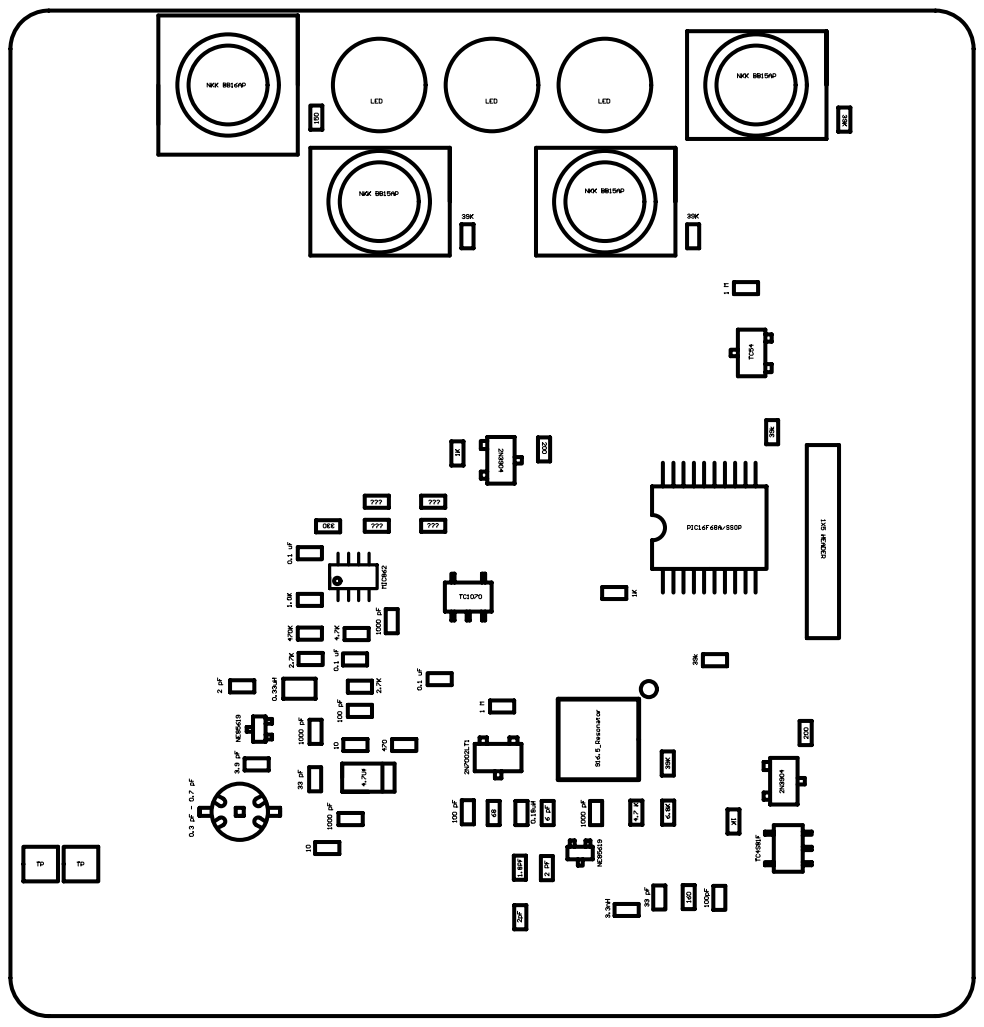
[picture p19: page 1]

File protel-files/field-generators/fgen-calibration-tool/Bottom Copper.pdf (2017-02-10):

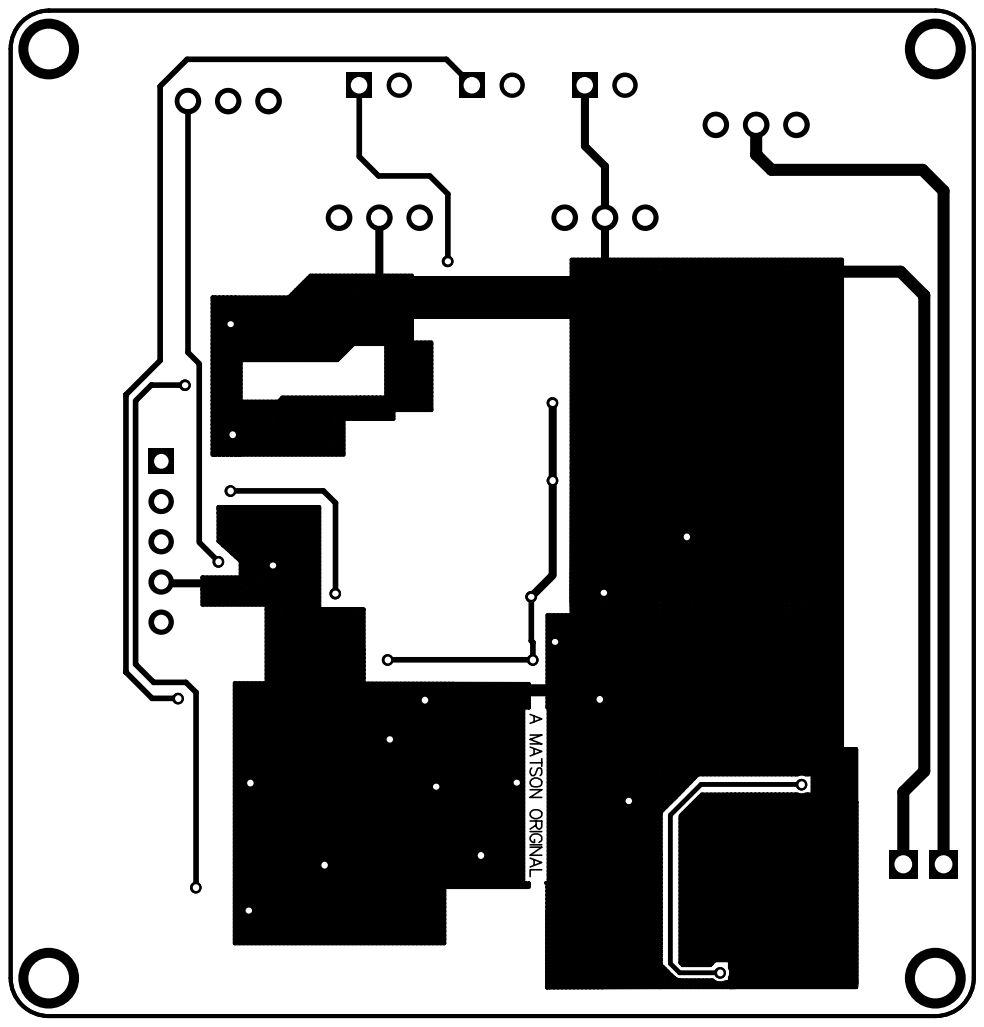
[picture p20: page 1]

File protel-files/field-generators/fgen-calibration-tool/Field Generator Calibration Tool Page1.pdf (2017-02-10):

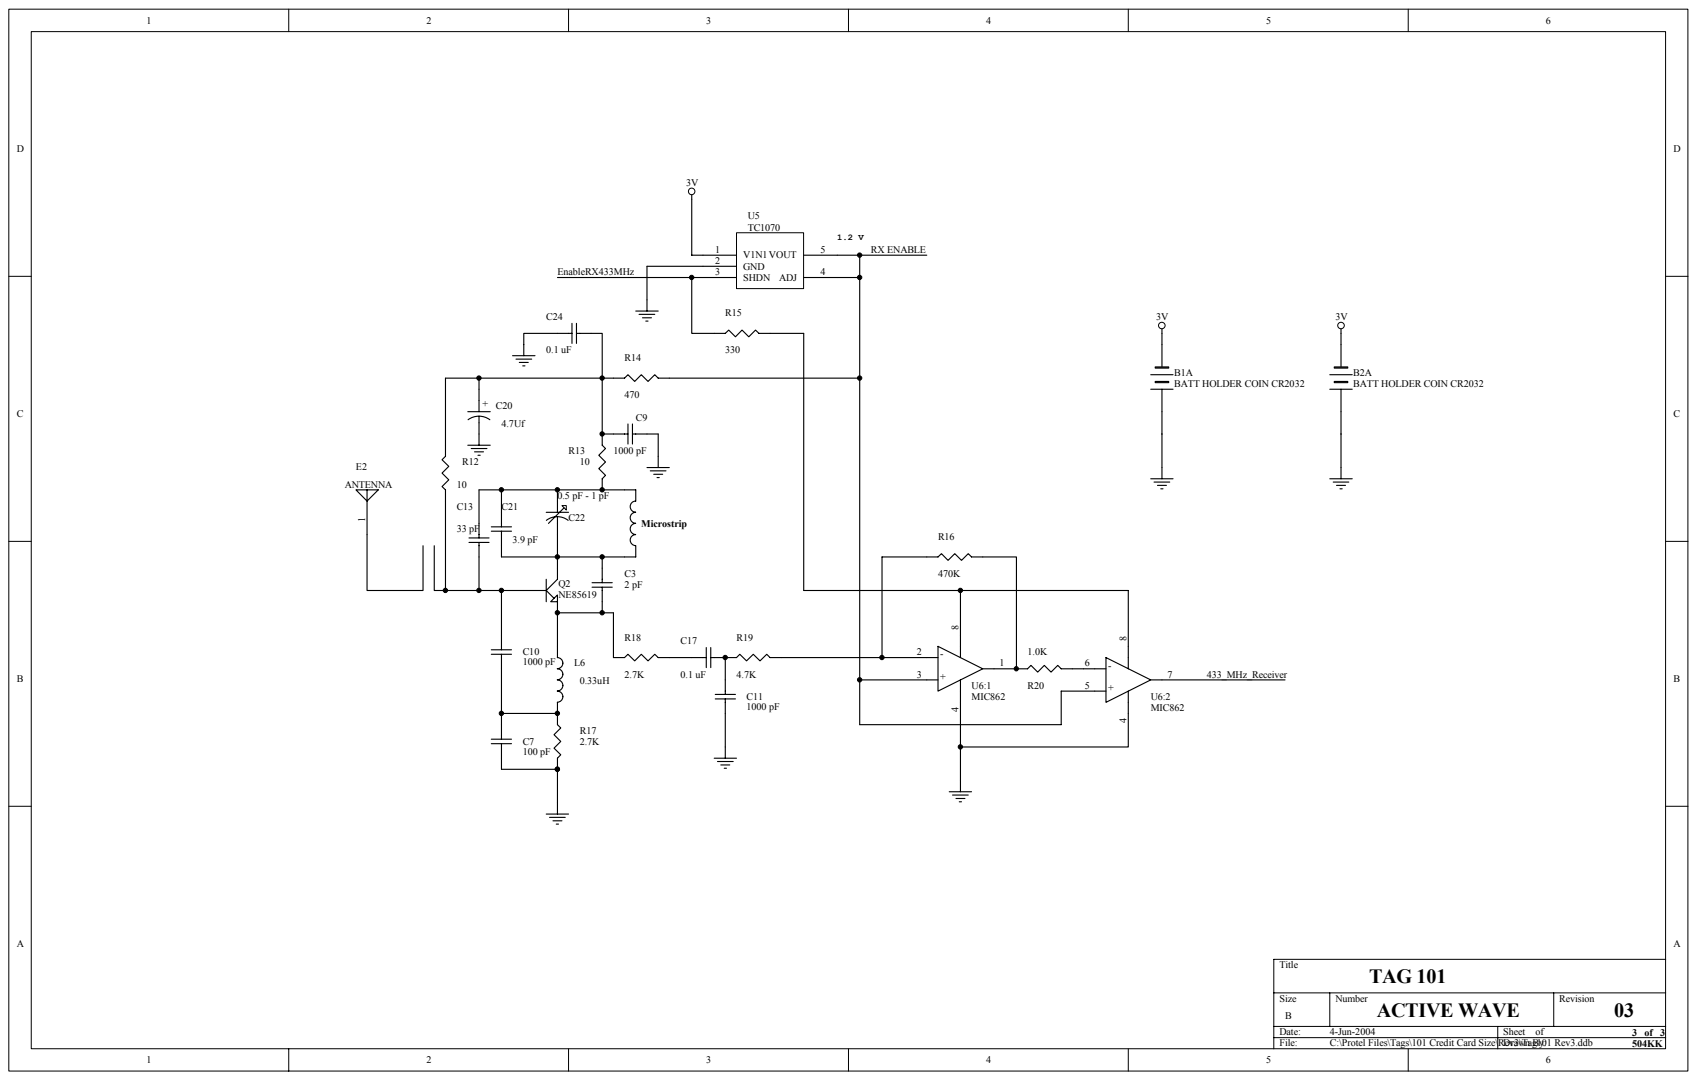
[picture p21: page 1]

Size B | Number ACTIVE WAVE | Revision 03

Date: 4-Jun-2004 | Sheet of 3 of 3
File: C:\Protel Files\Tags\101 Credit Card Size\Rev3\Tag101 Rev3.ddb Drawn By: | 504KK

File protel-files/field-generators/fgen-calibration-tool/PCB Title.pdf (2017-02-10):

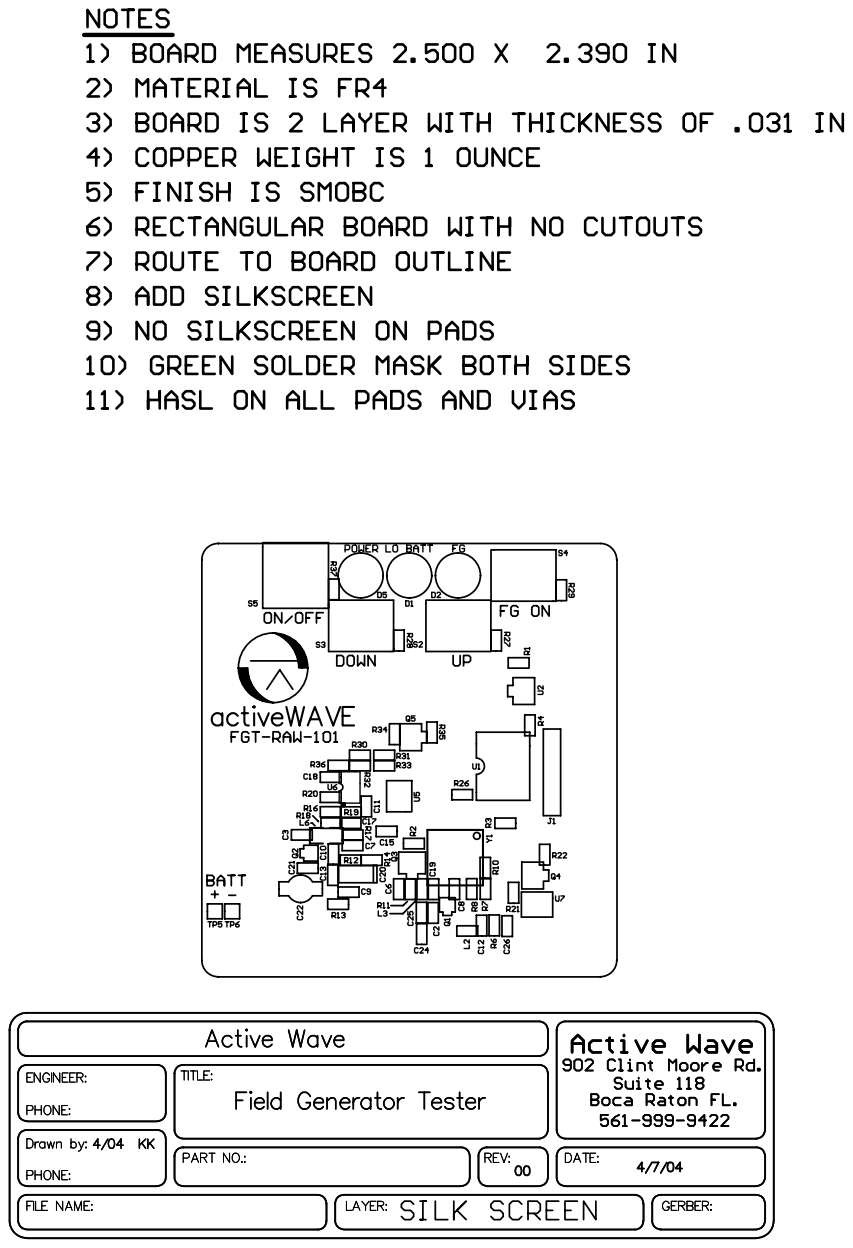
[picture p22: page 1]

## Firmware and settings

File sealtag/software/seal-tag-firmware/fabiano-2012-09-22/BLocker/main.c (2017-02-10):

/*******************************************************************************
* @file     main.c
* @author   imoware
* @version  V3.5.0
* @date     04/13/12
********************************************************************************
* @version history    Description
* ----------------    -----------
* v2.5.0              LSI Clock Enable for RTC (deprecated with 2.7 release)
* v2.6.0              LSI Clock Calibration (deprecated with 2.7 release)
* v2.7.0              LSE Clock Enable for RTC
* v2.8.0              (1) Tag Version, (2) Last Packet Reserved
* v3.0.0              Tamper Switch Debounce Handler
* v3.1.0              Tamper Switch Debounce Handler WITHOUT Timer2
* v3.2.0              Battery Low Voltage History is Updated when Timer is on only
* v3.3.0              on/off
* v3.4.0              Corrected command handling for Factory Reset,
*                     Corrected interrupt handling for Band tamper,
*                     Added check for I2C writes,
*                     Added check for RTC configuration/reads
* v3.5.0              Set low battery level detection to 2.26V,
*                     Prevent multiple Start/Stop Timer commands to be invoked.
*******************************************************************************/

#include "blocker_services.h"
#include "stm8l15x.h"


extern volatile bool rtcConfigured;
extern volatile bool lowVoltBatteryDetected;
extern volatile bool testTamperSwitch;


void main(void)
{
    rtcConfigured = FALSE;
    testTamperSwitch = FALSE;
    lowVoltBatteryDetected = FALSE;

    // initialize Tag i/o's
    initializeTagPins();

    // run Tag Diagnostics
    tagDiagnostics();

    // initialize Tag EEPROM
    initializeTagEE();

    // tag is ready for host operations...
    while (TRUE)
    {
#ifndef DEBUG
        halt();
#else
        delay(8000);
#endif
    }
}
/*************************** END OF FILE **************************************/

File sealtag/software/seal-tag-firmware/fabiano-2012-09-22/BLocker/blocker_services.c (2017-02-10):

/*******************************************************************************
* @file     blocker_services.c
* @author   imoware
* @version  V3.8.0
* @date     09/21/12
********************************************************************************
* @version history    Description
* ----------------    -----------
* v2.5.0              LSI Clock Enable for RTC (deprecated with 2.7 release)
* v2.6.0              LSI Clock Calibration (deprecated with 2.7 release)
* v2.7.0              LSE Clock Enable for RTC
* v2.8.0              (1) Tag Version, (2) Last Packet Reserved
* v3.0.0              Tamper Switch Debounce Handler
* v3.1.0              Tamper Switch Debounce Handler WITHOUT Timer2
* v3.2.0              Battery Low Voltage History is Updated when Timer is on only
* v3.3.0              on/off
* v3.4.0              Corrected command handling for Factory Reset,
*                     Corrected interrupt handling for Band tamper,
*                     Added check for I2C writes,
*                     Added check for RTC configuration/reads
* v3.5.0              Set low battery level detection to 2.26V,
*                     Prevent multiple Start/Stop Timer commands to be invoked.
* v3.6.0              Fixed I2C initialization to delay communication for 84ms
*                     to allow power to stabilize.
* v3.7.0              Prevent factory reset when RTC is running.
* v3.8.0              Added serial number to STM8 EEPROM.
*******************************************************************************/
#include "blocker_services.h"
#include "clock.h"
#include "i2c_ee.h"
#include "band.h"
#include "battery.h"
#include "led.h"
#include "rf.h"
#include "platform.h"
#include <stdio.h>

const uint16_t commandAddress 	        = 0x0000;
const uint16_t commandStatusAddress 	= 0x0001;
const uint16_t tagVersionAddress 	    = 0x0013;
const uint16_t interruptStatusAddress	= 0x0016;
const uint16_t batteryVoltageAddress 	= 0x0017;
const uint16_t histPacketAddress	    = 0x0004;
const uint16_t histPacketNumberAddress  = 0x0006;
const uint16_t empIdAddress 	  	    = 0x0010;
const uint16_t reservedTestAddress      = 0x0015;

uint8_t histPacket[2] = {0x00, 0x00};
uint8_t histPacketNumber[2] = {0x00, 0x00};

volatile bool rtcConfigured = FALSE;
volatile bool historyRead = FALSE;
volatile bool testTamperSwitch = FALSE;
volatile bool lowVoltBatteryDetected = FALSE;
volatile uint16_t timerTick = 0;

typedef  struct  serial_number {
    unsigned char  Hdr[2];
    unsigned char  SerialID[4];
} SERIAL_NUMBER;

__eeprom __no_init const SERIAL_NUMBER eSerial;

void tamperIRQHandler()
{
    bool updateHistory = TRUE;
    bool bandOpen = FALSE;
    uint8_t empId[2] = {0x00, 0x00};

    if (rtcConfigured == FALSE)
    {
        if (testTamperSwitch == FALSE)
            return;
    }

    if (testTamperSwitch == TRUE)
        updateHistory = FALSE;
    else
        updateHistory = TRUE;

    if (Band_GetState() == OPEN)
    {
        bandOpen = Band_IsOpen();
        if (bandOpen == TRUE)
        {
            i2cPowerOn();
            updateInterruptStatus(IS_TAMPER_BAND_OPENED, updateHistory);
        }
    }
    else
    {
        updateInterruptStatus(IS_TAMPER_BAND_CLOSED, updateHistory);
    }

    if ((testTamperSwitch == FALSE) && (bandOpen == TRUE))
    {
        readRTC();
        updateCommandHistory(TAMPER_INTERRUPT);
        readEmployeeEE(empId);
        updateEmployeeHistory(empId);
        setNextPacketHistory();
        stopTimers();
        rtcConfigured = FALSE;
        i2cPowerOff();
    }
}

void batteryVoltageIRQHandler()
{
    if (Battery_HasLowLevel() == TRUE)
    {
        lowVoltBatteryDetected = TRUE;
        updateBatteryVoltage(BATTERY_VOLT_LOW);
        if (rtcConfigured == TRUE)
        {
            readRTC();
            updateCommandHistory(LOW_BATTERY_INTERRUPT);
            setNextPacketHistory();
        }
    }
    else
    {
        lowVoltBatteryDetected = FALSE;
        updateBatteryVoltage(BATTERY_VOLT_NORMAL);
    }
}

void rfCommandIRQHandler()
{
    ErrorCode status;
    uint8_t commandStatus;

    status = readCommandStatus(&commandStatus);
    if (status != ERROR_NONE)
        return;

    if ((commandStatus == COMMAND_STATUS_BUSY))
    {
        setCommandStatus(COMMAND_STATUS_BUSY_ACK, FALSE);
        return;
    }

    if ((commandStatus == COMMAND_STATUS_BUSY_ACK))
        return;

    if (commandStatus == COMMAND_STATUS_RECEIVED)
    {
        status = setCommandStatus(COMMAND_STATUS_RUNNING, FALSE);
        if (status != ERROR_NONE)
            return;

        updateInterruptStatus((Band_GetState() == OPEN) ? IS_TAMPER_BAND_OPENED : IS_TAMPER_BAND_CLOSED, FALSE);
        commandHandler();
    }
    else
    {
        setCommandStatus(ERROR_INVALID_COMMAND_STATUS, TRUE);
    }
}
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

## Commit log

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2017-02-10 rev1 - BOM files
    [2012 tax calculation.xlsx, Bill-6272006.xls, Bom Cost Matrix.xls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]
2017-02-10 rev1 - Software
    [AWI_ProgStation.obj, AWSocketUnit.obj, AboutUnit.obj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]
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2017-02-10 rev1 - sealTag
    [DRILL.DRL, L1.GBR, L2.GBR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]
2017-02-10 rev1 - Protel Files first commit
    The first of several commits including Protel Files
    [101_to_9999_Pin.PcbLib, 15_to_28_Pin.PcbLib, 15_to_28_PinB.PcbLib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]
2017-02-10 rev1 - Protel Files second commit
    [BOM for TAG1001 Rev4.xls, Backup of Mid Layer and Bottom Tag103.Sch, Backup of SCHEMATIC1.cfg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]
2017-02-10 rev1 - Protel Files fourth commit
    Field Generators
    [AdjTool.dsn, Backup of 433Mhz Xmit.SCH, Backup of 433Mhz Xmit.Sch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]
2017-02-10 rev1 - Protel Files fifth commit
    Part of the files related to readers
    [2t-Handheld.PrjPCB, Analog1.schdoc, Analog2.schdoc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]
2017-02-10 rev1 Protel Files - sixth commit
    Handheld Reader
    [Backup of BOM for Handheld Reader Analog5.csv, Backup of BOM for Handheld Reader Analog6.csv, Backup of BOM for Handheld Reader Digital5.csv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]
2017-02-10 rev1 Protel Files - seventh commit
    RS232 Reader
    [433Mhz Xmit.Sch, BOM for Tag104 Rev8.csv, BOM for Tag104 Rev8.xls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]
2017-02-10 rev1 - eighth commit
    Reader 103
    [1803280.dxf, Backup of Copy of BOM for Reader 103.csv, Backup of Reader 103 Rev1.sch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]
2017-02-10 rev1 - ninth commit
    PCMCIA Reader
    [Backup of BOM for Blind Vias PCMCIA Card3.csv, Backup of PCMCIA Card with Level Shifter3.CSV, Backup of PCMCIA Card with Level Shifter3.XLS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]
2026-10-27 the pre-commit hook's executable bit — stored 644 by the Windows round; a 644 hook is ignored on the Mac (#5)
2026-10-27 Story 1.1.2: the archive restructure — the 2018 tree leaves the current tree, the dedication stays (#7)
    * Story 1.1.2 (1/7): Where this is going, Contributor Covenant 3.0, the sparse view retired; api, bom-files, documentation, patents, presentations, software and the small protel-files folders leave t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
    * Story 1.1.2 (2/7): sealtag leaves the current tree
    * Story 1.1.2 (3/7): protel-files/field-generators and the smaller reader folders leave the current tree
    * Story 1.1.2 (4/7): protel-files/tags leaves the current tree
    * Story 1.1.2 (5/7): protel-files/reader/reader-rs232-new-case and reader-103 (but its two DXF drawings) leave the current tree
    * Story 1.1.2 (6/7): the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
2026-10-27 Story 1.1.4: the licence lane before any copy — THIRD_PARTY_NOTICES.md and check-licenses.mjs in test; the 1.1 build-inputs tooth's regex corrected (#8)
2026-10-27 reference-check: a missing copy-only file comes from a machine whose folder verifies — copy, never move (#9)
2026-10-27 Session notes: wrap up (2026-10-27 — Sprint 1 legs 1–3: the corpus, the restructure, the licence lane (Stories 1.1.3, 1.1.2, 1.1.4)) (#10)
2026-10-27 Story 1.1.5: the second machine — its clone and its reference folder, verified (#11)
    The tick quotes the second machine's verify run (291 rows, every pin
    matched, exit 0) and its git config user.email read-back ending
    @users.noreply.github.com (spec D8). The 1.1 manifest is re-affirmed by
    a reviewedFor entry; no run, expect or prose changed.
2026-10-27 Session notes: wrap up (2026-10-27 — Story 1.1.5: the second machine's clone and reference folder) (#12)
2026-10-27 Story 2.1.1: the requirements, from the three scenarios, with numbers — Omid's answers recorded (#14)
    * Story 2.1.1: the requirements drafted — 27 numbers across the three scenarios, each with its reasoning, before they are put to Omid
    * Story 2.1.1: Omid's answers recorded — 24 as recommended; [3] 1,000 tags/s per reader, [12] 100 tags/s, [13] a move shown within 5 s, set by him
    * Story 2.1.1: ticked in the plan; 2.1.json kept in lockstep (one reviewedFor entry, reviewed 2026-10-27)
    ---------
2026-10-27 Session notes: wrap up (2026-10-27 — Story 2.1.1: the requirements, with numbers (Sprint 1 leg 4)) (#15)
2026-10-27 Story 2.1.2: how the original worked, from its own records — three corrections to the spec found (#16)
    * Story 2.1.2: how the original worked, from its own records
    docs/study/original-system.md describes the 2001-2013 system read at the
    tag activewave-2018: the radio link, anti-collision, zones, alarms and I/O,
    and each milestone device's hardware, every claim cited to its file or
    marked INFERRED. The research log's section 1 points at it.
    * Story 2.1.2: tick the plan; the 2.1 manifest's reviewedFor in lockstep (#16)
    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
2026-10-27 Sprint 1: stamped EXECUTED — the five legs' PRs and shas; review pending (#17)
2026-10-27 Session notes: wrap up (2026-10-27 — Story 2.1.2: how the original worked (Sprint 1 leg 5); Sprint 1 EXECUTED) (#18)
2026-10-27 Session notes: wrap up (2026-10-27 — Story 2.1.2: how the original worked (Sprint 1 leg 5); Sprint 1 EXECUTED) (#20)
2026-10-27 Session notes: wrap up (2026-10-27 — Story 1.1.6: the Epic 1.1 close (Initiative 1 archived)) (#21)
2026-10-27 Sprint 1 review: every leg PASS; Epic 2.1's forward work written into its stories; the rebuild-spec-approved tooth fixed (#23)
    * Sprint 1 review: every leg PASS; Epic 2.1's forward work written into its stories; the rebuild-spec-approved tooth fixed
    The Reviewed record replaces the archive's Review PENDING line and refreshes its two restated copies (Story 1.1.6's Outcome, the Epic 1.1 evidence bullet). On Air Traffic Control's grant: one dated Context sentence each on Stories 2.1.3, 2.1.4, 2.1.5 and 2.1.7, and docs/close/2.1.json's rebuild-spec-approved run line corrected (its born regex failed to parse on every input), with one reviewedFor entry.
    * Sprint 1 review: name the review PR, #23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
2026-10-27 Session notes: wrap up (2026-10-27 — the Sprint 1 reviewer pass (every leg PASS)) (#25)
2026-10-27 Session notes: wrap up (2026-10-27 — the Sprint 2 proposal (approved, four legs)) (#27)
2026-10-27 Pin line endings: LF in the repo and in every checkout; the originals on main are never rewritten (#28)
    Adds a root .gitattributes in the fleet's shape (* text=auto eol=lf; md, mjs,
    json, tsv and yml pinned LF; binaries never converted). The one difference:
    license and _assets/, the 2018 files unchanged since the tag activewave-2018,
    are -text, so git never rewrites their bytes. Every stored blob was LF already,
    so the pin changes no stored byte. Cites hub #4452.
2026-10-27 Session notes: wrap up (2026-10-27 — Sprint 2 leg 1 (Story 2.1.9) and the line-ending pin) (#30)
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2026-10-28 Sprint 2 review: every leg PASS; six findings (three fixed here, the studies' fixes routed to Sprint 3); Omid's HF footprint ruling (#41)
    * Sprint 2 review: every leg PASS; the block archived with its Reviewed record; Omid's HF footprint ruling and the studies' forward work written into Stories 2.1.6 and 2.1.7
    * Sprint 2 review: the record names its PR (#41); the subshell-warning count
    * Sprint 2 review: the subshell seat worded without a running count
    * Sprint 2 review: the record's verdict counts which findings are fixed here and which are routed
    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
2026-10-28 Story 2.1.10: the Sprint 2 review's fixes to the three studies (Sprint 3 leg 1) (#45)
    * Story 2.1.10: the Sprint 2 review's fixes in the three studies
    Findings 1-5 and the five nits. Finding 4's mechanism (the neighbours named) in radio-and-location.md, its listening cost and finding 3's eight averages carried into parts-and-toolchains.md's battery figures; dated pointer lines in requirements.md; the research log's entry; Story 2.1.7's HF sentence refreshed.
    * Story 2.1.10 ticked; docs/close/2.1.json in lockstep; the friction log's leg 1 section
    * Story 2.1.10: two cross-references refreshed by the Item-8 grep; the friction log's blocked-chain seat
    ---------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
2026-10-28 Session notes: wrap up (2026-10-28 — Sprint 3 leg 1 (Story 2.1.10, the studies' review fixes)) (#47)
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2026-10-28 Story 2.1.11: the reference check names the fetch route for the study's sources (Sprint 3 leg 3) (#50)
    * Story 2.1.11: the reference check names the fetch route for a missing sources/ file or folder
    A missing sources/ file now names its row's URL, the rule that it counts only once its sha256 matches the pin, and the copy as the alternative; an absent sources/ folder names the same route and lists each file with its URL. Every other folder keeps its copy-only line, and a sources/ row with no URL keeps it too. The tool still never fetches a file row (Sprint 3's D11). Three tests pin the cases; the first two were red against main's script.
    * Story 2.1.11: reference-repos.md's message list nam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
2026-10-29 Sprint 4 proposal: figures that hold for the sitting (2.1.12, 2.1.14, 2.1.13); Story 2.1.12 split, Story 2.1.14 born (docs only) (#55)
    * Sprint 4 proposal: figures that hold for the sitting (2.1.12, 2.1.14, 2.1.13); Story 2.1.12 split, Story 2.1.14 born
    Three legs, serial: the listening window (Story 2.1.12, narrowed to the Sprint 3 review's finding 1, finding 6 and the anti-collision nit), the tiers' fixes (Story 2.1.14, born from 2.1.12's findings 2-5 and four nits by the session-fit test), and the reference folder's sources/ route (Story 2.1.13). The manifest moves in lockstep: 2.1.14 joins stories, sprint3-review-fixes narrows with its story, sprint3-review-tier-fixes is born. Approval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
2026-10-29 Story 2.1.12: the listening window — the beacon skipped on most listens, every battery figure re-priced and D2 re-run; the conference's block computed; GNU make named among the tools not cited (docs 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
    * Story 2.1.12: the listening window — the beacon skipped on most listens, every battery figure re-priced, D2 re-run; the conference's block computed; GNU make named among the tools not cited (docs only)
    * Sprint 4 friction log: leg 1's section (Story 2.1.12) (docs only)
    * Story 2.1.12: tick in place, with its reviewedFor line in docs/close/2.1.json (docs only)
    * Sprint 4 friction log: leg 1's last two guard events (docs only)
    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
2026-10-29 Story 2.1.13: the reference folder gives the sources/ route — the stub names sources/, a drifted sources/ file's line names the newer revision, the reading rules name pdftotext (Sprint 4 leg 3) (#62)
    * Story 2.1.13: the reference folder gives the sources/ route — the stub names sources/, a drifted sources/ file's line names the newer revision and the copy route, the reading rules name pdftotext -layout
    * Story 2.1.13: tick, the manifest's reviewedFor line, and the friction log's leg 3 section
    * Story 2.1.13: rule 8 says pdftotext writes Latin-1 without -enc UTF-8 (measured by byte count); the friction log's R1 and its seat
    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
2026-10-30 Story 2.1.15: the warehouse at a Reader's edge, and the figures beside it (docs only) (#67)
    * Story 2.1.15: the radio study states a Reader's edge, the count's bound, the frame's other users and a lost tag's bound
    * Story 2.1.15: § [27] priced for every bay, a Reader's edge included, with the count at its bound; GNU make's three resets
    * Story 2.1.15: the VNA's box, the currency, the three-board parenthesis, the burst row's citation, and [27]'s dated pointer line
    * Story 2.1.15: keep the sitting's list as Story 2.1.7 names it
    * Story 2.1.15: tick, and the manifest in lockstep
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2026-10-31 Close out Epic 2.1: the design study closed, Initiative 2 archived, the build filed as Initiatives 3-7 (#98)
    * Epic 2.1 close: the corrections its evidence names
    original-system.md gains the citations Omid's verdict on original-claims-cited asked for (pass with correction): the Tag 102 tilt switch, the BOM readme, the sources of "LF RX DATA" and the TLE4913, and the website captures behind its claims, with a dated note; no claim changed. radio-and-location.md and parts-and-toolchains.md gain a dated line: the decision sitting read both FCC grants (rebuild spec section 5.2, #83). The README and CLAUDE.md say the design study decided.
    * Close out Epic 2.1: Initiative 2 archived whole, the bu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
